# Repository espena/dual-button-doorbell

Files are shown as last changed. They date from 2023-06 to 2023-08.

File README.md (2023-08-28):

# Dual-button doorbell

*V. 1.2*

A door bell that simply does more. Configurable with alarms, different sounds for the two buttons, bedtime LED indicator and timed notifications on specific days / hours. With audible 4Ω loudspeaker driven by a class D 3.2 W amplifier.

The project is described on my [home page](https://espenandersen.no/dual-button-doorbell/).

## Features

- Two-button interface with led indicators
- Personalized doorbell sound from custom wav files
- Cron calendar for scheduling sounds down to one second resolution
- SD card support for storing audio files and configuration
- WiFi interface with integrated antenna
- MQTT support for smart home integration and push notifications
- Battery backed-up real-time clock
- Time automatically set over the network using NTP
- Can be configured to use custom time zones
- Silent mode with alternate bell sounds during night hours
- Relay for triggering external doorbell along with custom sound
- Accepts AC or DC power input from existing doorbell power supplies

## Circuit

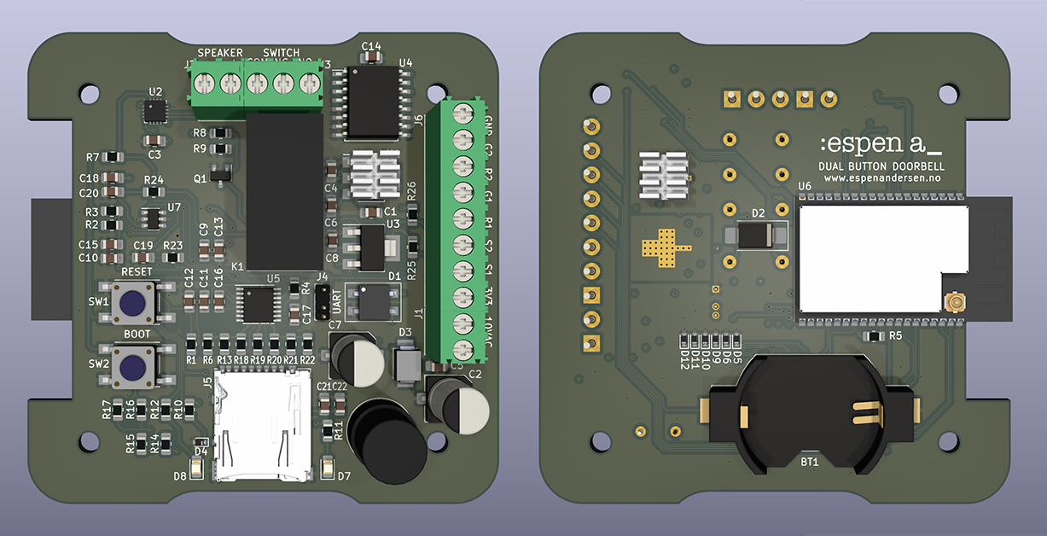
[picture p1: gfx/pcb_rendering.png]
PCB layout PCB rendering


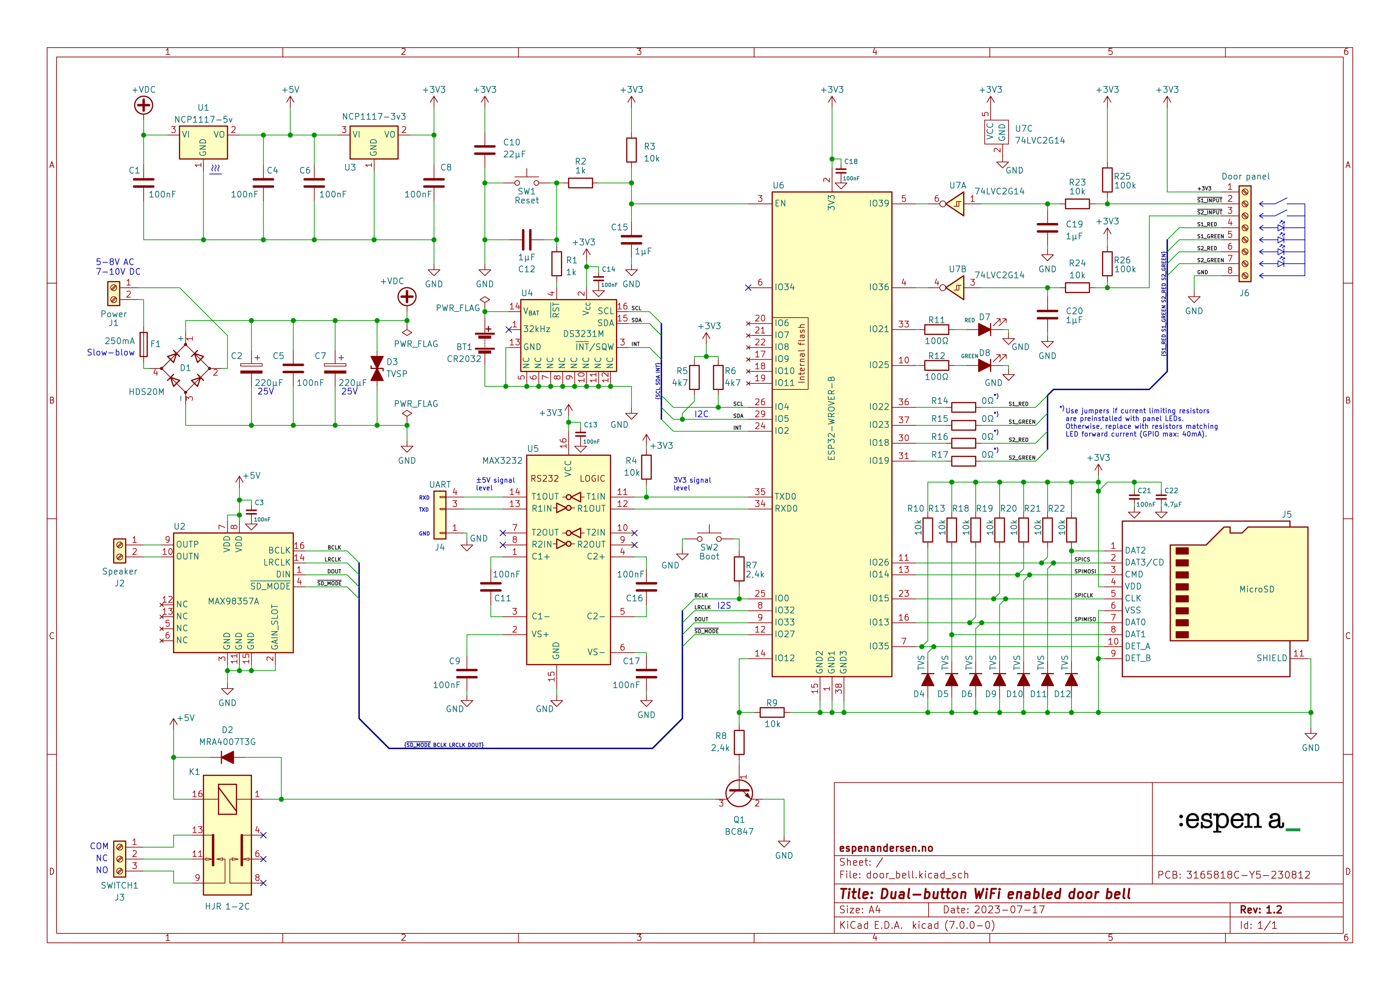
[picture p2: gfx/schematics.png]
Circuit schematics


Custom symbols, footprints and 3D models can be found in [espena/kicad-libs](https://github.com/espena/kicad-libs) whenever they're ready.

## Firmware

Written in C/C++ using [FreeRTOS](https://www.freertos.org/) and [ESP-IDF](https://docs.espressif.com/projects/esp-idf/en/latest/esp32/get-started/). Additionally I use the brilliant [ccronexpr](https://github.com/staticlibs/ccronexpr) C library for parsing the cron-alike sound schedule. Source code is located in the [firmware/dual-button-doorbell](firmware/dual-button-doorbell) folder within this repository.

## Configuration

Configuration and assets must be stored on the SD card. See [/firmware/dual-button-doorbell/sdcard](/firmware/dual-button-doorbell/sdcard) for an example configuration.

## Button panel

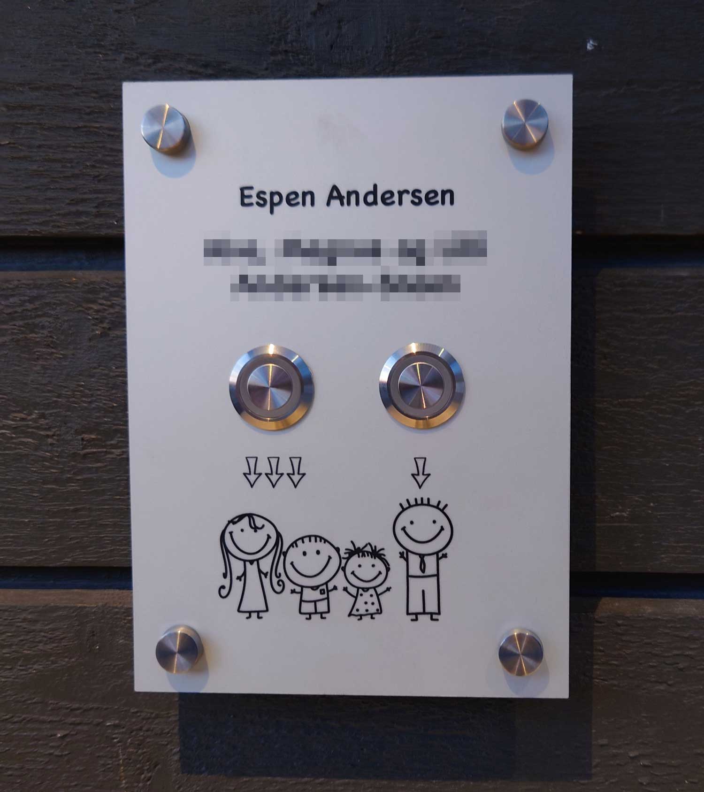
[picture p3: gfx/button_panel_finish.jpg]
Button panel design Button panel finished design


## Panel back side enclosure

```stl
solid Mesh
  facet normal 0.000000 1.000000 0.000000
    outer loop
      vertex 50.000000 30.000000 0.000000
      vertex -50.000000 30.000000 0.000000
      vertex -50.000000 30.000000 19.000000
    endloop
  endfacet
  facet normal 0.000000 1.000000 -0.000000
    outer loop
      vertex 50.000000 30.000000 0.000000
      vertex -50.000000 30.000000 19.000000
      vertex 50.000000 30.000000 19.000000
    endloop
  endfacet
  facet normal -1.000000 -0.000000 0.000000
    outer loop
      vertex -50.000000 30.000000 19.000000
      vertex -50.000000 -30.000000 0.000000
      vertex -50.000000 -30.000000 19.000000
    endloop
  endfacet
  facet normal -1.000000 0.000000 0.000000
    outer loop
      vertex -50.000000 30.000000 0.000000
      vertex -50.000000 -30.000000 0.000000
      vertex -50.000000 30.000000 19.000000
    endloop
  endfacet
  facet normal 1.000000 -0.000000 0.000000
    outer loop
      vertex 50.000000 -30.000000 19.000000
      vertex 50.000000 30.000000 0.000000
      vertex 50.000000 30.000000 19.000000
    endloop
  endfacet
  facet normal 1.000000 0.000000 0.000000
    outer loop
      vertex 50.000000 -30.000000 0.000000
      vertex 50.000000 30.000000 0.000000
      vertex 50.000000 -30.000000 19.000000
    endloop
  endfacet
  facet normal 0.000000 0.000000 -1.000000
    outer loop
      vertex -48.000000 -28.000000 0.000000
      vertex -50.000000 30.000000 0.000000
      vertex -48.000000 28.000000 0.000000
    endloop
  endfacet
  facet normal 0.000000 0.000000 -1.000000
    outer loop
      vertex -50.000000 -30.000000 0.000000
      vertex -50.000000 30.000000 0.000000
      vertex -48.000000 -28.000000 0.000000
    endloop
  endfacet
  facet normal 0.000000 0.000000 -1.000000
    outer loop
      vertex -50.000000 -30.000000 0.000000
      vertex 48.000000 -28.000000 0.000000
      vertex 50.000000 -30.000000 0.000000
    endloop
  endfacet
  facet normal 0.000000 -0.000000 -1.000000
    outer loop
      vertex -48.000000 -28.000000 0.000000
      vertex 48.000000 -28.000000 0.000000
      vertex -50.000000 -30.000000 0.000000
    endloop
  endfacet
  facet normal 0.000000 0.000000 -1.000000
    outer loop
      vertex 48.000000 28.000000 0.000000
      vertex 50.000000 30.000000 0.000000
      vertex 48.000000 -28.000000 0.000000
    endloop
  endfacet
  facet normal 0.000000 0.000000 -1.000000
    outer loop
      vertex 48.000000 -28.000000 0.000000
      vertex 50.000000 30.000000 0.000000
      vertex 50.000000 -30.000000 0.000000
    endloop
  endfacet
  facet normal 0.000000 0.000000 -1.000000
    outer loop
      vertex -50.000000 30.000000 0.000000
      vertex 50.000000 30.000000 0.000000
      vertex -48.000000 28.000000 0.000000
    endloop
  endfacet
  facet normal 0.000000 0.000000 -1.000000
    outer loop
      vertex -48.000000 28.000000 0.000000
      vertex 50.000000 30.000000 0.000000
      vertex 48.000000 28.000000 0.000000
    endloop
  endfacet
  facet normal 0.000000 0.000000 1.000000
    outer loop
      vertex -29.796875 -7.549917 19.000000
      vertex -50.000000 -30.000000 19.000000
      vertex -29.410429 -7.946122 19.000000
    endloop
  endfacet
  facet normal 0.000000 0.000000 1.000000
    outer loop
      vertex -29.004713 -8.322572 19.000000
      vertex -29.410429 -7.946122 19.000000
      vertex -50.000000 -30.000000 19.000000
    endloop
  endfacet
  facet normal 0.000000 0.000000 1.000000
    outer loop
      vertex -30.163094 -7.134943 19.000000
      vertex -50.000000 -30.000000 19.000000
      vertex -29.796875 -7.549917 19.000000
    endloop
  endfacet
  facet normal 0.000000 0.000000 1.000000
    outer loop
      vertex -28.580736 -8.678329 19.000000
      vertex -29.004713 -8.322572 19.000000
      vertex -50.000000 -30.000000 19.000000
    endloop
  endfacet
  facet normal 0.000000 0.000000 1.000000
    outer loop
      vertex -30.508171 -6.702229 19.000000
      vertex -50.000000 -30.000000 19.000000
      vertex -30.163094 -7.134943 19.000000
    endloop
  endfacet
  facet normal 0.000000 0.000000 1.000000
    outer loop
      vertex -28.139555 -9.012512 19.000000
      vertex -28.580736 -8.678329 19.000000
      vertex -50.000000 -30.000000 19.000000
    endloop
  endfacet
  facet normal 0.000000 0.000000 1.000000
    outer loop
      vertex -30.831251 -6.252852 19.000000
      vertex -50.000000 -30.000000 19.000000
      vertex -30.508171 -6.702229 19.000000
    endloop
  endfacet
  facet normal 0.000000 0.000000 1.000000
    outer loop
      vertex -27.682264 -9.324287 19.000000
      vertex -28.139555 -9.012512 19.000000
      vertex -50.000000 -30.000000 19.000000
    endloop
  endfacet
  facet normal 0.000000 0.000000 1.000000
    outer loop
      vertex -31.131529 -5.787931 19.000000
      vertex -50.000000 -30.000000 19.000000
      vertex -30.831251 -6.252852 19.000000
    endloop
  endfacet
  facet normal 0.000000 0.000000 1.000000
    outer loop
      vertex -27.209999 -9.612882 19.000000
      vertex -27.682264 -9.324287 19.000000
      vertex -50.000000 -30.000000 19.000000
    endloop
  endfacet
  facet normal 0.000000 0.000000 1.000000
    outer loop
      vertex -31.408260 -5.308619 19.000000
      vertex -50.000000 -30.000000 19.000000
      vertex -31.131529 -5.787931 19.000000
    endloop
  endfacet
  facet normal 0.000000 0.000000 1.000000
    outer loop
      vertex -26.723938 -9.877577 19.000000
      vertex -27.209999 -9.612882 19.000000
      vertex -50.000000 -30.000000 19.000000
    endloop
  endfacet
  facet normal 0.000000 0.000000 1.000000
    outer loop
      vertex -31.660755 -4.816110 19.000000
      vertex -50.000000 -30.000000 19.000000
      vertex -31.408260 -5.308619 19.000000
    endloop
  endfacet
  facet normal 0.000000 0.000000 1.000000
    outer loop
      vertex -26.225286 -10.117715 19.000000
      vertex -26.723938 -9.877577 19.000000
      vertex -50.000000 -30.000000 19.000000
    endloop
  endfacet
  facet normal 0.000000 0.000000 1.000000
    outer loop
      vertex -31.888386 -4.311626 19.000000
      vertex -50.000000 -30.000000 19.000000
      vertex -31.660755 -4.816110 19.000000
    endloop
  endfacet
  facet normal 0.000000 0.000000 1.000000
    outer loop
      vertex -25.715286 -10.332699 19.000000
      vertex -26.225286 -10.117715 19.000000
      vertex -50.000000 -30.000000 19.000000
    endloop
  endfacet
  facet normal 0.000000 0.000000 1.000000
    outer loop
      vertex -32.090588 -3.796424 19.000000
      vertex -50.000000 -30.000000 19.000000
      vertex -31.888386 -4.311626 19.000000
    endloop
  endfacet
  facet normal 0.000000 0.000000 1.000000
    outer loop
      vertex -25.195202 -10.521994 19.000000
      vertex -25.715286 -10.332699 19.000000
      vertex -50.000000 -30.000000 19.000000
    endloop
  endfacet
  facet normal 0.000000 0.000000 1.000000
    outer loop
      vertex -32.266857 -3.271782 19.000000
      vertex -50.000000 -30.000000 19.000000
      vertex -32.090588 -3.796424 19.000000
    endloop
  endfacet
  facet normal 0.000000 0.000000 1.000000
    outer loop
      vertex -24.666328 -10.685129 19.000000
      vertex -25.195202 -10.521994 19.000000
      vertex -50.000000 -30.000000 19.000000
    endloop
  endfacet
  facet normal 0.000000 0.000000 1.000000
    outer loop
      vertex -32.416759 -2.739007 19.000000
      vertex -50.000000 -30.000000 19.000000
      vertex -32.266857 -3.271782 19.000000
    endloop
  endfacet
  facet normal 0.000000 0.000000 1.000000
    outer loop
      vertex -24.129982 -10.821700 19.000000
      vertex -24.666328 -10.685129 19.000000
      vertex -50.000000 -30.000000 19.000000
    endloop
  endfacet
  facet normal 0.000000 0.000000 1.000000
    outer loop
      vertex -32.539913 -2.199422 19.000000
      vertex -50.000000 -30.000000 19.000000
      vertex -32.416759 -2.739007 19.000000
    endloop
  endfacet
  facet normal 0.000000 0.000000 1.000000
    outer loop
      vertex -23.587494 -10.931366 19.000000
      vertex -24.129982 -10.821700 19.000000
      vertex -50.000000 -30.000000 19.000000
    endloop
  endfacet
  facet normal 0.000000 0.000000 1.000000
    outer loop
      vertex -32.636021 -1.654369 19.000000
      vertex -50.000000 -30.000000 19.000000
      vertex -32.539913 -2.199422 19.000000
    endloop
  endfacet
  facet normal 0.000000 0.000000 1.000000
    outer loop
      vertex -23.040215 -11.013855 19.000000
      vertex -23.587494 -10.931366 19.000000
      vertex -50.000000 -30.000000 19.000000
    endloop
  endfacet
  facet normal 0.000000 0.000000 1.000000
    outer loop
      vertex -32.704842 -1.105203 19.000000
      vertex -50.000000 -30.000000 19.000000
      vertex -32.636021 -1.654369 19.000000
    endloop
  endfacet
  facet normal 0.000000 0.000000 1.000000
    outer loop
      vertex -22.489504 -11.068962 19.000000
      vertex -23.040215 -11.013855 19.000000
      vertex -50.000000 -30.000000 19.000000
    endloop
  endfacet
  facet normal 0.000000 0.000000 1.000000
    outer loop
      vertex -32.746201 -0.553289 19.000000
      vertex -50.000000 -30.000000 19.000000
      vertex -32.704842 -1.105203 19.000000
    endloop
  endfacet
  facet normal 0.000000 0.000000 1.000000
    outer loop
      vertex -21.936731 -11.096550 19.000000
      vertex -22.489504 -11.068962 19.000000
      vertex -50.000000 -30.000000 19.000000
    endloop
  endfacet
  facet normal 0.000000 0.000000 1.000000
    outer loop
      vertex -32.759998 0.000000 19.000000
      vertex -50.000000 -30.000000 19.000000
      vertex -32.746201 -0.553289 19.000000
    endloop
  endfacet
  facet normal 0.000000 0.000000 1.000000
    outer loop
      vertex -21.383270 -11.096550 19.000000
      vertex -21.936731 -11.096550 19.000000
      vertex -50.000000 -30.000000 19.000000
    endloop
  endfacet
  facet normal 0.000000 0.000000 1.000000
    outer loop
      vertex -20.830496 -11.068962 19.000000
      vertex -21.383270 -11.096550 19.000000
      vertex -50.000000 -30.000000 19.000000
    endloop
  endfacet
  facet normal 0.000000 0.000000 1.000000
    outer loop
      vertex -20.279785 -11.013855 19.000000
      vertex -20.830496 -11.068962 19.000000
      vertex -50.000000 -30.000000 19.000000
    endloop
  endfacet
  facet normal 0.000000 0.000000 1.000000
    outer loop
      vertex -19.732506 -10.931366 19.000000
      vertex -20.279785 -11.013855 19.000000
      vertex -50.000000 -30.000000 19.000000
    endloop
  endfacet
  facet normal 0.000000 0.000000 1.000000
    outer loop
      vertex -19.190018 -10.821700 19.000000
      vertex -19.732506 -10.931366 19.000000
      vertex -50.000000 -30.000000 19.000000
    endloop
  endfacet
  facet normal 0.000000 0.000000 1.000000
    outer loop
      vertex -18.653671 -10.685129 19.000000
      vertex -19.190018 -10.821700 19.000000
      vertex -50.000000 -30.000000 19.000000
    endloop
  endfacet
  facet normal 0.000000 0.000000 1.000000
    outer loop
      vertex -50.000000 30.000000 19.000000
      vertex -50.000000 -30.000000 19.000000
      vertex -32.759998 0.000000 19.000000
    endloop
  endfacet
  facet normal 0.000000 0.000000 1.000000
    outer loop
      vertex -50.000000 30.000000 19.000000
      vertex -32.759998 0.000000 19.000000
      vertex -32.746201 0.553289 19.000000
    endloop
  endfacet
  facet normal 0.000000 0.000000 1.000000
    outer loop
      vertex -50.000000 30.000000 19.000000
      vertex -32.746201 0.553289 19.000000
      vertex -32.704842 1.105203 19.000000
    endloop
  endfacet
  facet normal 0.000000 0.000000 1.000000
    outer loop
      vertex -50.000000 30.000000 19.000000
      vertex -32.704842 1.105203 19.000000
      vertex -32.636021 1.654369 19.000000
    endloop
  endfacet
  facet normal 0.000000 0.000000 1.000000
    outer loop
      vertex -50.000000 30.000000 19.000000
      vertex -32.636021 1.654369 19.000000
      vertex -32.539913 2.199422 19.000000
    endloop
  endfacet
  facet normal 0.000000 0.000000 1.000000
    outer loop
      vertex -50.000000 30.000000 19.000000
      vertex -32.539913 2.199422 19.000000
      vertex -32.416759 2.739007 19.000000
    endloop
  endfacet
  facet normal 0.000000 0.000000 1.000000
    outer loop
      vertex -50.000000 30.000000 19.000000
      vertex -32.416759 2.739007 19.000000
      vertex -32.266857 3.271782 19.000000
    endloop
  endfacet
  facet normal 0.000000 0.000000 1.000000
    outer loop
      vertex -50.000000 30.000000 19.000000
      vertex -32.266857 3.271782 19.000000
      vertex -32.090588 3.796424 19.000000
    endloop
  endfacet
  facet normal 0.000000 0.000000 1.000000
    outer loop
      vertex -50.000000 30.000000 19.000000
      vertex -32.090588 3.796424 19.000000
      vertex -31.888386 4.311626 19.000000
    endloop
  endfacet
  facet normal 0.000000 0.000000 1.000000
    outer loop
      vertex -50.000000 30.000000 19.000000
      vertex -31.888386 4.311626 19.000000
      vertex -31.660755 4.816110 19.000000
    endloop
  endfacet
  facet normal 0.000000 0.000000 1.000000
    outer loop
      vertex -50.000000 30.000000 19.000000
      vertex -31.660755 4.816110 19.000000
      vertex -31.408260 5.308619 19.000000
    endloop
  endfacet
  facet normal 0.000000 0.000000 1.000000
    outer loop
      vertex -50.000000 30.000000 19.000000
      vertex -31.408260 5.308619 19.000000
      vertex -31.131529 5.787931 19.000000
    endloop
  endfacet
  facet normal 0.000000 0.000000 1.000000
    outer loop
      vertex -50.000000 30.000000 19.000000
      vertex -31.131529 5.787931 19.000000
      vertex -30.831251 6.252852 19.000000
    endloop
  endfacet
  facet normal 0.000000 0.000000 1.000000
    outer loop
      vertex -50.000000 30.000000 19.000000
      vertex -30.831251 6.252852 19.000000
      vertex -30.508171 6.702229 19.000000
    endloop
  endfacet
  facet normal 0.000000 0.000000 1.000000
    outer loop
      vertex -50.000000 30.000000 19.000000
      vertex -30.508171 6.702229 19.000000
      vertex -30.163094 7.134943 19.000000
    endloop
  endfacet
  facet normal 0.000000 0.000000 1.000000
    outer loop
      vertex -50.000000 30.000000 19.000000
      vertex -30.163094 7.134943 19.000000
      vertex -29.796875 7.549917 19.000000
    endloop
  endfacet
  facet normal 0.000000 0.000000 1.000000
    outer loop
      vertex -50.000000 30.000000 19.000000
      vertex -29.796875 7.549917 19.000000
      vertex -29.410429 7.946122 19.000000
    endloop
  endfacet
  facet normal 0.000000 0.000000 1.000000
    outer loop
      vertex -50.000000 30.000000 19.000000
      vertex -29.410429 7.946122 19.000000
      vertex -29.004713 8.322572 19.000000
    endloop
  endfacet
  facet normal 0.000000 0.000000 1.000000
    outer loop
      vertex -28.580736 8.678329 19.000000
      vertex -50.000000 30.000000 19.000000
      vertex -29.004713 8.322572 19.000000
    endloop
  endfacet
  facet normal 0.000000 0.000000 1.000000
    outer loop
      vertex -28.139555 9.012512 19.000000
      vertex -50.000000 30.000000 19.000000
      vertex -28.580736 8.678329 19.000000
    endloop
  endfacet
  facet normal 0.000000 0.000000 1.000000
    outer loop
      vertex -27.682264 9.324287 19.000000
      vertex -50.000000 30.000000 19.000000
      vertex -28.139555 9.012512 19.000000
    endloop
  endfacet
  facet normal 0.000000 0.000000 1.000000
    outer loop
      vertex -27.209999 9.612882 19.000000
      vertex -50.000000 30.000000 19.000000
      vertex -27.682264 9.324287 19.000000
    endloop
  endfacet
  facet normal 0.000000 0.000000 1.000000
    outer loop
      vertex -26.723938 9.877577 19.000000
      vertex -50.000000 30.000000 19.000000
      vertex -27.209999 9.612882 19.000000
    endloop
  endfacet
  facet normal 0.000000 0.000000 1.000000
    outer loop
      vertex -26.225286 10.117715 19.000000
      vertex -50.000000 30.000000 19.000000
      vertex -26.723938 9.877577 19.000000
    endloop
  endfacet
  facet normal 0.000000 0.000000 1.000000
    outer loop
      vertex -25.715286 10.332699 19.000000
      vertex -50.000000 30.000000 19.000000
      vertex -26.225286 10.117715 19.000000
    endloop
  endfacet
  facet normal 0.000000 0.000000 1.000000
    outer loop
      vertex -25.195202 10.521994 19.000000
      vertex -50.000000 30.000000 19.000000
      vertex -25.715286 10.332699 19.000000
    endloop
  endfacet
  facet normal 0.000000 0.000000 1.000000
    outer loop
      vertex -24.666328 10.685129 19.000000
      vertex -50.000000 30.000000 19.000000
      vertex -25.195202 10.521994 19.000000
    endloop
  endfacet
  facet normal 0.000000 0.000000 1.000000
    outer loop
      vertex -24.129982 10.821700 19.000000
      vertex -50.000000 30.000000 19.000000
      vertex -24.666328 10.685129 19.000000
    endloop
  endfacet
  facet normal 0.000000 0.000000 1.000000
    outer loop
      vertex -23.587494 10.931366 19.000000
      vertex -50.000000 30.000000 19.000000
      vertex -24.129982 10.821700 19.000000
    endloop
  endfacet
  facet normal 0.000000 0.000000 1.000000
    outer loop
      vertex -23.040215 11.013855 19.000000
      vertex -50.000000 30.000000 19.000000
      vertex -23.587494 10.931366 19.000000
    endloop
  endfacet
  facet normal 0.000000 0.000000 1.000000
    outer loop
      vertex -22.489504 11.068962 19.000000
      vertex -50.000000 30.000000 19.000000
      vertex -23.040215 11.013855 19.000000
    endloop
  endfacet
  facet normal 0.000000 0.000000 1.000000
    outer loop
      vertex -21.936731 11.096550 19.000000
      vertex -50.000000 30.000000 19.000000
      vertex -22.489504 11.068962 19.000000
    endloop
  endfacet
  facet normal 0.000000 0.000000 1.000000
    outer loop
      vertex -21.383270 11.096550 19.000000
      vertex -50.000000 30.000000 19.000000
      vertex -21.936731 11.096550 19.000000
    endloop
  endfacet
  facet normal 0.000000 0.000000 1.000000
    outer loop
      vertex -20.830496 11.068962 19.000000
      vertex -50.000000 30.000000 19.000000
      vertex -21.383270 11.096550 19.000000
    endloop
  endfacet
  facet normal 0.000000 0.000000 1.000000
    outer loop
      vertex -20.279785 11.013855 19.000000
      vertex -50.000000 30.000000 19.000000
      vertex -20.830496 11.068962 19.000000
    endloop
  endfacet
  facet normal 0.000000 0.000000 1.000000
    outer loop
      vertex -19.732506 10.931366 19.000000
      vertex -50.000000 30.000000 19.000000
      vertex -20.279785 11.013855 19.000000
    endloop
  endfacet
  facet normal 0.000000 0.000000 1.000000
    outer loop
      vertex -19.190018 10.821700 19.000000
      vertex -50.000000 30.000000 19.000000
      vertex -19.732506 10.931366 19.000000
    endloop
  endfacet
  facet normal 0.000000 0.000000 1.000000
    outer loop
      vertex 13.522124 -7.549917 19.000000
      vertex -13.909572 -7.946122 19.000000
      vertex 13.908571 -7.946122 19.000000
    endloop
  endfacet
  facet normal 0.000000 0.000000 1.000000
    outer loop
      vertex 13.522124 -7.549917 19.000000
      vertex -13.523125 -7.549917 19.000000
      vertex -13.909572 -7.946122 19.000000
    endloop
  endfacet
  facet normal 0.000000 0.000000 1.000000
    outer loop
      vertex 14.314287 -8.322572 19.000000
      vertex 13.908571 -7.946122 19.000000
      vertex -13.909572 -7.946122 19.000000
    endloop
  endfacet
  facet normal 0.000000 0.000000 1.000000
    outer loop
      vertex 14.314287 -8.322572 19.000000
      vertex -13.909572 -7.946122 19.000000
      vertex -14.315288 -8.322572 19.000000
    endloop
  endfacet
  facet normal 0.000000 0.000000 1.000000
    outer loop
      vertex 14.314287 -8.322572 19.000000
      vertex -14.315288 -8.322572 19.000000
      vertex -14.739264 -8.678329 19.000000
    endloop
  endfacet
  facet normal 0.000000 0.000000 1.000000
    outer loop
      vertex 13.155907 -7.134943 19.000000
      vertex -12.811830 -6.702229 19.000000
      vertex -13.156907 -7.134943 19.000000
    endloop
  endfacet
  facet normal 0.000000 0.000000 1.000000
    outer loop
      vertex 13.155907 -7.134943 19.000000
      vertex -13.156907 -7.134943 19.000000
      vertex -13.523125 -7.549917 19.000000
    endloop
  endfacet
  facet normal 0.000000 0.000000 1.000000
    outer loop
      vertex 13.155907 -7.134943 19.000000
      vertex -13.523125 -7.549917 19.000000
      vertex 13.522124 -7.549917 19.000000
    endloop
  endfacet
  facet normal 0.000000 0.000000 1.000000
    outer loop
      vertex 14.738263 -8.678329 19.000000
      vertex 14.314287 -8.322572 19.000000
      vertex -14.739264 -8.678329 19.000000
    endloop
  endfacet
  facet normal 0.000000 0.000000 1.000000
    outer loop
      vertex 12.810829 -6.702229 19.000000
      vertex -12.811830 -6.702229 19.000000
      vertex 13.155907 -7.134943 19.000000
    endloop
  endfacet
  facet normal 0.000000 0.000000 1.000000
    outer loop
      vertex 15.179445 -9.012512 19.000000
      vertex -14.739264 -8.678329 19.000000
      vertex -15.180446 -9.012512 19.000000
    endloop
  endfacet
  facet normal 0.000000 0.000000 1.000000
    outer loop
      vertex 15.179445 -9.012512 19.000000
      vertex -15.180446 -9.012512 19.000000
      vertex -15.637736 -9.324287 19.000000
    endloop
  endfacet
  facet normal 0.000000 0.000000 1.000000
    outer loop
      vertex 15.179445 -9.012512 19.000000
      vertex 14.738263 -8.678329 19.000000
      vertex -14.739264 -8.678329 19.000000
    endloop
  endfacet
  facet normal 0.000000 0.000000 1.000000
    outer loop
      vertex 12.487750 -6.252852 19.000000
      vertex -12.488750 -6.252852 19.000000
      vertex -12.811830 -6.702229 19.000000
    endloop
  endfacet
  facet normal 0.000000 0.000000 1.000000
    outer loop
      vertex 12.487750 -6.252852 19.000000
      vertex -12.811830 -6.702229 19.000000
      vertex 12.810829 -6.702229 19.000000
    endloop
  endfacet
  facet normal 0.000000 0.000000 1.000000
    outer loop
      vertex 15.636737 -9.324287 19.000000
      vertex 15.179445 -9.012512 19.000000
      vertex -15.637736 -9.324287 19.000000
    endloop
  endfacet
  facet normal 0.000000 0.000000 1.000000
    outer loop
      vertex 12.187471 -5.787931 19.000000
      vertex -11.911740 -5.308619 19.000000
      vertex -12.188471 -5.787931 19.000000
    endloop
  endfacet
  facet normal 0.000000 0.000000 1.000000
    outer loop
      vertex 12.187471 -5.787931 19.000000
      vertex -12.188471 -5.787931 19.000000
      vertex -12.488750 -6.252852 19.000000
    endloop
  endfacet
  facet normal 0.000000 0.000000 1.000000
    outer loop
      vertex 12.187471 -5.787931 19.000000
      vertex -12.488750 -6.252852 19.000000
      vertex 12.487750 -6.252852 19.000000
    endloop
  endfacet
  facet normal 0.000000 0.000000 1.000000
    outer loop
      vertex 16.108999 -9.612882 19.000000
      vertex -15.637736 -9.324287 19.000000
      vertex -16.110001 -9.612882 19.000000
    endloop
  endfacet
  facet normal 0.000000 0.000000 1.000000
    outer loop
      vertex 16.108999 -9.612882 19.000000
      vertex 15.636737 -9.324287 19.000000
      vertex -15.637736 -9.324287 19.000000
    endloop
  endfacet
  facet normal 0.000000 0.000000 1.000000
    outer loop
      vertex 11.910741 -5.308619 19.000000
      vertex -11.911740 -5.308619 19.000000
      vertex 12.187471 -5.787931 19.000000
    endloop
  endfacet
  facet normal 0.000000 0.000000 1.000000
    outer loop
      vertex 16.595062 -9.877577 19.000000
      vertex 16.108999 -9.612882 19.000000
      vertex -16.110001 -9.612882 19.000000
    endloop
  endfacet
  facet normal 0.000000 0.000000 1.000000
    outer loop
      vertex 16.595062 -9.877577 19.000000
      vertex -16.110001 -9.612882 19.000000
      vertex -16.596062 -9.877577 19.000000
    endloop
  endfacet
  facet normal 0.000000 0.000000 1.000000
    outer loop
      vertex 11.658246 -4.816110 19.000000
      vertex -11.659245 -4.816110 19.000000
      vertex -11.911740 -5.308619 19.000000
    endloop
  endfacet
  facet normal 0.000000 0.000000 1.000000
    outer loop
      vertex 11.658246 -4.816110 19.000000
      vertex -11.911740 -5.308619 19.000000
      vertex 11.910741 -5.308619 19.000000
    endloop
  endfacet
  facet normal 0.000000 0.000000 1.000000
    outer loop
      vertex 17.093714 -10.117715 19.000000
      vertex -16.596062 -9.877577 19.000000
      vertex -17.094713 -10.117715 19.000000
    endloop
  endfacet
  facet normal 0.000000 0.000000 1.000000
    outer loop
      vertex 17.093714 -10.117715 19.000000
      vertex 16.595062 -9.877577 19.000000
      vertex -16.596062 -9.877577 19.000000
    endloop
  endfacet
  facet normal 0.000000 0.000000 1.000000
    outer loop
      vertex 11.430614 -4.311626 19.000000
      vertex -11.431614 -4.311626 19.000000
      vertex -11.659245 -4.816110 19.000000
    endloop
  endfacet
  facet normal 0.000000 0.000000 1.000000
    outer loop
      vertex 11.430614 -4.311626 19.000000
      vertex -11.659245 -4.816110 19.000000
      vertex 11.658246 -4.816110 19.000000
    endloop
  endfacet
  facet normal 0.000000 0.000000 1.000000
    outer loop
      vertex 17.603714 -10.332699 19.000000
      vertex -17.094713 -10.117715 19.000000
      vertex -17.604715 -10.332699 19.000000
    endloop
  endfacet
  facet normal 0.000000 0.000000 1.000000
    outer loop
      vertex 17.603714 -10.332699 19.000000
      vertex 17.093714 -10.117715 19.000000
      vertex -17.094713 -10.117715 19.000000
    endloop
  endfacet
  facet normal 0.000000 0.000000 1.000000
    outer loop
      vertex 11.228412 -3.796424 19.000000
      vertex -11.053142 -3.271782 19.000000
      vertex -11.229412 -3.796424 19.000000
    endloop
  endfacet
  facet normal 0.000000 0.000000 1.000000
    outer loop
      vertex 11.228412 -3.796424 19.000000
      vertex -11.229412 -3.796424 19.000000
      vertex -11.431614 -4.311626 19.000000
    endloop
  endfacet
  facet normal 0.000000 0.000000 1.000000
    outer loop
      vertex 11.228412 -3.796424 19.000000
      vertex -11.431614 -4.311626 19.000000
      vertex 11.430614 -4.311626 19.000000
    endloop
  endfacet
  facet normal 0.000000 0.000000 1.000000
    outer loop
      vertex 18.123798 -10.521994 19.000000
      vertex -17.604715 -10.332699 19.000000
      vertex -18.124798 -10.521994 19.000000
    endloop
  endfacet
  facet normal 0.000000 0.000000 1.000000
    outer loop
      vertex 18.123798 -10.521994 19.000000
      vertex 17.603714 -10.332699 19.000000
      vertex -17.604715 -10.332699 19.000000
    endloop
  endfacet
  facet normal 0.000000 0.000000 1.000000
    outer loop
      vertex 11.052142 -3.271782 19.000000
      vertex -11.053142 -3.271782 19.000000
      vertex 11.228412 -3.796424 19.000000
    endloop
  endfacet
  facet normal 0.000000 0.000000 1.000000
    outer loop
      vertex 18.652670 -10.685129 19.000000
      vertex -18.124798 -10.521994 19.000000
      vertex -18.653671 -10.685129 19.000000
    endloop
  endfacet
  facet normal 0.000000 0.000000 1.000000
    outer loop
      vertex 18.652670 -10.685129 19.000000
      vertex -18.653671 -10.685129 19.000000
      vertex -50.000000 -30.000000 19.000000
    endloop
  endfacet
  facet normal 0.000000 0.000000 1.000000
    outer loop
      vertex 18.652670 -10.685129 19.000000
      vertex 18.123798 -10.521994 19.000000
      vertex -18.124798 -10.521994 19.000000
    endloop
  endfacet
  facet normal 0.000000 0.000000 1.000000
    outer loop
      vertex 10.902242 -2.739007 19.000000
      vertex -10.903242 -2.739007 19.000000
      vertex -11.053142 -3.271782 19.000000
    endloop
  endfacet
  facet normal 0.000000 0.000000 1.000000
    outer loop
      vertex 10.902242 -2.739007 19.000000
      vertex -11.053142 -3.271782 19.000000
      vertex 11.052142 -3.271782 19.000000
    endloop
  endfacet
  facet normal 0.000000 0.000000 1.000000
    outer loop
      vertex 10.779085 -2.199422 19.000000
      vertex -10.780086 -2.199422 19.000000
      vertex -10.903242 -2.739007 19.000000
    endloop
  endfacet
  facet normal 0.000000 0.000000 1.000000
    outer loop
      vertex 10.779085 -2.199422 19.000000
      vertex -10.903242 -2.739007 19.000000
      vertex 10.902242 -2.739007 19.000000
    endloop
  endfacet
  facet normal 0.000000 0.000000 1.000000
    outer loop
      vertex 10.682978 -1.654369 19.000000
      vertex -10.683978 -1.654369 19.000000
      vertex -10.780086 -2.199422 19.000000
    endloop
  endfacet
  facet normal 0.000000 0.000000 1.000000
    outer loop
      vertex 10.682978 -1.654369 19.000000
      vertex -10.780086 -2.199422 19.000000
      vertex 10.779085 -2.199422 19.000000
    endloop
  endfacet
  facet normal 0.000000 0.000000 1.000000
    outer loop
      vertex 10.614159 -1.105203 19.000000
      vertex -10.573798 -0.553289 19.000000
      vertex -10.615158 -1.105203 19.000000
    endloop
  endfacet
  facet normal 0.000000 0.000000 1.000000
    outer loop
      vertex 10.614159 -1.105203 19.000000
      vertex -10.615158 -1.105203 19.000000
      vertex -10.683978 -1.654369 19.000000
    endloop
  endfacet
  facet normal 0.000000 0.000000 1.000000
    outer loop
      vertex 10.614159 -1.105203 19.000000
      vertex -10.683978 -1.654369 19.000000
      vertex 10.682978 -1.654369 19.000000
    endloop
  endfacet
  facet normal 0.000000 0.000000 1.000000
    outer loop
      vertex 10.572798 -0.553289 19.000000
      vertex -10.573798 -0.553289 19.000000
      vertex 10.614159 -1.105203 19.000000
    endloop
  endfacet
  facet normal 0.000000 0.000000 1.000000
    outer loop
      vertex 10.559000 0.000000 19.000000
      vertex -10.573798 -0.553289 19.000000
      vertex 10.572798 -0.553289 19.000000
    endloop
  endfacet
  facet normal 0.000000 0.000000 1.000000
    outer loop
      vertex 10.559000 0.000000 19.000000
      vertex -10.560000 0.000000 19.000000
      vertex -10.573798 -0.553289 19.000000
    endloop
  endfacet
  facet normal 0.000000 0.000000 1.000000
    outer loop
      vertex 10.572798 0.553289 19.000000
      vertex -10.573798 0.553289 19.000000
      vertex -10.560000 0.000000 19.000000
    endloop
  endfacet
  facet normal 0.000000 0.000000 1.000000
    outer loop
      vertex 10.572798 0.553289 19.000000
      vertex -10.560000 0.000000 19.000000
      vertex 10.559000 0.000000 19.000000
    endloop
  endfacet
  facet normal 0.000000 0.000000 1.000000
    outer loop
      vertex 10.614159 1.105203 19.000000
      vertex -10.683978 1.654369 19.000000
      vertex -10.615158 1.105203 19.000000
    endloop
  endfacet
  facet normal 0.000000 0.000000 1.000000
    outer loop
      vertex 10.614159 1.105203 19.000000
      vertex -10.615158 1.105203 19.000000
      vertex -10.573798 0.553289 19.000000
    endloop
  endfacet
  facet normal 0.000000 0.000000 1.000000
    outer loop
      vertex 10.614159 1.105203 19.000000
      vertex -10.573798 0.553289 19.000000
      vertex 10.572798 0.553289 19.000000
    endloop
  endfacet
  facet normal 0.000000 0.000000 1.000000
    outer loop
      vertex 10.682978 1.654369 19.000000
      vertex -10.683978 1.654369 19.000000
      vertex 10.614159 1.105203 19.000000
    endloop
  endfacet
  facet normal 0.000000 0.000000 1.000000
    outer loop
      vertex 10.682978 1.654369 19.000000
      vertex -10.780086 2.199422 19.000000
      vertex -10.683978 1.654369 19.000000
    endloop
  endfacet
  facet normal 0.000000 0.000000 1.000000
    outer loop
      vertex 10.779085 2.199422 19.000000
      vertex -10.903242 2.739007 19.000000
      vertex -10.780086 2.199422 19.000000
    endloop
  endfacet
  facet normal 0.000000 0.000000 1.000000
    outer loop
      vertex 10.779085 2.199422 19.000000
      vertex -10.780086 2.199422 19.000000
      vertex 10.682978 1.654369 19.000000
    endloop
  endfacet
  facet normal 0.000000 0.000000 1.000000
    outer loop
      vertex 10.902242 2.739007 19.000000
      vertex -10.903242 2.739007 19.000000
      vertex 10.779085 2.199422 19.000000
    endloop
  endfacet
  facet normal 0.000000 0.000000 1.000000
    outer loop
      vertex 10.902242 2.739007 19.000000
      vertex -11.053142 3.271782 19.000000
      vertex -10.903242 2.739007 19.000000
    endloop
  endfacet
  facet normal 0.000000 0.000000 1.000000
    outer loop
      vertex 11.052142 3.271782 19.000000
      vertex -11.229412 3.796424 19.000000
      vertex -11.053142 3.271782 19.000000
    endloop
  endfacet
  facet normal 0.000000 0.000000 1.000000
    outer loop
      vertex 11.052142 3.271782 19.000000
      vertex -11.053142 3.271782 19.000000
      vertex 10.902242 2.739007 19.000000
    endloop
  endfacet
  facet normal 0.000000 0.000000 1.000000
    outer loop
      vertex 11.228412 3.796424 19.000000
      vertex -11.431614 4.311626 19.000000
      vertex -11.229412 3.796424 19.000000
    endloop
  endfacet
  facet normal 0.000000 0.000000 1.000000
    outer loop
      vertex 11.228412 3.796424 19.000000
      vertex -11.229412 3.796424 19.000000
      vertex 11.052142 3.271782 19.000000
    endloop
  endfacet
  facet normal 0.000000 0.000000 1.000000
    outer loop
      vertex 11.430614 4.311626 19.000000
      vertex -11.659245 4.816110 19.000000
      vertex -11.431614 4.311626 19.000000
    endloop
  endfacet
  facet normal 0.000000 0.000000 1.000000
    outer loop
      vertex 11.430614 4.311626 19.000000
      vertex -11.431614 4.311626 19.000000
      vertex 11.228412 3.796424 19.000000
    endloop
  endfacet
  facet normal 0.000000 0.000000 1.000000
    outer loop
      vertex 11.658246 4.816110 19.000000
      vertex -11.911740 5.308619 19.000000
      vertex -11.659245 4.816110 19.000000
    endloop
  endfacet
  facet normal 0.000000 0.000000 1.000000
    outer loop
      vertex 11.658246 4.816110 19.000000
      vertex -11.659245 4.816110 19.000000
      vertex 11.430614 4.311626 19.000000
    endloop
  endfacet
  facet normal 0.000000 0.000000 1.000000
    outer loop
      vertex 11.910741 5.308619 19.000000
      vertex -11.911740 5.308619 19.000000
      vertex 11.658246 4.816110 19.000000
    endloop
  endfacet
  facet normal 0.000000 0.000000 1.000000
    outer loop
      vertex 12.187471 5.787931 19.000000
      vertex -11.911740 5.308619 19.000000
      vertex 11.910741 5.308619 19.000000
    endloop
  endfacet
  facet normal 0.000000 0.000000 1.000000
    outer loop
      vertex 12.187471 5.787931 19.000000
      vertex -12.488750 6.252852 19.000000
      vertex -12.188471 5.787931 19.000000
    endloop
  endfacet
  facet normal 0.000000 0.000000 1.000000
    outer loop
      vertex 12.187471 5.787931 19.000000
      vertex -12.188471 5.787931 19.000000
      vertex -11.911740 5.308619 19.000000
    endloop
  endfacet
  facet normal 0.000000 0.000000 1.000000
    outer loop
      vertex 12.487750 6.252852 19.000000
      vertex -12.488750 6.252852 19.000000
      vertex 12.187471 5.787931 19.000000
    endloop
  endfacet
  facet normal 0.000000 0.000000 1.000000
    outer loop
      vertex 12.810829 6.702229 19.000000
      vertex -13.156907 7.134943 19.000000
      vertex -12.811830 6.702229 19.000000
    endloop
  endfacet
  facet normal 0.000000 0.000000 1.000000
    outer loop
      vertex 12.810829 6.702229 19.000000
      vertex -12.811830 6.702229 19.000000
      vertex -12.488750 6.252852 19.000000
    endloop
  endfacet
  facet normal 0.000000 0.000000 1.000000
    outer loop
      vertex 12.810829 6.702229 19.000000
      vertex -12.488750 6.252852 19.000000
      vertex 12.487750 6.252852 19.000000
    endloop
  endfacet
  facet normal 0.000000 0.000000 1.000000
    outer loop
      vertex 50.000000 -30.000000 19.000000
      vertex 18.652670 -10.685129 19.000000
      vertex -50.000000 -30.000000 19.000000
    endloop
  endfacet
  facet normal 0.000000 0.000000 1.000000
    outer loop
      vertex 50.000000 -30.000000 19.000000
      vertex 28.579737 -8.678329 19.000000
      vertex 28.138556 -9.012512 19.000000
    endloop
  endfacet
  facet normal 0.000000 0.000000 1.000000
    outer loop
      vertex 50.000000 -30.000000 19.000000
      vertex 28.138556 -9.012512 19.000000
      vertex 27.681263 -9.324287 19.000000
    endloop
  endfacet
  facet normal 0.000000 0.000000 1.000000
    outer loop
      vertex 50.000000 -30.000000 19.000000
      vertex 27.681263 -9.324287 19.000000
      vertex 27.209000 -9.612882 19.000000
    endloop
  endfacet
  facet normal 0.000000 0.000000 1.000000
    outer loop
      vertex 50.000000 -30.000000 19.000000
      vertex 27.209000 -9.612882 19.000000
      vertex 26.722939 -9.877577 19.000000
    endloop
  endfacet
  facet normal 0.000000 0.000000 1.000000
    outer loop
      vertex 50.000000 -30.000000 19.000000
      vertex 26.722939 -9.877577 19.000000
      vertex 26.224287 -10.117715 19.000000
    endloop
  endfacet
  facet normal 0.000000 0.000000 1.000000
    outer loop
      vertex 50.000000 -30.000000 19.000000
      vertex 26.224287 -10.117715 19.000000
      vertex 25.714285 -10.332699 19.000000
    endloop
  endfacet
  facet normal 0.000000 0.000000 1.000000
    outer loop
      vertex 50.000000 -30.000000 19.000000
      vertex 25.714285 -10.332699 19.000000
      vertex 25.194202 -10.521994 19.000000
    endloop
  endfacet
  facet normal 0.000000 0.000000 1.000000
    outer loop
      vertex 50.000000 -30.000000 19.000000
      vertex 25.194202 -10.521994 19.000000
      vertex 24.665329 -10.685129 19.000000
    endloop
  endfacet
  facet normal 0.000000 0.000000 1.000000
    outer loop
      vertex 50.000000 -30.000000 19.000000
      vertex 24.665329 -10.685129 19.000000
      vertex 24.128983 -10.821700 19.000000
    endloop
  endfacet
  facet normal 0.000000 0.000000 1.000000
    outer loop
      vertex 50.000000 -30.000000 19.000000
      vertex 24.128983 -10.821700 19.000000
      vertex 23.586494 -10.931366 19.000000
    endloop
  endfacet
  facet normal 0.000000 0.000000 1.000000
    outer loop
      vertex 50.000000 -30.000000 19.000000
      vertex 23.586494 -10.931366 19.000000
      vertex 23.039215 -11.013855 19.000000
    endloop
  endfacet
  facet normal 0.000000 0.000000 1.000000
    outer loop
      vertex 50.000000 -30.000000 19.000000
      vertex 23.039215 -11.013855 19.000000
      vertex 22.488504 -11.068962 19.000000
    endloop
  endfacet
  facet normal 0.000000 0.000000 1.000000
    outer loop
      vertex 50.000000 -30.000000 19.000000
      vertex 22.488504 -11.068962 19.000000
      vertex 21.935730 -11.096550 19.000000
    endloop
  endfacet
  facet normal 0.000000 0.000000 1.000000
    outer loop
      vertex 50.000000 -30.000000 19.000000
      vertex 21.935730 -11.096550 19.000000
      vertex 21.382269 -11.096550 19.000000
    endloop
  endfacet
  facet normal 0.000000 0.000000 1.000000
    outer loop
      vertex 50.000000 -30.000000 19.000000
      vertex 21.382269 -11.096550 19.000000
      vertex 20.829496 -11.068962 19.000000
    endloop
  endfacet
  facet normal 0.000000 0.000000 1.000000
    outer loop
      vertex 50.000000 -30.000000 19.000000
      vertex 20.829496 -11.068962 19.000000
      vertex 20.278786 -11.013855 19.000000
    endloop
  endfacet
  facet normal 0.000000 0.000000 1.000000
    outer loop
      vertex 50.000000 -30.000000 19.000000
      vertex 20.278786 -11.013855 19.000000
      vertex 19.731504 -10.931366 19.000000
    endloop
  endfacet
  facet normal 0.000000 0.000000 1.000000
    outer loop
      vertex 50.000000 -30.000000 19.000000
      vertex 19.731504 -10.931366 19.000000
      vertex 19.189018 -10.821700 19.000000
    endloop
  endfacet
  facet normal 0.000000 0.000000 1.000000
    outer loop
      vertex 50.000000 -30.000000 19.000000
      vertex 19.189018 -10.821700 19.000000
      vertex 18.652670 -10.685129 19.000000
    endloop
  endfacet
  facet normal 0.000000 0.000000 1.000000
    outer loop
      vertex 13.155907 7.134943 19.000000
      vertex -13.156907 7.134943 19.000000
      vertex 12.810829 6.702229 19.000000
    endloop
  endfacet
  facet normal 0.000000 0.000000 1.000000
    outer loop
      vertex 13.155907 7.134943 19.000000
      vertex -13.523125 7.549917 19.000000
      vertex -13.156907 7.134943 19.000000
    endloop
  endfacet
  facet normal 0.000000 0.000000 1.000000
    outer loop
      vertex 29.003714 -8.322572 19.000000
      vertex 28.579737 -8.678329 19.000000
      vertex 50.000000 -30.000000 19.000000
    endloop
  endfacet
  facet normal 0.000000 0.000000 1.000000
    outer loop
      vertex 13.522124 7.549917 19.000000
      vertex -13.523125 7.549917 19.000000
      vertex 13.155907 7.134943 19.000000
    endloop
  endfacet
  facet normal 0.000000 0.000000 1.000000
    outer loop
      vertex 29.409430 -7.946122 19.000000
      vertex 29.003714 -8.322572 19.000000
      vertex 50.000000 -30.000000 19.000000
    endloop
  endfacet
  facet normal 0.000000 0.000000 1.000000
    outer loop
      vertex 13.908571 7.946122 19.000000
      vertex -14.315288 8.322572 19.000000
      vertex -13.909572 7.946122 19.000000
    endloop
  endfacet
  facet normal 0.000000 0.000000 1.000000
    outer loop
      vertex 13.908571 7.946122 19.000000
      vertex -13.909572 7.946122 19.000000
      vertex -13.523125 7.549917 19.000000
    endloop
  endfacet
  facet normal 0.000000 0.000000 1.000000
    outer loop
      vertex 13.908571 7.946122 19.000000
      vertex -13.523125 7.549917 19.000000
      vertex 13.522124 7.549917 19.000000
    endloop
  endfacet
  facet normal 0.000000 0.000000 1.000000
    outer loop
      vertex 29.795876 -7.549917 19.000000
      vertex 29.409430 -7.946122 19.000000
      vertex 50.000000 -30.000000 19.000000
    endloop
  endfacet
  facet normal 0.000000 0.000000 1.000000
    outer loop
      vertex 14.314287 8.322572 19.000000
      vertex -14.315288 8.322572 19.000000
      vertex 13.908571 7.946122 19.000000
    endloop
  endfacet
  facet normal 0.000000 0.000000 1.000000
    outer loop
      vertex 30.162094 -7.134943 19.000000
      vertex 29.795876 -7.549917 19.000000
      vertex 50.000000 -30.000000 19.000000
    endloop
  endfacet
  facet normal 0.000000 0.000000 1.000000
    outer loop
      vertex 14.738263 8.678329 19.000000
      vertex -14.739264 8.678329 19.000000
      vertex -14.315288 8.322572 19.000000
    endloop
  endfacet
  facet normal 0.000000 0.000000 1.000000
    outer loop
      vertex 14.738263 8.678329 19.000000
      vertex -14.315288 8.322572 19.000000
      vertex 14.314287 8.322572 19.000000
    endloop
  endfacet
  facet normal 0.000000 0.000000 1.000000
    outer loop
      vertex 30.507172 -6.702229 19.000000
      vertex 30.162094 -7.134943 19.000000
      vertex 50.000000 -30.000000 19.000000
    endloop
  endfacet
  facet normal 0.000000 0.000000 1.000000
    outer loop
      vertex 15.179445 9.012512 19.000000
      vertex -15.637736 9.324287 19.000000
      vertex -15.180446 9.012512 19.000000
    endloop
  endfacet
  facet normal 0.000000 0.000000 1.000000
    outer loop
      vertex 15.179445 9.012512 19.000000
      vertex -15.180446 9.012512 19.000000
      vertex -14.739264 8.678329 19.000000
    endloop
  endfacet
  facet normal 0.000000 0.000000 1.000000
    outer loop
      vertex 15.179445 9.012512 19.000000
      vertex -14.739264 8.678329 19.000000
      vertex 14.738263 8.678329 19.000000
    endloop
  endfacet
  facet normal 0.000000 0.000000 1.000000
    outer loop
      vertex 30.830250 -6.252852 19.000000
      vertex 30.507172 -6.702229 19.000000
      vertex 50.000000 -30.000000 19.000000
    endloop
  endfacet
  facet normal 0.000000 0.000000 1.000000
    outer loop
      vertex 15.636737 9.324287 19.000000
      vertex -16.110001 9.612882 19.000000
      vertex -15.637736 9.324287 19.000000
    endloop
  endfacet
  facet normal 0.000000 0.000000 1.000000
    outer loop
      vertex 15.636737 9.324287 19.000000
      vertex -15.637736 9.324287 19.000000
      vertex 15.179445 9.012512 19.000000
    endloop
  endfacet
  facet normal 0.000000 0.000000 1.000000
    outer loop
      vertex 31.130529 -5.787931 19.000000
      vertex 30.830250 -6.252852 19.000000
      vertex 50.000000 -30.000000 19.000000
    endloop
  endfacet
  facet normal 0.000000 0.000000 1.000000
    outer loop
      vertex 16.108999 9.612882 19.000000
      vertex -16.596062 9.877577 19.000000
      vertex -16.110001 9.612882 19.000000
    endloop
  endfacet
  facet normal 0.000000 0.000000 1.000000
    outer loop
      vertex 16.108999 9.612882 19.000000
      vertex -16.110001 9.612882 19.000000
      vertex 15.636737 9.324287 19.000000
    endloop
  endfacet
  facet normal 0.000000 0.000000 1.000000
    outer loop
      vertex 31.407259 -5.308619 19.000000
      vertex 31.130529 -5.787931 19.000000
      vertex 50.000000 -30.000000 19.000000
    endloop
  endfacet
  facet normal 0.000000 0.000000 1.000000
    outer loop
      vertex 16.595062 9.877577 19.000000
      vertex -17.094713 10.117715 19.000000
      vertex -16.596062 9.877577 19.000000
    endloop
  endfacet
  facet normal 0.000000 0.000000 1.000000
    outer loop
      vertex 16.595062 9.877577 19.000000
      vertex -16.596062 9.877577 19.000000
      vertex 16.108999 9.612882 19.000000
    endloop
  endfacet
  facet normal 0.000000 0.000000 1.000000
    outer loop
      vertex 31.659754 -4.816110 19.000000
      vertex 31.407259 -5.308619 19.000000
      vertex 50.000000 -30.000000 19.000000
    endloop
  endfacet
  facet normal 0.000000 0.000000 1.000000
    outer loop
      vertex 17.093714 10.117715 19.000000
      vertex -17.094713 10.117715 19.000000
      vertex 16.595062 9.877577 19.000000
    endloop
  endfacet
  facet normal 0.000000 0.000000 1.000000
    outer loop
      vertex 31.887386 -4.311626 19.000000
      vertex 31.659754 -4.816110 19.000000
      vertex 50.000000 -30.000000 19.000000
    endloop
  endfacet
  facet normal 0.000000 0.000000 1.000000
    outer loop
      vertex 17.603714 10.332699 19.000000
      vertex -18.124798 10.521994 19.000000
      vertex -17.604715 10.332699 19.000000
    endloop
  endfacet
  facet normal 0.000000 0.000000 1.000000
    outer loop
      vertex 17.603714 10.332699 19.000000
      vertex -17.604715 10.332699 19.000000
      vertex -17.094713 10.117715 19.000000
    endloop
  endfacet
  facet normal 0.000000 0.000000 1.000000
    outer loop
      vertex 17.603714 10.332699 19.000000
      vertex -17.094713 10.117715 19.000000
      vertex 17.093714 10.117715 19.000000
    endloop
  endfacet
  facet normal 0.000000 0.000000 1.000000
    outer loop
      vertex 32.089588 -3.796424 19.000000
      vertex 31.887386 -4.311626 19.000000
      vertex 50.000000 -30.000000 19.000000
    endloop
  endfacet
  facet normal 0.000000 0.000000 1.000000
    outer loop
      vertex 18.123798 10.521994 19.000000
      vertex -18.124798 10.521994 19.000000
      vertex 17.603714 10.332699 19.000000
    endloop
  endfacet
  facet normal 0.000000 0.000000 1.000000
    outer loop
      vertex 32.265858 -3.271782 19.000000
      vertex 32.089588 -3.796424 19.000000
      vertex 50.000000 -30.000000 19.000000
    endloop
  endfacet
  facet normal 0.000000 0.000000 1.000000
    outer loop
      vertex 32.415756 -2.739007 19.000000
      vertex 32.265858 -3.271782 19.000000
      vertex 50.000000 -30.000000 19.000000
    endloop
  endfacet
  facet normal 0.000000 0.000000 1.000000
    outer loop
      vertex 32.538914 -2.199422 19.000000
      vertex 32.415756 -2.739007 19.000000
      vertex 50.000000 -30.000000 19.000000
    endloop
  endfacet
  facet normal 0.000000 0.000000 1.000000
    outer loop
      vertex 32.635021 -1.654369 19.000000
      vertex 32.538914 -2.199422 19.000000
      vertex 50.000000 -30.000000 19.000000
    endloop
  endfacet
  facet normal 0.000000 0.000000 1.000000
    outer loop
      vertex 32.703842 -1.105203 19.000000
      vertex 32.635021 -1.654369 19.000000
      vertex 50.000000 -30.000000 19.000000
    endloop
  endfacet
  facet normal 0.000000 0.000000 1.000000
    outer loop
      vertex 32.745201 -0.553289 19.000000
      vertex 32.703842 -1.105203 19.000000
      vertex 50.000000 -30.000000 19.000000
    endloop
  endfacet
  facet normal 0.000000 0.000000 1.000000
    outer loop
      vertex 32.758999 0.000000 19.000000
      vertex 32.745201 -0.553289 19.000000
      vertex 50.000000 -30.000000 19.000000
    endloop
  endfacet
  facet normal 0.000000 0.000000 1.000000
    outer loop
      vertex 50.000000 30.000000 19.000000
      vertex 19.189018 10.821700 19.000000
      vertex 19.731504 10.931366 19.000000
    endloop
  endfacet
  facet normal 0.000000 0.000000 1.000000
    outer loop
      vertex 50.000000 30.000000 19.000000
      vertex 19.731504 10.931366 19.000000
      vertex 20.278786 11.013855 19.000000
    endloop
  endfacet
  facet normal 0.000000 0.000000 1.000000
    outer loop
      vertex 50.000000 30.000000 19.000000
      vertex 20.278786 11.013855 19.000000
      vertex 20.829496 11.068962 19.000000
    endloop
  endfacet
  facet normal 0.000000 0.000000 1.000000
    outer loop
      vertex 50.000000 30.000000 19.000000
      vertex 20.829496 11.068962 19.000000
      vertex 21.382269 11.096550 19.000000
    endloop
  endfacet
  facet normal 0.000000 0.000000 1.000000
    outer loop
      vertex 50.000000 30.000000 19.000000
      vertex 21.382269 11.096550 19.000000
      vertex 21.935730 11.096550 19.000000
    endloop
  endfacet
  facet normal 0.000000 0.000000 1.000000
    outer loop
      vertex 50.000000 30.000000 19.000000
      vertex 21.935730 11.096550 19.000000
      vertex 22.488504 11.068962 19.000000
    endloop
  endfacet
  facet normal 0.000000 0.000000 1.000000
    outer loop
      vertex 50.000000 30.000000 19.000000
      vertex 22.488504 11.068962 19.000000
      vertex 23.039215 11.013855 19.000000
    endloop
  endfacet
  facet normal 0.000000 0.000000 1.000000
    outer loop
      vertex 50.000000 30.000000 19.000000
      vertex 23.039215 11.013855 19.000000
      vertex 23.586494 10.931366 19.000000
    endloop
  endfacet
  facet normal 0.000000 0.000000 1.000000
    outer loop
      vertex 50.000000 30.000000 19.000000
      vertex 23.586494 10.931366 19.000000
      vertex 24.128983 10.821700 19.000000
    endloop
  endfacet
  facet normal 0.000000 0.000000 1.000000
    outer loop
      vertex 50.000000 30.000000 19.000000
      vertex 24.128983 10.821700 19.000000
      vertex 24.665329 10.685129 19.000000
    endloop
  endfacet
  facet normal 0.000000 0.000000 1.000000
    outer loop
      vertex 50.000000 30.000000 19.000000
      vertex 24.665329 10.685129 19.000000
      vertex 25.194202 10.521994 19.000000
    endloop
  endfacet
  facet normal 0.000000 0.000000 1.000000
    outer loop
      vertex 50.000000 30.000000 19.000000
      vertex 25.194202 10.521994 19.000000
      vertex 25.714285 10.332699 19.000000
    endloop
  endfacet
  facet normal 0.000000 0.000000 1.000000
    outer loop
      vertex 50.000000 30.000000 19.000000
      vertex 25.714285 10.332699 19.000000
      vertex 26.224287 10.117715 19.000000
    endloop
  endfacet
  facet normal 0.000000 0.000000 1.000000
    outer loop
      vertex 50.000000 30.000000 19.000000
      vertex 26.224287 10.117715 19.000000
      vertex 26.722939 9.877577 19.000000
    endloop
  endfacet
  facet normal 0.000000 0.000000 1.000000
    outer loop
      vertex 50.000000 30.000000 19.000000
      vertex 26.722939 9.877577 19.000000
      vertex 27.209000 9.612882 19.000000
    endloop
  endfacet
  facet normal 0.000000 0.000000 1.000000
    outer loop
      vertex 50.000000 30.000000 19.000000
      vertex 27.209000 9.612882 19.000000
      vertex 27.681263 9.324287 19.000000
    endloop
  endfacet
  facet normal 0.000000 0.000000 1.000000
    outer loop
      vertex 50.000000 30.000000 19.000000
      vertex 27.681263 9.324287 19.000000
      vertex 28.138556 9.012512 19.000000
    endloop
  endfacet
  facet normal 0.000000 0.000000 1.000000
    outer loop
      vertex 50.000000 30.000000 19.000000
      vertex 28.138556 9.012512 19.000000
      vertex 28.579737 8.678329 19.000000
    endloop
  endfacet
  facet normal 0.000000 0.000000 1.000000
    outer loop
      vertex 50.000000 30.000000 19.000000
      vertex 28.579737 8.678329 19.000000
      vertex 29.003714 8.322572 19.000000
    endloop
  endfacet
  facet normal 0.000000 0.000000 1.000000
    outer loop
      vertex 50.000000 30.000000 19.000000
      vertex 29.003714 8.322572 19.000000
      vertex 29.409430 7.946122 19.000000
    endloop
  endfacet
  facet normal 0.000000 0.000000 1.000000
    outer loop
      vertex 50.000000 30.000000 19.000000
      vertex 29.409430 7.946122 19.000000
      vertex 29.795876 7.549917 19.000000
    endloop
  endfacet
  facet normal 0.000000 0.000000 1.000000
    outer loop
      vertex 50.000000 30.000000 19.000000
      vertex 29.795876 7.549917 19.000000
      vertex 30.162094 7.134943 19.000000
    endloop
  endfacet
  facet normal 0.000000 0.000000 1.000000
    outer loop
      vertex 50.000000 30.000000 19.000000
      vertex 30.162094 7.134943 19.000000
      vertex 30.507172 6.702229 19.000000
    endloop
  endfacet
  facet normal 0.000000 0.000000 1.000000
    outer loop
      vertex 50.000000 30.000000 19.000000
      vertex 30.507172 6.702229 19.000000
      vertex 30.830250 6.252852 19.000000
    endloop
  endfacet
  facet normal 0.000000 0.000000 1.000000
    outer loop
      vertex 50.000000 30.000000 19.000000
      vertex 30.830250 6.252852 19.000000
      vertex 31.130529 5.787931 19.000000
    endloop
  endfacet
  facet normal 0.000000 0.000000 1.000000
    outer loop
      vertex 50.000000 30.000000 19.000000
      vertex 31.130529 5.787931 19.000000
      vertex 31.407259 5.308619 19.000000
    endloop
  endfacet
  facet normal 0.000000 0.000000 1.000000
    outer loop
      vertex 50.000000 30.000000 19.000000
      vertex 31.407259 5.308619 19.000000
      vertex 31.659754 4.816110 19.000000
    endloop
  endfacet
  facet normal 0.000000 0.000000 1.000000
    outer loop
      vertex 50.000000 30.000000 19.000000
      vertex 31.659754 4.816110 19.000000
      vertex 31.887386 4.311626 19.000000
    endloop
  endfacet
  facet normal 0.000000 0.000000 1.000000
    outer loop
      vertex 50.000000 30.000000 19.000000
      vertex 31.887386 4.311626 19.000000
      vertex 32.089588 3.796424 19.000000
    endloop
  endfacet
  facet normal 0.000000 0.000000 1.000000
    outer loop
      vertex 50.000000 30.000000 19.000000
      vertex 32.089588 3.796424 19.000000
      vertex 32.265858 3.271782 19.000000
    endloop
  endfacet
  facet normal 0.000000 0.000000 1.000000
    outer loop
      vertex 50.000000 30.000000 19.000000
      vertex 32.265858 3.271782 19.000000
      vertex 32.415756 2.739007 19.000000
    endloop
  endfacet
  facet normal 0.000000 0.000000 1.000000
    outer loop
      vertex 50.000000 30.000000 19.000000
      vertex 32.415756 2.739007 19.000000
      vertex 32.538914 2.199422 19.000000
    endloop
  endfacet
  facet normal 0.000000 0.000000 1.000000
    outer loop
      vertex 50.000000 30.000000 19.000000
      vertex 32.538914 2.199422 19.000000
      vertex 32.635021 1.654369 19.000000
    endloop
  endfacet
  facet normal 0.000000 0.000000 1.000000
    outer loop
      vertex 50.000000 30.000000 19.000000
      vertex 32.635021 1.654369 19.000000
      vertex 32.703842 1.105203 19.000000
    endloop
  endfacet
  facet normal 0.000000 0.000000 1.000000
    outer loop
      vertex 50.000000 30.000000 19.000000
      vertex 32.703842 1.105203 19.000000
      vertex 32.745201 0.553289 19.000000
    endloop
  endfacet
  facet normal 0.000000 0.000000 1.000000
    outer loop
      vertex 50.000000 30.000000 19.000000
      vertex 32.745201 0.553289 19.000000
      vertex 32.758999 0.000000 19.000000
    endloop
  endfacet
  facet normal 0.000000 0.000000 1.000000
    outer loop
      vertex 50.000000 30.000000 19.000000
      vertex 32.758999 0.000000 19.000000
      vertex 50.000000 -30.000000 19.000000
    endloop
  endfacet
  facet normal 0.000000 0.000000 1.000000
    outer loop
      vertex 50.000000 30.000000 19.000000
      vertex -50.000000 30.000000 19.000000
      vertex 19.189018 10.821700 19.000000
    endloop
  endfacet
  facet normal 0.000000 0.000000 1.000000
    outer loop
      vertex 19.189018 10.821700 19.000000
      vertex -50.000000 30.000000 19.000000
      vertex 18.652670 10.685129 19.000000
    endloop
  endfacet
  facet normal 0.000000 0.000000 1.000000
    outer loop
      vertex 18.652670 10.685129 19.000000
      vertex -50.000000 30.000000 19.000000
      vertex 18.123798 10.521994 19.000000
    endloop
  endfacet
  facet normal 0.000000 0.000000 1.000000
    outer loop
      vertex 18.123798 10.521994 19.000000
      vertex -50.000000 30.000000 19.000000
      vertex -18.653671 10.685129 19.000000
    endloop
  endfacet
  facet normal 0.000000 0.000000 1.000000
    outer loop
      vertex -18.653671 10.685129 19.000000
      vertex -50.000000 30.000000 19.000000
      vertex -19.190018 10.821700 19.000000
    endloop
  endfacet
  facet normal 0.000000 0.000000 1.000000
    outer loop
      vertex 18.123798 10.521994 19.000000
      vertex -18.653671 10.685129 19.000000
      vertex -18.124798 10.521994 19.000000
    endloop
  endfacet
  facet normal 0.000000 -1.000000 0.000000
    outer loop
      vertex -50.000000 -30.000000 0.000000
      vertex 50.000000 -30.000000 0.000000
      vertex 50.000000 -30.000000 19.000000
    endloop
  endfacet
  facet normal 0.000000 -1.000000 0.000000
    outer loop
      vertex -50.000000 -30.000000 0.000000
      vertex 50.000000 -30.000000 19.000000
      vertex -50.000000 -30.000000 19.000000
    endloop
  endfacet
  facet normal 1.000000 0.000000 0.000000
    outer loop
      vertex -48.000000 -28.000000 0.000000
      vertex -48.000000 28.000000 0.000000
      vertex -48.000000 -28.000000 17.000000
    endloop
  endfacet
  facet normal 1.000000 -0.000000 0.000000
    outer loop
      vertex -48.000000 -28.000000 17.000000
      vertex -48.000000 28.000000 0.000000
      vertex -48.000000 28.000000 17.000000
    endloop
  endfacet
  facet normal 0.000000 1.000000 -0.000000
    outer loop
      vertex 48.000000 -28.000000 0.000000
      vertex -48.000000 -28.000000 17.000000
      vertex 48.000000 -28.000000 17.000000
    endloop
  endfacet
  facet normal 0.000000 1.000000 0.000000
    outer loop
      vertex 48.000000 -28.000000 0.000000
      vertex -48.000000 -28.000000 0.000000
      vertex -48.000000 -28.000000 17.000000
    endloop
  endfacet
  facet normal -1.000000 0.000000 0.000000
    outer loop
      vertex 48.000000 28.000000 0.000000
      vertex 48.000000 -28.000000 0.000000
      vertex 48.000000 28.000000 17.000000
    endloop
  endfacet
  facet normal -1.000000 -0.000000 0.000000
    outer loop
      vertex 48.000000 28.000000 17.000000
      vertex 48.000000 -28.000000 0.000000
      vertex 48.000000 -28.000000 17.000000
    endloop
  endfacet
  facet normal 0.000000 -1.000000 0.000000
    outer loop
      vertex -48.000000 28.000000 0.000000
      vertex 48.000000 28.000000 17.000000
      vertex -48.000000 28.000000 17.000000
    endloop
  endfacet
  facet normal 0.000000 -1.000000 0.000000
    outer loop
      vertex -48.000000 28.000000 0.000000
      vertex 48.000000 28.000000 0.000000
      vertex 48.000000 28.000000 17.000000
    endloop
  endfacet
  facet normal -0.999689 -0.024930 0.000000
    outer loop
      vertex -10.573798 0.553289 17.000000
      vertex -10.560000 0.000000 17.000000
      vertex -10.560000 0.000000 19.000000
    endloop
  endfacet
  facet normal -0.999689 -0.024930 0.000000
    outer loop
      vertex -10.573798 0.553289 17.000000
      vertex -10.560000 0.000000 19.000000
      vertex -10.573798 0.553289 19.000000
    endloop
  endfacet
  facet normal -0.997204 -0.074730 0.000000
    outer loop
      vertex -10.615158 1.105203 17.000000
      vertex -10.573798 0.553289 19.000000
      vertex -10.615158 1.105203 19.000000
    endloop
  endfacet
  facet normal -0.997204 -0.074730 0.000000
    outer loop
      vertex -10.615158 1.105203 17.000000
      vertex -10.573798 0.553289 17.000000
      vertex -10.573798 0.553289 19.000000
    endloop
  endfacet
  facet normal -0.992239 -0.124345 0.000000
    outer loop
      vertex -10.683978 1.654369 17.000000
      vertex -10.615158 1.105203 19.000000
      vertex -10.683978 1.654369 19.000000
    endloop
  endfacet
  facet normal -0.992239 -0.124345 0.000000
    outer loop
      vertex -10.683978 1.654369 17.000000
      vertex -10.615158 1.105203 17.000000
      vertex -10.615158 1.105203 19.000000
    endloop
  endfacet
  facet normal -0.984808 -0.173648 0.000000
    outer loop
      vertex -10.780086 2.199422 17.000000
      vertex -10.683978 1.654369 19.000000
      vertex -10.780086 2.199422 19.000000
    endloop
  endfacet
  facet normal -0.984808 -0.173648 0.000000
    outer loop
      vertex -10.780086 2.199422 17.000000
      vertex -10.683978 1.654369 17.000000
      vertex -10.683978 1.654369 19.000000
    endloop
  endfacet
  facet normal -0.974928 -0.222521 0.000000
    outer loop
      vertex -10.903242 2.739007 17.000000
      vertex -10.780086 2.199422 19.000000
      vertex -10.903242 2.739007 19.000000
    endloop
  endfacet
  facet normal -0.974928 -0.222521 0.000000
    outer loop
      vertex -10.903242 2.739007 17.000000
      vertex -10.780086 2.199422 17.000000
      vertex -10.780086 2.199422 19.000000
    endloop
  endfacet
  facet normal -0.962624 -0.270840 0.000000
    outer loop
      vertex -11.053142 3.271782 17.000000
      vertex -10.903242 2.739007 19.000000
      vertex -11.053142 3.271782 19.000000
    endloop
  endfacet
  facet normal -0.962624 -0.270840 0.000000
    outer loop
      vertex -11.053142 3.271782 17.000000
      vertex -10.903242 2.739007 17.000000
      vertex -10.903242 2.739007 19.000000
    endloop
  endfacet
  facet normal -0.947927 -0.318487 0.000000
    outer loop
      vertex -11.229412 3.796424 17.000000
      vertex -11.053142 3.271782 19.000000
      vertex -11.229412 3.796424 19.000000
    endloop
  endfacet
  facet normal -0.947927 -0.318487 0.000000
    outer loop
      vertex -11.229412 3.796424 17.000000
      vertex -11.053142 3.271782 17.000000
      vertex -11.053142 3.271782 19.000000
    endloop
  endfacet
  facet normal -0.930874 -0.365340 0.000000
    outer loop
      vertex -11.431614 4.311626 17.000000
      vertex -11.229412 3.796424 19.000000
      vertex -11.431614 4.311626 19.000000
    endloop
  endfacet
  facet normal -0.930874 -0.365340 0.000000
    outer loop
      vertex -11.431614 4.311626 17.000000
      vertex -11.229412 3.796424 17.000000
      vertex -11.229412 3.796424 19.000000
    endloop
  endfacet
  facet normal -0.911506 -0.411287 0.000000
    outer loop
      vertex -11.659245 4.816110 17.000000
      vertex -11.431614 4.311626 19.000000
      vertex -11.659245 4.816110 19.000000
    endloop
  endfacet
  facet normal -0.911506 -0.411287 0.000000
    outer loop
      vertex -11.659245 4.816110 17.000000
      vertex -11.431614 4.311626 17.000000
      vertex -11.431614 4.311626 19.000000
    endloop
  endfacet
  facet normal -0.889872 -0.456211 0.000000
    outer loop
      vertex -11.911740 5.308619 17.000000
      vertex -11.659245 4.816110 19.000000
      vertex -11.911740 5.308619 19.000000
    endloop
  endfacet
  facet normal -0.889872 -0.456211 0.000000
    outer loop
      vertex -11.911740 5.308619 17.000000
      vertex -11.659245 4.816110 17.000000
      vertex -11.659245 4.816110 19.000000
    endloop
  endfacet
  facet normal -0.866026 -0.500000 0.000000
    outer loop
      vertex -12.188471 5.787931 17.000000
      vertex -11.911740 5.308619 17.000000
      vertex -11.911740 5.308619 19.000000
    endloop
  endfacet
  facet normal -0.866026 -0.500000 0.000000
    outer loop
      vertex -12.188471 5.787931 17.000000
      vertex -11.911740 5.308619 19.000000
      vertex -12.188471 5.787931 19.000000
    endloop
  endfacet
  facet normal -0.840025 -0.542547 0.000000
    outer loop
      vertex -12.488750 6.252852 17.000000
      vertex -12.188471 5.787931 17.000000
      vertex -12.188471 5.787931 19.000000
    endloop
  endfacet
  facet normal -0.840025 -0.542547 0.000000
    outer loop
      vertex -12.488750 6.252852 17.000000
      vertex -12.188471 5.787931 19.000000
      vertex -12.488750 6.252852 19.000000
    endloop
  endfacet
  facet normal -0.811938 -0.583744 0.000000
    outer loop
      vertex -12.811830 6.702229 17.000000
      vertex -12.488750 6.252852 17.000000
      vertex -12.488750 6.252852 19.000000
    endloop
  endfacet
  facet normal -0.811938 -0.583744 0.000000
    outer loop
      vertex -12.811830 6.702229 17.000000
      vertex -12.488750 6.252852 19.000000
      vertex -12.811830 6.702229 19.000000
    endloop
  endfacet
  facet normal -0.781831 -0.623490 0.000000
    outer loop
      vertex -13.156907 7.134943 17.000000
      vertex -12.811830 6.702229 17.000000
      vertex -12.811830 6.702229 19.000000
    endloop
  endfacet
  facet normal -0.781831 -0.623490 0.000000
    outer loop
      vertex -13.156907 7.134943 17.000000
      vertex -12.811830 6.702229 19.000000
      vertex -13.156907 7.134943 19.000000
    endloop
  endfacet
  facet normal -0.749781 -0.661686 0.000000
    outer loop
      vertex -13.523125 7.549917 17.000000
      vertex -13.156907 7.134943 17.000000
      vertex -13.156907 7.134943 19.000000
    endloop
  endfacet
  facet normal -0.749781 -0.661686 0.000000
    outer loop
      vertex -13.523125 7.549917 17.000000
      vertex -13.156907 7.134943 19.000000
      vertex -13.523125 7.549917 19.000000
    endloop
  endfacet
  facet normal -0.715867 -0.698236 0.000000
    outer loop
      vertex -13.909572 7.946122 17.000000
      vertex -13.523125 7.549917 17.000000
      vertex -13.523125 7.549917 19.000000
    endloop
  endfacet
  facet normal -0.715867 -0.698236 0.000000
    outer loop
      vertex -13.909572 7.946122 17.000000
      vertex -13.523125 7.549917 19.000000
      vertex -13.909572 7.946122 19.000000
    endloop
  endfacet
  facet normal -0.680173 -0.733052 0.000000
    outer loop
      vertex -14.315288 8.322572 17.000000
      vertex -13.909572 7.946122 17.000000
      vertex -13.909572 7.946122 19.000000
    endloop
  endfacet
  facet normal -0.680173 -0.733052 0.000000
    outer loop
      vertex -14.315288 8.322572 17.000000
      vertex -13.909572 7.946122 19.000000
      vertex -14.315288 8.322572 19.000000
    endloop
  endfacet
  facet normal -0.642787 -0.766045 0.000000
    outer loop
      vertex -14.739264 8.678329 17.000000
      vertex -14.315288 8.322572 17.000000
      vertex -14.315288 8.322572 19.000000
    endloop
  endfacet
  facet normal -0.642787 -0.766045 0.000000
    outer loop
      vertex -14.739264 8.678329 17.000000
      vertex -14.315288 8.322572 19.000000
      vertex -14.739264 8.678329 19.000000
    endloop
  endfacet
  facet normal -0.603805 -0.797132 0.000000
    outer loop
      vertex -15.180446 9.012512 17.000000
      vertex -14.739264 8.678329 19.000000
      vertex -15.180446 9.012512 19.000000
    endloop
  endfacet
  facet normal -0.603805 -0.797132 0.000000
    outer loop
      vertex -15.180446 9.012512 17.000000
      vertex -14.739264 8.678329 17.000000
      vertex -14.739264 8.678329 19.000000
    endloop
  endfacet
  facet normal -0.563320 -0.826239 0.000000
    outer loop
      vertex -15.637736 9.324287 17.000000
      vertex -15.180446 9.012512 19.000000
      vertex -15.637736 9.324287 19.000000
    endloop
  endfacet
  facet normal -0.563320 -0.826239 0.000000
    outer loop
      vertex -15.637736 9.324287 17.000000
      vertex -15.180446 9.012512 17.000000
      vertex -15.180446 9.012512 19.000000
    endloop
  endfacet
  facet normal -0.521435 -0.853291 0.000000
    outer loop
      vertex -16.110001 9.612882 17.000000
      vertex -15.637736 9.324287 19.000000
      vertex -16.110001 9.612882 19.000000
    endloop
  endfacet
  facet normal -0.521435 -0.853291 0.000000
    outer loop
      vertex -16.110001 9.612882 17.000000
      vertex -15.637736 9.324287 17.000000
      vertex -15.637736 9.324287 19.000000
    endloop
  endfacet
  facet normal -0.478254 -0.878221 0.000000
    outer loop
      vertex -16.596062 9.877577 17.000000
      vertex -16.110001 9.612882 19.000000
      vertex -16.596062 9.877577 19.000000
    endloop
  endfacet
  facet normal -0.478254 -0.878221 0.000000
    outer loop
      vertex -16.596062 9.877577 17.000000
      vertex -16.110001 9.612882 17.000000
      vertex -16.110001 9.612882 19.000000
    endloop
  endfacet
  facet normal -0.433884 -0.900969 0.000000
    outer loop
      vertex -17.094713 10.117715 17.000000
      vertex -16.596062 9.877577 19.000000
      vertex -17.094713 10.117715 19.000000
    endloop
  endfacet
  facet normal -0.433884 -0.900969 0.000000
    outer loop
      vertex -17.094713 10.117715 17.000000
      vertex -16.596062 9.877577 17.000000
      vertex -16.596062 9.877577 19.000000
    endloop
  endfacet
  facet normal -0.388435 -0.921476 0.000000
    outer loop
      vertex -17.604715 10.332699 17.000000
      vertex -17.094713 10.117715 19.000000
      vertex -17.604715 10.332699 19.000000
    endloop
  endfacet
  facet normal -0.388435 -0.921476 0.000000
    outer loop
      vertex -17.604715 10.332699 17.000000
      vertex -17.094713 10.117715 17.000000
      vertex -17.094713 10.117715 19.000000
    endloop
  endfacet
  facet normal -0.294755 -0.955573 0.000000
    outer loop
      vertex -18.124798 10.521994 17.000000
      vertex -18.124798 10.521994 19.000000
      vertex -18.653671 10.685129 19.000000
    endloop
  endfacet
  facet normal -0.342021 -0.939692 0.000000
    outer loop
      vertex -18.124798 10.521994 17.000000
      vertex -17.604715 10.332699 19.000000
      vertex -18.124798 10.521994 19.000000
    endloop
  endfacet
  facet normal -0.342021 -0.939692 0.000000
    outer loop
      vertex -18.124798 10.521994 17.000000
      vertex -17.604715 10.332699 17.000000
      vertex -17.604715 10.332699 19.000000
    endloop
  endfacet
  facet normal -0.294755 -0.955573 0.000000
    outer loop
      vertex -18.653671 10.685129 17.000000
      vertex -18.124798 10.521994 17.000000
      vertex -18.653671 10.685129 19.000000
    endloop
  endfacet
  facet normal -0.198145 -0.980173 0.000000
    outer loop
      vertex -19.190018 10.821700 17.000000
      vertex -19.190018 10.821700 19.000000
      vertex -19.732506 10.931366 19.000000
    endloop
  endfacet
  facet normal -0.246758 -0.969077 0.000000
    outer loop
      vertex -19.190018 10.821700 17.000000
      vertex -18.653671 10.685129 19.000000
      vertex -19.190018 10.821700 19.000000
    endloop
  endfacet
  facet normal -0.246758 -0.969077 0.000000
    outer loop
      vertex -19.190018 10.821700 17.000000
      vertex -18.653671 10.685129 17.000000
      vertex -18.653671 10.685129 19.000000
    endloop
  endfacet
  facet normal -0.198145 -0.980173 0.000000
    outer loop
      vertex -19.732506 10.931366 17.000000
      vertex -19.190018 10.821700 17.000000
      vertex -19.732506 10.931366 19.000000
    endloop
  endfacet
  facet normal -0.149042 -0.988831 0.000000
    outer loop
      vertex -20.279785 11.013855 17.000000
      vertex -19.732506 10.931366 19.000000
      vertex -20.279785 11.013855 19.000000
    endloop
  endfacet
  facet normal -0.149042 -0.988831 0.000000
    outer loop
      vertex -20.279785 11.013855 17.000000
      vertex -19.732506 10.931366 17.000000
      vertex -19.732506 10.931366 19.000000
    endloop
  endfacet
  facet normal -0.099568 -0.995031 0.000000
    outer loop
      vertex -20.830496 11.068962 17.000000
      vertex -20.279785 11.013855 19.000000
      vertex -20.830496 11.068962 19.000000
    endloop
  endfacet
  facet normal -0.099568 -0.995031 0.000000
    outer loop
      vertex -20.830496 11.068962 17.000000
      vertex -20.279785 11.013855 17.000000
      vertex -20.279785 11.013855 19.000000
    endloop
  endfacet
  facet normal -0.049846 -0.998757 0.000000
    outer loop
      vertex -21.383270 11.096550 17.000000
      vertex -20.830496 11.068962 19.000000
      vertex -21.383270 11.096550 19.000000
    endloop
  endfacet
  facet normal -0.049846 -0.998757 0.000000
    outer loop
      vertex -21.383270 11.096550 17.000000
      vertex -20.830496 11.068962 17.000000
      vertex -20.830496 11.068962 19.000000
    endloop
  endfacet
  facet normal 0.000000 -1.000000 0.000000
    outer loop
      vertex -21.936731 11.096550 17.000000
      vertex -21.383270 11.096550 19.000000
      vertex -21.936731 11.096550 19.000000
    endloop
  endfacet
  facet normal 0.000000 -1.000000 0.000000
    outer loop
      vertex -21.936731 11.096550 17.000000
      vertex -21.383270 11.096550 17.000000
      vertex -21.383270 11.096550 19.000000
    endloop
  endfacet
  facet normal 0.099568 -0.995031 0.000000
    outer loop
      vertex -22.489504 11.068962 17.000000
      vertex -22.489504 11.068962 19.000000
      vertex -23.040215 11.013855 19.000000
    endloop
  endfacet
  facet normal 0.049846 -0.998757 0.000000
    outer loop
      vertex -22.489504 11.068962 17.000000
      vertex -21.936731 11.096550 19.000000
      vertex -22.489504 11.068962 19.000000
    endloop
  endfacet
  facet normal 0.049846 -0.998757 0.000000
    outer loop
      vertex -22.489504 11.068962 17.000000
      vertex -21.936731 11.096550 17.000000
      vertex -21.936731 11.096550 19.000000
    endloop
  endfacet
  facet normal 0.099568 -0.995031 0.000000
    outer loop
      vertex -23.040215 11.013855 17.000000
      vertex -22.489504 11.068962 17.000000
      vertex -23.040215 11.013855 19.000000
    endloop
  endfacet
  facet normal 0.198145 -0.980173 0.000000
    outer loop
      vertex -23.587494 10.931366 17.000000
      vertex -23.587494 10.931366 19.000000
      vertex -24.129982 10.821700 19.000000
    endloop
  endfacet
  facet normal 0.149042 -0.988831 0.000000
    outer loop
      vertex -23.587494 10.931366 17.000000
      vertex -23.040215 11.013855 19.000000
      vertex -23.587494 10.931366 19.000000
    endloop
  endfacet
  facet normal 0.149042 -0.988831 0.000000
    outer loop
      vertex -23.587494 10.931366 17.000000
      vertex -23.040215 11.013855 17.000000
      vertex -23.040215 11.013855 19.000000
    endloop
  endfacet
  facet normal 0.198145 -0.980173 0.000000
    outer loop
      vertex -24.129982 10.821700 17.000000
      vertex -23.587494 10.931366 17.000000
      vertex -24.129982 10.821700 19.000000
    endloop
  endfacet
  facet normal 0.246758 -0.969077 0.000000
    outer loop
      vertex -24.666328 10.685129 17.000000
      vertex -24.129982 10.821700 17.000000
      vertex -24.129982 10.821700 19.000000
    endloop
  endfacet
  facet normal 0.294755 -0.955573 0.000000
    outer loop
      vertex -24.666328 10.685129 17.000000
      vertex -24.666328 10.685129 19.000000
      vertex -25.195202 10.521994 19.000000
    endloop
  endfacet
  facet normal 0.246758 -0.969077 0.000000
    outer loop
      vertex -24.666328 10.685129 17.000000
      vertex -24.129982 10.821700 19.000000
      vertex -24.666328 10.685129 19.000000
    endloop
  endfacet
  facet normal 0.294755 -0.955573 0.000000
    outer loop
      vertex -25.195202 10.521994 17.000000
      vertex -24.666328 10.685129 17.000000
      vertex -25.195202 10.521994 19.000000
    endloop
  endfacet
  facet normal 0.388436 -0.921476 0.000000
    outer loop
      vertex -25.715286 10.332699 17.000000
      vertex -25.715286 10.332699 19.000000
      vertex -26.225286 10.117715 19.000000
    endloop
  endfacet
  facet normal 0.342019 -0.939693 0.000000
    outer loop
      vertex -25.715286 10.332699 17.000000
      vertex -25.195202 10.521994 19.000000
      vertex -25.715286 10.332699 19.000000
    endloop
  endfacet
  facet normal 0.342019 -0.939693 0.000000
    outer loop
      vertex -25.715286 10.332699 17.000000
      vertex -25.195202 10.521994 17.000000
      vertex -25.195202 10.521994 19.000000
    endloop
  endfacet
  facet normal 0.388436 -0.921476 0.000000
    outer loop
      vertex -26.225286 10.117715 17.000000
      vertex -25.715286 10.332699 17.000000
      vertex -26.225286 10.117715 19.000000
    endloop
  endfacet
  facet normal 0.478254 -0.878221 0.000000
    outer loop
      vertex -26.723938 9.877577 17.000000
      vertex -26.723938 9.877577 19.000000
      vertex -27.209999 9.612882 19.000000
    endloop
  endfacet
  facet normal 0.433884 -0.900969 0.000000
    outer loop
      vertex -26.723938 9.877577 17.000000
      vertex -26.225286 10.117715 19.000000
      vertex -26.723938 9.877577 19.000000
    endloop
  endfacet
  facet normal 0.433884 -0.900969 0.000000
    outer loop
      vertex -26.723938 9.877577 17.000000
      vertex -26.225286 10.117715 17.000000
      vertex -26.225286 10.117715 19.000000
    endloop
  endfacet
  facet normal 0.478254 -0.878221 0.000000
    outer loop
      vertex -27.209999 9.612882 17.000000
      vertex -26.723938 9.877577 17.000000
      vertex -27.209999 9.612882 19.000000
    endloop
  endfacet
  facet normal 0.563320 -0.826239 0.000000
    outer loop
      vertex -27.682264 9.324287 17.000000
      vertex -27.682264 9.324287 19.000000
      vertex -28.139555 9.012512 19.000000
    endloop
  endfacet
  facet normal 0.521434 -0.853292 0.000000
    outer loop
      vertex -27.682264 9.324287 17.000000
      vertex -27.209999 9.612882 19.000000
      vertex -27.682264 9.324287 19.000000
    endloop
  endfacet
  facet normal 0.521434 -0.853292 0.000000
    outer loop
      vertex -27.682264 9.324287 17.000000
      vertex -27.209999 9.612882 17.000000
      vertex -27.209999 9.612882 19.000000
    endloop
  endfacet
  facet normal 0.603805 -0.797132 0.000000
    outer loop
      vertex -28.139555 9.012512 17.000000
      vertex -28.139555 9.012512 19.000000
      vertex -28.580736 8.678329 19.000000
    endloop
  endfacet
  facet normal 0.563320 -0.826239 0.000000
    outer loop
      vertex -28.139555 9.012512 17.000000
      vertex -27.682264 9.324287 17.000000
      vertex -28.139555 9.012512 19.000000
    endloop
  endfacet
  facet normal 0.603805 -0.797132 0.000000
    outer loop
      vertex -28.580736 8.678329 17.000000
      vertex -28.139555 9.012512 17.000000
      vertex -28.580736 8.678329 19.000000
    endloop
  endfacet
  facet normal 0.680173 -0.733052 0.000000
    outer loop
      vertex -29.004713 8.322572 17.000000
      vertex -29.004713 8.322572 19.000000
      vertex -29.410429 7.946122 19.000000
    endloop
  endfacet
  facet normal 0.642786 -0.766045 0.000000
    outer loop
      vertex -29.004713 8.322572 17.000000
      vertex -28.580736 8.678329 19.000000
      vertex -29.004713 8.322572 19.000000
    endloop
  endfacet
  facet normal 0.642786 -0.766045 0.000000
    outer loop
      vertex -29.004713 8.322572 17.000000
      vertex -28.580736 8.678329 17.000000
      vertex -28.580736 8.678329 19.000000
    endloop
  endfacet
  facet normal 0.680173 -0.733052 0.000000
    outer loop
      vertex -29.410429 7.946122 17.000000
      vertex -29.004713 8.322572 17.000000
      vertex -29.410429 7.946122 19.000000
    endloop
  endfacet
  facet normal 0.749780 -0.661687 0.000000
    outer loop
      vertex -29.796875 7.549917 17.000000
      vertex -29.796875 7.549917 19.000000
      vertex -30.163094 7.134943 19.000000
    endloop
  endfacet
  facet normal 0.715868 -0.698236 0.000000
    outer loop
      vertex -29.796875 7.549917 17.000000
      vertex -29.410429 7.946122 19.000000
      vertex -29.796875 7.549917 19.000000
    endloop
  endfacet
  facet normal 0.715868 -0.698236 0.000000
    outer loop
      vertex -29.796875 7.549917 17.000000
      vertex -29.410429 7.946122 17.000000
      vertex -29.410429 7.946122 19.000000
    endloop
  endfacet
  facet normal 0.781831 -0.623490 0.000000
    outer loop
      vertex -30.163094 7.134943 17.000000
      vertex -30.163094 7.134943 19.000000
      vertex -30.508171 6.702229 19.000000
    endloop
  endfacet
  facet normal 0.749780 -0.661687 0.000000
    outer loop
      vertex -30.163094 7.134943 17.000000
      vertex -29.796875 7.549917 17.000000
      vertex -30.163094 7.134943 19.000000
    endloop
  endfacet
  facet normal 0.811938 -0.583744 0.000000
    outer loop
      vertex -30.508171 6.702229 17.000000
      vertex -30.508171 6.702229 19.000000
      vertex -30.831251 6.252852 19.000000
    endloop
  endfacet
  facet normal 0.781831 -0.623490 0.000000
    outer loop
      vertex -30.508171 6.702229 17.000000
      vertex -30.163094 7.134943 17.000000
      vertex -30.508171 6.702229 19.000000
    endloop
  endfacet
  facet normal 0.811938 -0.583744 0.000000
    outer loop
      vertex -30.831251 6.252852 17.000000
      vertex -30.508171 6.702229 17.000000
      vertex -30.831251 6.252852 19.000000
    endloop
  endfacet
  facet normal 0.840026 -0.542546 0.000000
    outer loop
      vertex -31.131529 5.787931 17.000000
      vertex -30.831251 6.252852 19.000000
      vertex -31.131529 5.787931 19.000000
    endloop
  endfacet
  facet normal 0.840026 -0.542546 0.000000
    outer loop
      vertex -31.131529 5.787931 17.000000
      vertex -30.831251 6.252852 17.000000
      vertex -30.831251 6.252852 19.000000
    endloop
  endfacet
  facet normal 0.866025 -0.500001 0.000000
    outer loop
      vertex -31.408260 5.308619 17.000000
      vertex -31.131529 5.787931 17.000000
      vertex -31.131529 5.787931 19.000000
    endloop
  endfacet
  facet normal 0.866025 -0.500001 0.000000
    outer loop
      vertex -31.408260 5.308619 17.000000
      vertex -31.131529 5.787931 19.000000
      vertex -31.408260 5.308619 19.000000
    endloop
  endfacet
  facet normal 0.889872 -0.456211 0.000000
    outer loop
      vertex -31.660755 4.816110 17.000000
      vertex -31.408260 5.308619 17.000000
      vertex -31.408260 5.308619 19.000000
    endloop
  endfacet
  facet normal 0.911506 -0.411286 0.000000
    outer loop
      vertex -31.660755 4.816110 17.000000
      vertex -31.660755 4.816110 19.000000
      vertex -31.888386 4.311626 19.000000
    endloop
  endfacet
  facet normal 0.889872 -0.456211 0.000000
    outer loop
      vertex -31.660755 4.816110 17.000000
      vertex -31.408260 5.308619 19.000000
      vertex -31.660755 4.816110 19.000000
    endloop
  endfacet
  facet normal 0.911506 -0.411286 0.000000
    outer loop
      vertex -31.888386 4.311626 17.000000
      vertex -31.660755 4.816110 17.000000
      vertex -31.888386 4.311626 19.000000
    endloop
  endfacet
  facet normal 0.930874 -0.365340 0.000000
    outer loop
      vertex -32.090588 3.796424 17.000000
      vertex -31.888386 4.311626 17.000000
      vertex -31.888386 4.311626 19.000000
    endloop
  endfacet
  facet normal 0.947928 -0.318486 0.000000
    outer loop
      vertex -32.090588 3.796424 17.000000
      vertex -32.090588 3.796424 19.000000
      vertex -32.266857 3.271782 19.000000
    endloop
  endfacet
  facet normal 0.930874 -0.365340 0.000000
    outer loop
      vertex -32.090588 3.796424 17.000000
      vertex -31.888386 4.311626 19.000000
      vertex -32.090588 3.796424 19.000000
    endloop
  endfacet
  facet normal 0.947928 -0.318486 0.000000
    outer loop
      vertex -32.266857 3.271782 17.000000
      vertex -32.090588 3.796424 17.000000
      vertex -32.266857 3.271782 19.000000
    endloop
  endfacet
  facet normal 0.962623 -0.270845 0.000000
    outer loop
      vertex -32.416759 2.739007 17.000000
      vertex -32.266857 3.271782 17.000000
      vertex -32.266857 3.271782 19.000000
    endloop
  endfacet
  facet normal 0.974929 -0.222516 0.000000
    outer loop
      vertex -32.416759 2.739007 17.000000
      vertex -32.416759 2.739007 19.000000
      vertex -32.539913 2.199422 19.000000
    endloop
  endfacet
  facet normal 0.962623 -0.270845 0.000000
    outer loop
      vertex -32.416759 2.739007 17.000000
      vertex -32.266857 3.271782 19.000000
      vertex -32.416759 2.739007 19.000000
    endloop
  endfacet
  facet normal 0.984808 -0.173648 0.000000
    outer loop
      vertex -32.539913 2.199422 17.000000
      vertex -32.539913 2.199422 19.000000
      vertex -32.636021 1.654369 19.000000
    endloop
  endfacet
  facet normal 0.974929 -0.222516 0.000000
    outer loop
      vertex -32.539913 2.199422 17.000000
      vertex -32.416759 2.739007 17.000000
      vertex -32.539913 2.199422 19.000000
    endloop
  endfacet
  facet normal 0.984808 -0.173648 0.000000
    outer loop
      vertex -32.636021 1.654369 17.000000
      vertex -32.539913 2.199422 17.000000
      vertex -32.636021 1.654369 19.000000
    endloop
  endfacet
  facet normal 0.997204 -0.074728 0.000000
    outer loop
      vertex -32.704842 1.105203 17.000000
      vertex -32.704842 1.105203 19.000000
      vertex -32.746201 0.553289 19.000000
    endloop
  endfacet
  facet normal 0.992239 -0.124346 0.000000
    outer loop
      vertex -32.704842 1.105203 17.000000
      vertex -32.636021 1.654369 19.000000
      vertex -32.704842 1.105203 19.000000
    endloop
  endfacet
  facet normal 0.992239 -0.124346 0.000000
    outer loop
      vertex -32.704842 1.105203 17.000000
      vertex -32.636021 1.654369 17.000000
      vertex -32.636021 1.654369 19.000000
    endloop
  endfacet
  facet normal 0.997204 -0.074728 0.000000
    outer loop
      vertex -32.746201 0.553289 17.000000
      vertex -32.704842 1.105203 17.000000
      vertex -32.746201 0.553289 19.000000
    endloop
  endfacet
  facet normal 0.999689 -0.024930 0.000000
    outer loop
      vertex -32.759998 0.000000 17.000000
      vertex -32.746201 0.553289 17.000000
      vertex -32.746201 0.553289 19.000000
    endloop
  endfacet
  facet normal 0.999689 0.024930 -0.000000
    outer loop
      vertex -32.759998 0.000000 17.000000
      vertex -32.759998 0.000000 19.000000
      vertex -32.746201 -0.553289 19.000000
    endloop
  endfacet
  facet normal 0.999689 -0.024930 0.000000
    outer loop
      vertex -32.759998 0.000000 17.000000
      vertex -32.746201 0.553289 19.000000
      vertex -32.759998 0.000000 19.000000
    endloop
  endfacet
  facet normal 0.999689 0.024930 -0.000000
    outer loop
      vertex -32.746201 -0.553289 17.000000
      vertex -32.759998 0.000000 17.000000
      vertex -32.746201 -0.553289 19.000000
    endloop
  endfacet
  facet normal 0.997204 0.074728 0.000000
    outer loop
      vertex -32.704842 -1.105203 17.000000
      vertex -32.746201 -0.553289 17.000000
      vertex -32.746201 -0.553289 19.000000
    endloop
  endfacet
  facet normal 0.997204 0.074728 -0.000000
    outer loop
      vertex -32.704842 -1.105203 17.000000
      vertex -32.746201 -0.553289 19.000000
      vertex -32.704842 -1.105203 19.000000
    endloop
  endfacet
  facet normal 0.992239 0.124346 0.000000
    outer loop
      vertex -32.636021 -1.654369 17.000000
      vertex -32.704842 -1.105203 17.000000
      vertex -32.704842 -1.105203 19.000000
    endloop
  endfacet
  facet normal 0.992239 0.124346 -0.000000
    outer loop
      vertex -32.636021 -1.654369 17.000000
      vertex -32.704842 -1.105203 19.000000
      vertex -32.636021 -1.654369 19.000000
    endloop
  endfacet
  facet normal 0.984808 0.173648 0.000000
    outer loop
      vertex -32.539913 -2.199422 17.000000
      vertex -32.636021 -1.654369 17.000000
      vertex -32.636021 -1.654369 19.000000
    endloop
  endfacet
  facet normal 0.974929 0.222516 -0.000000
    outer loop
      vertex -32.539913 -2.199422 17.000000
      vertex -32.539913 -2.199422 19.000000
      vertex -32.416759 -2.739007 19.000000
    endloop
  endfacet
  facet normal 0.984808 0.173648 -0.000000
    outer loop
      vertex -32.539913 -2.199422 17.000000
      vertex -32.636021 -1.654369 19.000000
      vertex -32.539913 -2.199422 19.000000
    endloop
  endfacet
  facet normal 0.974929 0.222516 -0.000000
    outer loop
      vertex -32.416759 -2.739007 17.000000
      vertex -32.539913 -2.199422 17.000000
      vertex -32.416759 -2.739007 19.000000
    endloop
  endfacet
  facet normal 0.962623 0.270845 0.000000
    outer loop
      vertex -32.266857 -3.271782 17.000000
      vertex -32.416759 -2.739007 17.000000
      vertex -32.416759 -2.739007 19.000000
    endloop
  endfacet
  facet normal 0.962623 0.270845 -0.000000
    outer loop
      vertex -32.266857 -3.271782 17.000000
      vertex -32.416759 -2.739007 19.000000
      vertex -32.266857 -3.271782 19.000000
    endloop
  endfacet
  facet normal 0.947928 0.318486 0.000000
    outer loop
      vertex -32.090588 -3.796424 17.000000
      vertex -32.266857 -3.271782 17.000000
      vertex -32.266857 -3.271782 19.000000
    endloop
  endfacet
  facet normal 0.947928 0.318486 -0.000000
    outer loop
      vertex -32.090588 -3.796424 17.000000
      vertex -32.266857 -3.271782 19.000000
      vertex -32.090588 -3.796424 19.000000
    endloop
  endfacet
  facet normal 0.930874 0.365340 0.000000
    outer loop
      vertex -31.888386 -4.311626 17.000000
      vertex -32.090588 -3.796424 17.000000
      vertex -32.090588 -3.796424 19.000000
    endloop
  endfacet
  facet normal 0.930874 0.365340 -0.000000
    outer loop
      vertex -31.888386 -4.311626 17.000000
      vertex -32.090588 -3.796424 19.000000
      vertex -31.888386 -4.311626 19.000000
    endloop
  endfacet
  facet normal 0.911506 0.411286 0.000000
    outer loop
      vertex -31.660755 -4.816110 17.000000
      vertex -31.888386 -4.311626 17.000000
      vertex -31.888386 -4.311626 19.000000
    endloop
  endfacet
  facet normal 0.911506 0.411286 -0.000000
    outer loop
      vertex -31.660755 -4.816110 17.000000
      vertex -31.888386 -4.311626 19.000000
      vertex -31.660755 -4.816110 19.000000
    endloop
  endfacet
  facet normal 0.889872 0.456211 0.000000
    outer loop
      vertex -31.408260 -5.308619 17.000000
      vertex -31.660755 -4.816110 17.000000
      vertex -31.660755 -4.816110 19.000000
    endloop
  endfacet
  facet normal 0.889872 0.456211 -0.000000
    outer loop
      vertex -31.408260 -5.308619 17.000000
      vertex -31.660755 -4.816110 19.000000
      vertex -31.408260 -5.308619 19.000000
    endloop
  endfacet
  facet normal 0.866025 0.500001 0.000000
    outer loop
      vertex -31.131529 -5.787931 17.000000
      vertex -31.408260 -5.308619 17.000000
      vertex -31.408260 -5.308619 19.000000
    endloop
  endfacet
  facet normal 0.866025 0.500001 -0.000000
    outer loop
      vertex -31.131529 -5.787931 17.000000
      vertex -31.408260 -5.308619 19.000000
      vertex -31.131529 -5.787931 19.000000
    endloop
  endfacet
  facet normal 0.840026 0.542546 0.000000
    outer loop
      vertex -30.831251 -6.252852 17.000000
      vertex -31.131529 -5.787931 17.000000
      vertex -31.131529 -5.787931 19.000000
    endloop
  endfacet
  facet normal 0.840026 0.542546 -0.000000
    outer loop
      vertex -30.831251 -6.252852 17.000000
      vertex -31.131529 -5.787931 19.000000
      vertex -30.831251 -6.252852 19.000000
    endloop
  endfacet
  facet normal 0.811938 0.583744 0.000000
    outer loop
      vertex -30.508171 -6.702229 17.000000
      vertex -30.831251 -6.252852 17.000000
      vertex -30.831251 -6.252852 19.000000
    endloop
  endfacet
  facet normal 0.811938 0.583744 -0.000000
    outer loop
      vertex -30.508171 -6.702229 17.000000
      vertex -30.831251 -6.252852 19.000000
      vertex -30.508171 -6.702229 19.000000
    endloop
  endfacet
  facet normal 0.781831 0.623490 0.000000
    outer loop
      vertex -30.163094 -7.134943 17.000000
      vertex -30.508171 -6.702229 17.000000
      vertex -30.508171 -6.702229 19.000000
    endloop
  endfacet
  facet normal 0.781831 0.623490 -0.000000
    outer loop
      vertex -30.163094 -7.134943 17.000000
      vertex -30.508171 -6.702229 19.000000
      vertex -30.163094 -7.134943 19.000000
    endloop
  endfacet
  facet normal 0.749780 0.661687 0.000000
    outer loop
      vertex -29.796875 -7.549917 17.000000
      vertex -30.163094 -7.134943 17.000000
      vertex -30.163094 -7.134943 19.000000
    endloop
  endfacet
  facet normal 0.749780 0.661687 -0.000000
    outer loop
      vertex -29.796875 -7.549917 17.000000
      vertex -30.163094 -7.134943 19.000000
      vertex -29.796875 -7.549917 19.000000
    endloop
  endfacet
  facet normal 0.715868 0.698236 0.000000
    outer loop
      vertex -29.410429 -7.946122 17.000000
      vertex -29.796875 -7.549917 17.000000
      vertex -29.796875 -7.549917 19.000000
    endloop
  endfacet
  facet normal 0.680173 0.733052 -0.000000
    outer loop
      vertex -29.410429 -7.946122 17.000000
      vertex -29.410429 -7.946122 19.000000
      vertex -29.004713 -8.322572 19.000000
    endloop
  endfacet
  facet normal 0.715868 0.698236 -0.000000
    outer loop
      vertex -29.410429 -7.946122 17.000000
      vertex -29.796875 -7.549917 19.000000
      vertex -29.410429 -7.946122 19.000000
    endloop
  endfacet
  facet normal 0.680173 0.733052 -0.000000
    outer loop
      vertex -29.004713 -8.322572 17.000000
      vertex -29.410429 -7.946122 17.000000
      vertex -29.004713 -8.322572 19.000000
    endloop
  endfacet
  facet normal 0.603805 0.797132 -0.000000
    outer loop
      vertex -28.580736 -8.678329 17.000000
      vertex -28.580736 -8.678329 19.000000
      vertex -28.139555 -9.012512 19.000000
    endloop
  endfacet
  facet normal 0.642786 0.766045 -0.000000
    outer loop
      vertex -28.580736 -8.678329 17.000000
      vertex -29.004713 -8.322572 19.000000
      vertex -28.580736 -8.678329 19.000000
    endloop
  endfacet
  facet normal 0.642786 0.766045 0.000000
    outer loop
      vertex -28.580736 -8.678329 17.000000
      vertex -29.004713 -8.322572 17.000000
      vertex -29.004713 -8.322572 19.000000
    endloop
  endfacet
  facet normal 0.603805 0.797132 -0.000000
    outer loop
      vertex -28.139555 -9.012512 17.000000
      vertex -28.580736 -8.678329 17.000000
      vertex -28.139555 -9.012512 19.000000
    endloop
  endfacet
  facet normal 0.521434 0.853292 -0.000000
    outer loop
      vertex -27.682264 -9.324287 17.000000
      vertex -27.682264 -9.324287 19.000000
      vertex -27.209999 -9.612882 19.000000
    endloop
  endfacet
  facet normal 0.563320 0.826239 -0.000000
    outer loop
      vertex -27.682264 -9.324287 17.000000
      vertex -28.139555 -9.012512 19.000000
      vertex -27.682264 -9.324287 19.000000
    endloop
  endfacet
  facet normal 0.563320 0.826239 0.000000
    outer loop
      vertex -27.682264 -9.324287 17.000000
      vertex -28.139555 -9.012512 17.000000
      vertex -28.139555 -9.012512 19.000000
    endloop
  endfacet
  facet normal 0.521434 0.853292 -0.000000
    outer loop
      vertex -27.209999 -9.612882 17.000000
      vertex -27.682264 -9.324287 17.000000
      vertex -27.209999 -9.612882 19.000000
    endloop
  endfacet
  facet normal 0.433884 0.900969 -0.000000
    outer loop
      vertex -26.723938 -9.877577 17.000000
      vertex -26.723938 -9.877577 19.000000
      vertex -26.225286 -10.117715 19.000000
    endloop
  endfacet
  facet normal 0.478254 0.878221 -0.000000
    outer loop
      vertex -26.723938 -9.877577 17.000000
      vertex -27.209999 -9.612882 19.000000
      vertex -26.723938 -9.877577 19.000000
    endloop
  endfacet
  facet normal 0.478254 0.878221 0.000000
    outer loop
      vertex -26.723938 -9.877577 17.000000
      vertex -27.209999 -9.612882 17.000000
      vertex -27.209999 -9.612882 19.000000
    endloop
  endfacet
  facet normal 0.433884 0.900969 -0.000000
    outer loop
      vertex -26.225286 -10.117715 17.000000
      vertex -26.723938 -9.877577 17.000000
      vertex -26.225286 -10.117715 19.000000
    endloop
  endfacet
  facet normal 0.388436 0.921476 0.000000
    outer loop
      vertex -25.715286 -10.332699 17.000000
      vertex -26.225286 -10.117715 17.000000
      vertex -26.225286 -10.117715 19.000000
    endloop
  endfacet
  facet normal 0.388436 0.921476 -0.000000
    outer loop
      vertex -25.715286 -10.332699 17.000000
      vertex -26.225286 -10.117715 19.000000
      vertex -25.715286 -10.332699 19.000000
    endloop
  endfacet
  facet normal 0.342019 0.939693 0.000000
    outer loop
      vertex -25.195202 -10.521994 17.000000
      vertex -25.715286 -10.332699 17.000000
      vertex -25.715286 -10.332699 19.000000
    endloop
  endfacet
  facet normal 0.294755 0.955573 -0.000000
    outer loop
      vertex -25.195202 -10.521994 17.000000
      vertex -25.195202 -10.521994 19.000000
      vertex -24.666328 -10.685129 19.000000
    endloop
  endfacet
  facet normal 0.342019 0.939693 -0.000000
    outer loop
      vertex -25.195202 -10.521994 17.000000
      vertex -25.715286 -10.332699 19.000000
      vertex -25.195202 -10.521994 19.000000
    endloop
  endfacet
  facet normal 0.294755 0.955573 -0.000000
    outer loop
      vertex -24.666328 -10.685129 17.000000
      vertex -25.195202 -10.521994 17.000000
      vertex -24.666328 -10.685129 19.000000
    endloop
  endfacet
  facet normal 0.246758 0.969077 0.000000
    outer loop
      vertex -24.129982 -10.821700 17.000000
      vertex -24.666328 -10.685129 17.000000
      vertex -24.666328 -10.685129 19.000000
    endloop
  endfacet
  facet normal 0.246758 0.969077 -0.000000
    outer loop
      vertex -24.129982 -10.821700 17.000000
      vertex -24.666328 -10.685129 19.000000
      vertex -24.129982 -10.821700 19.000000
    endloop
  endfacet
  facet normal 0.198145 0.980173 0.000000
    outer loop
      vertex -23.587494 -10.931366 17.000000
      vertex -24.129982 -10.821700 17.000000
      vertex -24.129982 -10.821700 19.000000
    endloop
  endfacet
  facet normal 0.198145 0.980173 -0.000000
    outer loop
      vertex -23.587494 -10.931366 17.000000
      vertex -24.129982 -10.821700 19.000000
      vertex -23.587494 -10.931366 19.000000
    endloop
  endfacet
  facet normal 0.149042 0.988831 0.000000
    outer loop
      vertex -23.040215 -11.013855 17.000000
      vertex -23.587494 -10.931366 17.000000
      vertex -23.587494 -10.931366 19.000000
    endloop
  endfacet
  facet normal 0.099568 0.995031 -0.000000
    outer loop
      vertex -23.040215 -11.013855 17.000000
      vertex -23.040215 -11.013855 19.000000
      vertex -22.489504 -11.068962 19.000000
    endloop
  endfacet
  facet normal 0.149042 0.988831 -0.000000
    outer loop
      vertex -23.040215 -11.013855 17.000000
      vertex -23.587494 -10.931366 19.000000
      vertex -23.040215 -11.013855 19.000000
    endloop
  endfacet
  facet normal 0.099568 0.995031 -0.000000
    outer loop
      vertex -22.489504 -11.068962 17.000000
      vertex -23.040215 -11.013855 17.000000
      vertex -22.489504 -11.068962 19.000000
    endloop
  endfacet
  facet normal 0.049846 0.998757 0.000000
    outer loop
      vertex -21.936731 -11.096550 17.000000
      vertex -22.489504 -11.068962 17.000000
      vertex -22.489504 -11.068962 19.000000
    endloop
  endfacet
  facet normal 0.000000 1.000000 0.000000
    outer loop
      vertex -21.936731 -11.096550 17.000000
      vertex -21.936731 -11.096550 19.000000
      vertex -21.383270 -11.096550 19.000000
    endloop
  endfacet
  facet normal 0.049846 0.998757 -0.000000
    outer loop
      vertex -21.936731 -11.096550 17.000000
      vertex -22.489504 -11.068962 19.000000
      vertex -21.936731 -11.096550 19.000000
    endloop
  endfacet
  facet normal 0.000000 1.000000 -0.000000
    outer loop
      vertex -21.383270 -11.096550 17.000000
      vertex -21.936731 -11.096550 17.000000
      vertex -21.383270 -11.096550 19.000000
    endloop
  endfacet
  facet normal -0.049846 0.998757 0.000000
    outer loop
      vertex -20.830496 -11.068962 17.000000
      vertex -21.383270 -11.096550 17.000000
      vertex -21.383270 -11.096550 19.000000
    endloop
  endfacet
  facet normal -0.049846 0.998757 0.000000
    outer loop
      vertex -20.830496 -11.068962 17.000000
      vertex -21.383270 -11.096550 19.000000
      vertex -20.830496 -11.068962 19.000000
    endloop
  endfacet
  facet normal -0.099568 0.995031 0.000000
    outer loop
      vertex -20.279785 -11.013855 17.000000
      vertex -20.830496 -11.068962 17.000000
      vertex -20.830496 -11.068962 19.000000
    endloop
  endfacet
  facet normal -0.099568 0.995031 0.000000
    outer loop
      vertex -20.279785 -11.013855 17.000000
      vertex -20.830496 -11.068962 19.000000
      vertex -20.279785 -11.013855 19.000000
    endloop
  endfacet
  facet normal -0.149042 0.988831 0.000000
    outer loop
      vertex -19.732506 -10.931366 17.000000
      vertex -20.279785 -11.013855 17.000000
      vertex -20.279785 -11.013855 19.000000
    endloop
  endfacet
  facet normal -0.198145 0.980173 0.000000
    outer loop
      vertex -19.732506 -10.931366 17.000000
      vertex -19.732506 -10.931366 19.000000
      vertex -19.190018 -10.821700 19.000000
    endloop
  endfacet
  facet normal -0.149042 0.988831 0.000000
    outer loop
      vertex -19.732506 -10.931366 17.000000
      vertex -20.279785 -11.013855 19.000000
      vertex -19.732506 -10.931366 19.000000
    endloop
  endfacet
  facet normal -0.198145 0.980173 0.000000
    outer loop
      vertex -19.190018 -10.821700 17.000000
      vertex -19.732506 -10.931366 17.000000
      vertex -19.190018 -10.821700 19.000000
    endloop
  endfacet
  facet normal -0.246758 0.969077 0.000000
    outer loop
      vertex -18.653671 -10.685129 17.000000
      vertex -19.190018 -10.821700 17.000000
      vertex -19.190018 -10.821700 19.000000
    endloop
  endfacet
  facet normal -0.294755 0.955573 0.000000
    outer loop
      vertex -18.653671 -10.685129 17.000000
      vertex -18.653671 -10.685129 19.000000
      vertex -18.124798 -10.521994 19.000000
    endloop
  endfacet
  facet normal -0.246758 0.969077 0.000000
    outer loop
      vertex -18.653671 -10.685129 17.000000
      vertex -19.190018 -10.821700 19.000000
      vertex -18.653671 -10.685129 19.000000
    endloop
  endfacet
  facet normal -0.294755 0.955573 0.000000
    outer loop
      vertex -18.124798 -10.521994 17.000000
      vertex -18.653671 -10.685129 17.000000
      vertex -18.124798 -10.521994 19.000000
    endloop
  endfacet
  facet normal -0.388435 0.921476 0.000000
    outer loop
      vertex -17.604715 -10.332699 17.000000
      vertex -17.604715 -10.332699 19.000000
      vertex -17.094713 -10.117715 19.000000
    endloop
  endfacet
  facet normal -0.342021 0.939692 0.000000
    outer loop
      vertex -17.604715 -10.332699 17.000000
      vertex -18.124798 -10.521994 19.000000
      vertex -17.604715 -10.332699 19.000000
    endloop
  endfacet
  facet normal -0.342021 0.939692 0.000000
    outer loop
      vertex -17.604715 -10.332699 17.000000
      vertex -18.124798 -10.521994 17.000000
      vertex -18.124798 -10.521994 19.000000
    endloop
  endfacet
  facet normal -0.388435 0.921476 0.000000
    outer loop
      vertex -17.094713 -10.117715 17.000000
      vertex -17.604715 -10.332699 17.000000
      vertex -17.094713 -10.117715 19.000000
    endloop
  endfacet
  facet normal -0.478254 0.878221 0.000000
    outer loop
      vertex -16.596062 -9.877577 17.000000
      vertex -16.596062 -9.877577 19.000000
      vertex -16.110001 -9.612882 19.000000
    endloop
  endfacet
  facet normal -0.433884 0.900969 0.000000
    outer loop
      vertex -16.596062 -9.877577 17.000000
      vertex -17.094713 -10.117715 19.000000
      vertex -16.596062 -9.877577 19.000000
    endloop
  endfacet
  facet normal -0.433884 0.900969 0.000000
    outer loop
      vertex -16.596062 -9.877577 17.000000
      vertex -17.094713 -10.117715 17.000000
      vertex -17.094713 -10.117715 19.000000
    endloop
  endfacet
  facet normal -0.478254 0.878221 0.000000
    outer loop
      vertex -16.110001 -9.612882 17.000000
      vertex -16.596062 -9.877577 17.000000
      vertex -16.110001 -9.612882 19.000000
    endloop
  endfacet
  facet normal -0.521435 0.853291 0.000000
    outer loop
      vertex -15.637736 -9.324287 17.000000
      vertex -16.110001 -9.612882 19.000000
      vertex -15.637736 -9.324287 19.000000
    endloop
  endfacet
  facet normal -0.521435 0.853291 0.000000
    outer loop
      vertex -15.637736 -9.324287 17.000000
      vertex -16.110001 -9.612882 17.000000
      vertex -16.110001 -9.612882 19.000000
    endloop
  endfacet
  facet normal -0.563320 0.826239 0.000000
    outer loop
      vertex -15.180446 -9.012512 17.000000
      vertex -15.637736 -9.324287 19.000000
      vertex -15.180446 -9.012512 19.000000
    endloop
  endfacet
  facet normal -0.563320 0.826239 0.000000
    outer loop
      vertex -15.180446 -9.012512 17.000000
      vertex -15.637736 -9.324287 17.000000
      vertex -15.637736 -9.324287 19.000000
    endloop
  endfacet
  facet normal -0.603805 0.797132 0.000000
    outer loop
      vertex -14.739264 -8.678329 17.000000
      vertex -15.180446 -9.012512 19.000000
      vertex -14.739264 -8.678329 19.000000
    endloop
  endfacet
  facet normal -0.603805 0.797132 0.000000
    outer loop
      vertex -14.739264 -8.678329 17.000000
      vertex -15.180446 -9.012512 17.000000
      vertex -15.180446 -9.012512 19.000000
    endloop
  endfacet
  facet normal -0.642787 0.766045 0.000000
    outer loop
      vertex -14.315288 -8.322572 17.000000
      vertex -14.739264 -8.678329 19.000000
      vertex -14.315288 -8.322572 19.000000
    endloop
  endfacet
  facet normal -0.642787 0.766045 0.000000
    outer loop
      vertex -14.315288 -8.322572 17.000000
      vertex -14.739264 -8.678329 17.000000
      vertex -14.739264 -8.678329 19.000000
    endloop
  endfacet
  facet normal -0.680173 0.733052 0.000000
    outer loop
      vertex -13.909572 -7.946122 17.000000
      vertex -14.315288 -8.322572 19.000000
      vertex -13.909572 -7.946122 19.000000
    endloop
  endfacet
  facet normal -0.680173 0.733052 0.000000
    outer loop
      vertex -13.909572 -7.946122 17.000000
      vertex -14.315288 -8.322572 17.000000
      vertex -14.315288 -8.322572 19.000000
    endloop
  endfacet
  facet normal -0.715867 0.698236 0.000000
    outer loop
      vertex -13.523125 -7.549917 17.000000
      vertex -13.909572 -7.946122 19.000000
      vertex -13.523125 -7.549917 19.000000
    endloop
  endfacet
  facet normal -0.715867 0.698236 0.000000
    outer loop
      vertex -13.523125 -7.549917 17.000000
      vertex -13.909572 -7.946122 17.000000
      vertex -13.909572 -7.946122 19.000000
    endloop
  endfacet
  facet normal -0.749781 0.661686 0.000000
    outer loop
      vertex -13.156907 -7.134943 17.000000
      vertex -13.523125 -7.549917 19.000000
      vertex -13.156907 -7.134943 19.000000
    endloop
  endfacet
  facet normal -0.749781 0.661686 0.000000
    outer loop
      vertex -13.156907 -7.134943 17.000000
      vertex -13.523125 -7.549917 17.000000
      vertex -13.523125 -7.549917 19.000000
    endloop
  endfacet
  facet normal -0.781831 0.623490 0.000000
    outer loop
      vertex -12.811830 -6.702229 17.000000
      vertex -13.156907 -7.134943 17.000000
      vertex -13.156907 -7.134943 19.000000
    endloop
  endfacet
  facet normal -0.811938 0.583744 0.000000
    outer loop
      vertex -12.811830 -6.702229 17.000000
      vertex -12.811830 -6.702229 19.000000
      vertex -12.488750 -6.252852 19.000000
    endloop
  endfacet
  facet normal -0.781831 0.623490 0.000000
    outer loop
      vertex -12.811830 -6.702229 17.000000
      vertex -13.156907 -7.134943 19.000000
      vertex -12.811830 -6.702229 19.000000
    endloop
  endfacet
  facet normal -0.811938 0.583744 0.000000
    outer loop
      vertex -12.488750 -6.252852 17.000000
      vertex -12.811830 -6.702229 17.000000
      vertex -12.488750 -6.252852 19.000000
    endloop
  endfacet
  facet normal -0.840025 0.542547 0.000000
    outer loop
      vertex -12.188471 -5.787931 17.000000
      vertex -12.488750 -6.252852 17.000000
      vertex -12.488750 -6.252852 19.000000
    endloop
  endfacet
  facet normal -0.840025 0.542547 0.000000
    outer loop
      vertex -12.188471 -5.787931 17.000000
      vertex -12.488750 -6.252852 19.000000
      vertex -12.188471 -5.787931 19.000000
    endloop
  endfacet
  facet normal -0.866026 0.500000 0.000000
    outer loop
      vertex -11.911740 -5.308619 17.000000
      vertex -12.188471 -5.787931 17.000000
      vertex -12.188471 -5.787931 19.000000
    endloop
  endfacet
  facet normal -0.889872 0.456211 0.000000
    outer loop
      vertex -11.911740 -5.308619 17.000000
      vertex -11.911740 -5.308619 19.000000
      vertex -11.659245 -4.816110 19.000000
    endloop
  endfacet
  facet normal -0.866026 0.500000 0.000000
    outer loop
      vertex -11.911740 -5.308619 17.000000
      vertex -12.188471 -5.787931 19.000000
      vertex -11.911740 -5.308619 19.000000
    endloop
  endfacet
  facet normal -0.889872 0.456211 0.000000
    outer loop
      vertex -11.659245 -4.816110 17.000000
      vertex -11.911740 -5.308619 17.000000
      vertex -11.659245 -4.816110 19.000000
    endloop
  endfacet
  facet normal -0.911506 0.411287 0.000000
    outer loop
      vertex -11.431614 -4.311626 17.000000
      vertex -11.659245 -4.816110 17.000000
      vertex -11.659245 -4.816110 19.000000
    endloop
  endfacet
  facet normal -0.930874 0.365340 0.000000
    outer loop
      vertex -11.431614 -4.311626 17.000000
      vertex -11.431614 -4.311626 19.000000
      vertex -11.229412 -3.796424 19.000000
    endloop
  endfacet
  facet normal -0.911506 0.411287 0.000000
    outer loop
      vertex -11.431614 -4.311626 17.000000
      vertex -11.659245 -4.816110 19.000000
      vertex -11.431614 -4.311626 19.000000
    endloop
  endfacet
  facet normal -0.930874 0.365340 0.000000
    outer loop
      vertex -11.229412 -3.796424 17.000000
      vertex -11.431614 -4.311626 17.000000
      vertex -11.229412 -3.796424 19.000000
    endloop
  endfacet
  facet normal -0.947927 0.318487 0.000000
    outer loop
      vertex -11.053142 -3.271782 17.000000
      vertex -11.229412 -3.796424 17.000000
      vertex -11.229412 -3.796424 19.000000
    endloop
  endfacet
  facet normal -0.947927 0.318487 0.000000
    outer loop
      vertex -11.053142 -3.271782 17.000000
      vertex -11.229412 -3.796424 19.000000
      vertex -11.053142 -3.271782 19.000000
    endloop
  endfacet
  facet normal -0.974928 0.222521 0.000000
    outer loop
      vertex -10.903242 -2.739007 17.000000
      vertex -10.903242 -2.739007 19.000000
      vertex -10.780086 -2.199422 19.000000
    endloop
  endfacet
  facet normal -0.962624 0.270840 0.000000
    outer loop
      vertex -10.903242 -2.739007 17.000000
      vertex -11.053142 -3.271782 19.000000
      vertex -10.903242 -2.739007 19.000000
    endloop
  endfacet
  facet normal -0.962624 0.270840 0.000000
    outer loop
      vertex -10.903242 -2.739007 17.000000
      vertex -11.053142 -3.271782 17.000000
      vertex -11.053142 -3.271782 19.000000
    endloop
  endfacet
  facet normal -0.974928 0.222521 0.000000
    outer loop
      vertex -10.780086 -2.199422 17.000000
      vertex -10.903242 -2.739007 17.000000
      vertex -10.780086 -2.199422 19.000000
    endloop
  endfacet
  facet normal -0.984808 0.173648 0.000000
    outer loop
      vertex -10.683978 -1.654369 17.000000
      vertex -10.780086 -2.199422 19.000000
      vertex -10.683978 -1.654369 19.000000
    endloop
  endfacet
  facet normal -0.984808 0.173648 0.000000
    outer loop
      vertex -10.683978 -1.654369 17.000000
      vertex -10.780086 -2.199422 17.000000
      vertex -10.780086 -2.199422 19.000000
    endloop
  endfacet
  facet normal -0.992239 0.124345 0.000000
    outer loop
      vertex -10.615158 -1.105203 17.000000
      vertex -10.683978 -1.654369 19.000000
      vertex -10.615158 -1.105203 19.000000
    endloop
  endfacet
  facet normal -0.992239 0.124345 0.000000
    outer loop
      vertex -10.615158 -1.105203 17.000000
      vertex -10.683978 -1.654369 17.000000
      vertex -10.683978 -1.654369 19.000000
    endloop
  endfacet
  facet normal -0.997204 0.074730 0.000000
    outer loop
      vertex -10.573798 -0.553289 17.000000
      vertex -10.615158 -1.105203 19.000000
      vertex -10.573798 -0.553289 19.000000
    endloop
  endfacet
  facet normal -0.997204 0.074730 0.000000
    outer loop
      vertex -10.573798 -0.553289 17.000000
      vertex -10.615158 -1.105203 17.000000
      vertex -10.615158 -1.105203 19.000000
    endloop
  endfacet
  facet normal -0.999689 0.024930 0.000000
    outer loop
      vertex -10.560000 0.000000 17.000000
      vertex -10.573798 -0.553289 19.000000
      vertex -10.560000 0.000000 19.000000
    endloop
  endfacet
  facet normal -0.999689 0.024930 0.000000
    outer loop
      vertex -10.560000 0.000000 17.000000
      vertex -10.573798 -0.553289 17.000000
      vertex -10.573798 -0.553289 19.000000
    endloop
  endfacet
  facet normal -0.999689 -0.024930 0.000000
    outer loop
      vertex 32.745201 0.553289 17.000000
      vertex 32.758999 0.000000 17.000000
      vertex 32.758999 0.000000 19.000000
    endloop
  endfacet
  facet normal -0.999689 -0.024930 0.000000
    outer loop
      vertex 32.745201 0.553289 17.000000
      vertex 32.758999 0.000000 19.000000
      vertex 32.745201 0.553289 19.000000
    endloop
  endfacet
  facet normal -0.997204 -0.074728 0.000000
    outer loop
      vertex 32.703842 1.105203 17.000000
      vertex 32.745201 0.553289 19.000000
      vertex 32.703842 1.105203 19.000000
    endloop
  endfacet
  facet normal -0.997204 -0.074728 0.000000
    outer loop
      vertex 32.703842 1.105203 17.000000
      vertex 32.745201 0.553289 17.000000
      vertex 32.745201 0.553289 19.000000
    endloop
  endfacet
  facet normal -0.992239 -0.124346 0.000000
    outer loop
      vertex 32.635021 1.654369 17.000000
      vertex 32.703842 1.105203 19.000000
      vertex 32.635021 1.654369 19.000000
    endloop
  endfacet
  facet normal -0.992239 -0.124346 0.000000
    outer loop
      vertex 32.635021 1.654369 17.000000
      vertex 32.703842 1.105203 17.000000
      vertex 32.703842 1.105203 19.000000
    endloop
  endfacet
  facet normal -0.984808 -0.173648 0.000000
    outer loop
      vertex 32.538914 2.199422 17.000000
      vertex 32.635021 1.654369 19.000000
      vertex 32.538914 2.199422 19.000000
    endloop
  endfacet
  facet normal -0.984808 -0.173648 0.000000
    outer loop
      vertex 32.538914 2.199422 17.000000
      vertex 32.635021 1.654369 17.000000
      vertex 32.635021 1.654369 19.000000
    endloop
  endfacet
  facet normal -0.974928 -0.222522 0.000000
    outer loop
      vertex 32.415756 2.739007 17.000000
      vertex 32.538914 2.199422 19.000000
      vertex 32.415756 2.739007 19.000000
    endloop
  endfacet
  facet normal -0.974928 -0.222522 0.000000
    outer loop
      vertex 32.415756 2.739007 17.000000
      vertex 32.538914 2.199422 17.000000
      vertex 32.538914 2.199422 19.000000
    endloop
  endfacet
  facet normal -0.962625 -0.270838 0.000000
    outer loop
      vertex 32.265858 3.271782 17.000000
      vertex 32.415756 2.739007 19.000000
      vertex 32.265858 3.271782 19.000000
    endloop
  endfacet
  facet normal -0.962625 -0.270838 0.000000
    outer loop
      vertex 32.265858 3.271782 17.000000
      vertex 32.415756 2.739007 17.000000
      vertex 32.415756 2.739007 19.000000
    endloop
  endfacet
  facet normal -0.947928 -0.318486 0.000000
    outer loop
      vertex 32.089588 3.796424 17.000000
      vertex 32.265858 3.271782 19.000000
      vertex 32.089588 3.796424 19.000000
    endloop
  endfacet
  facet normal -0.947928 -0.318486 0.000000
    outer loop
      vertex 32.089588 3.796424 17.000000
      vertex 32.265858 3.271782 17.000000
      vertex 32.265858 3.271782 19.000000
    endloop
  endfacet
  facet normal -0.930874 -0.365340 0.000000
    outer loop
      vertex 31.887386 4.311626 17.000000
      vertex 32.089588 3.796424 19.000000
      vertex 31.887386 4.311626 19.000000
    endloop
  endfacet
  facet normal -0.930874 -0.365340 0.000000
    outer loop
      vertex 31.887386 4.311626 17.000000
      vertex 32.089588 3.796424 17.000000
      vertex 32.089588 3.796424 19.000000
    endloop
  endfacet
  facet normal -0.911505 -0.411289 0.000000
    outer loop
      vertex 31.659754 4.816110 17.000000
      vertex 31.887386 4.311626 19.000000
      vertex 31.659754 4.816110 19.000000
    endloop
  endfacet
  facet normal -0.911505 -0.411289 0.000000
    outer loop
      vertex 31.659754 4.816110 17.000000
      vertex 31.887386 4.311626 17.000000
      vertex 31.887386 4.311626 19.000000
    endloop
  endfacet
  facet normal -0.889872 -0.456211 0.000000
    outer loop
      vertex 31.407259 5.308619 17.000000
      vertex 31.659754 4.816110 19.000000
      vertex 31.407259 5.308619 19.000000
    endloop
  endfacet
  facet normal -0.889872 -0.456211 0.000000
    outer loop
      vertex 31.407259 5.308619 17.000000
      vertex 31.659754 4.816110 17.000000
      vertex 31.659754 4.816110 19.000000
    endloop
  endfacet
  facet normal -0.866026 -0.499998 0.000000
    outer loop
      vertex 31.130529 5.787931 17.000000
      vertex 31.407259 5.308619 17.000000
      vertex 31.407259 5.308619 19.000000
    endloop
  endfacet
  facet normal -0.866026 -0.499998 0.000000
    outer loop
      vertex 31.130529 5.787931 17.000000
      vertex 31.407259 5.308619 19.000000
      vertex 31.130529 5.787931 19.000000
    endloop
  endfacet
  facet normal -0.840025 -0.542548 0.000000
    outer loop
      vertex 30.830250 6.252852 17.000000
      vertex 31.130529 5.787931 17.000000
      vertex 31.130529 5.787931 19.000000
    endloop
  endfacet
  facet normal -0.840025 -0.542548 0.000000
    outer loop
      vertex 30.830250 6.252852 17.000000
      vertex 31.130529 5.787931 19.000000
      vertex 30.830250 6.252852 19.000000
    endloop
  endfacet
  facet normal -0.811939 -0.583742 0.000000
    outer loop
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

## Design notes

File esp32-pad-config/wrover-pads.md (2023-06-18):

## ESP32 WROVER-B pad configuration

| Bus | Schematic sig. | Pad | GPIO | IO_MUX | IO_MUX_PIN_CTRL | Peripheral signal |
|:---|:---|:---:|:---:|:---|:---|:---|
| I2S | BCLK | 25 | 0 | Func1 (CLK_OUT1) | I2S0_CLK->CLK_OUT1 | n/a |
| I2S | LRCLK | 8 | 32 | Func2 (GPIO) | n/a | I2S0O_WS_out (26) |
| I2S | DOUT | 9 | 33 | Func2 (GPIO) | n/a | I2S0O_DATA_out0 (140)  |
| I2S | /SD_MODE | 12 | 27 | Func2 (GPIO) | n/a | n/a |
| I2C | SCL | 26 | 4 | Func2 (GPIO) | n/a | I2CEXT0_SCL (29) |
| I2C | SDA | 29 | 5 | Func2 (GPIO) | n/a | I2CEXT0_SDA (30) |
| JTAG | TMS | 13 | 14 | Func0 (MTMS) | n/a | n/a |
| JTAG | TDI | 14 | 12 | Func0 (MTDI) | n/a | n/a |
| JTAG | TCK | 16 | 13 | Func0 (MTCK) | n/a | n/a |
| JTAG | TDO | 23 | 15 | Func0 (MTDO) | n/a | n/a |
| UART | TXD | 35 | 1 | Func0 (U0TXD) | n/a | n/a |
| UART | RXD | 34 | 3 | Func0 (U0RXD) | n/a | n/a |
| RELAY | IO2 | 24 | 2 | Func2 (GPIO) | n/a | n/a |
| SDCARD | SD0 | 21 | 7 | Func0 (SD_DATA_0) | n/a | n/a |
| SDCARD | SD1 | 22 | 8 | Func0 (SD_DATA_1) | n/a | n/a |
| SDCARD | SD2 | 17 | 9 | Func0 (SD_DATA_2) | n/a | n/a |
| SDCARD | SD3 | 18 | 10 | Func0 (SD_DATA_3) | n/a | n/a |
| SDCARD | CMD | 19 | 11 | Func0 (SD_CMD) | n/a | n/a |
| SDCARD | CLK | 20 | 6 | Func0 (SD_CLK) | n/a | n/a |
| SDCARD | DET_A | 7 | 35 | Func2 (GPIO) | n/a | n/a |
| PANEL | S1_RED | 36 | 22 | Func2 (GPIO) | n/a | n/a |
| PANEL | S1_GREEN | 37 | 23 | Func2 (GPIO) | n/a | n/a |
| PANEL | S2_RED | 30 | 18 | Func2 (GPIO) | n/a | n/a |
| PANEL | S2_GREEN | 31 | 19 | Func2 (GPIO) | n/a | n/a |
| PANEL | S1_INPUT | 5 | 39 | Func2 (GPIO) | n/a | n/a |
| PANEL | S2_INPUT | 4 | 36 | Func2 (GPIO) | n/a | n/a |
| LED | RED | 33 | 21 | Func2 (GPIO) | n/a | n/a |
| LED | GREEN | 10 | 25 | Func2 (GPIO) | n/a | n/a |

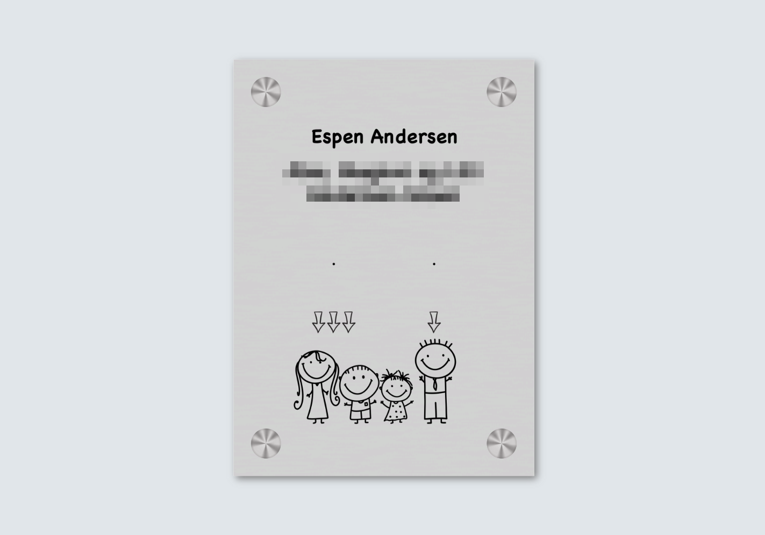
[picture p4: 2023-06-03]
gfx/button_panel_design.png

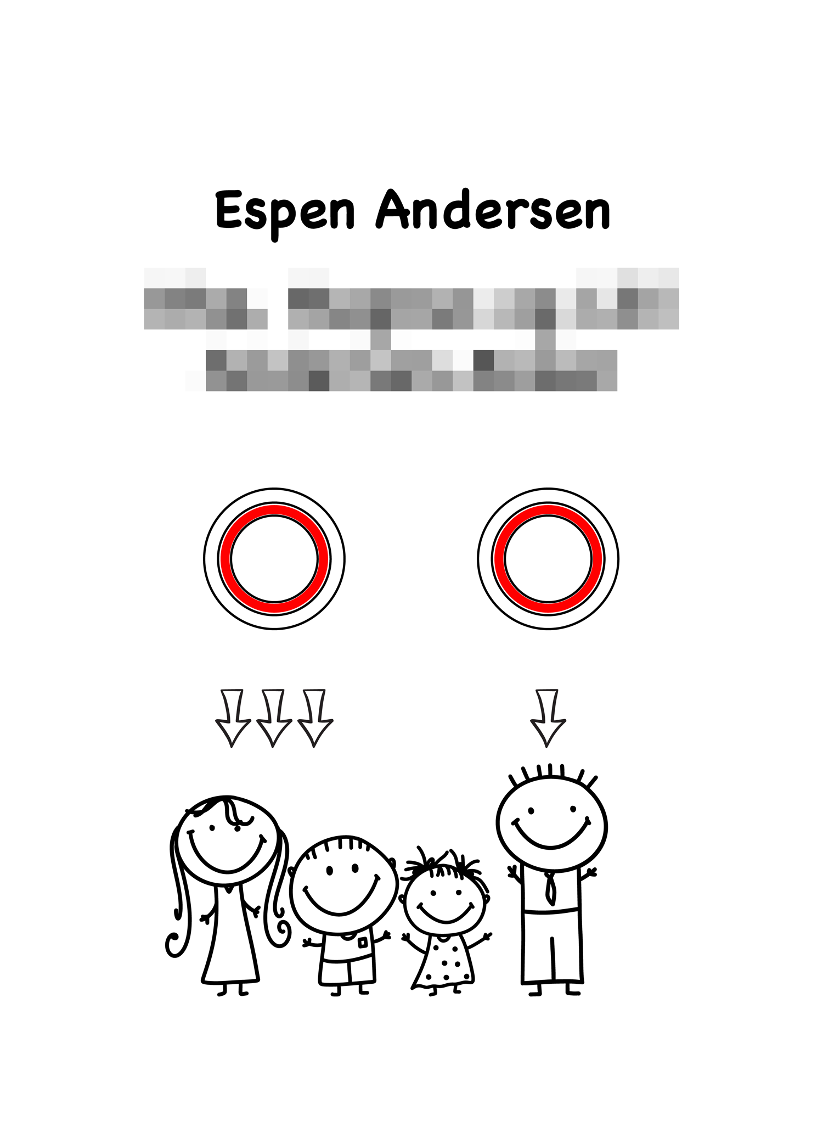
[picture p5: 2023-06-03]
gfx/button_panel_draft.png

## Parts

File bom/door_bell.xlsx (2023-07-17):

Ref | Qnty | Value | Cmp name | Footprint | Description | Mouser part | Vendor part | Vendor | Description | RoHS | Order | Unit price | Total price | Production cost
BT1 | 1 | CR2032 | Battery | Battery:BatteryHolder_Keystone_1058_1x2032 | Multiple-cell battery | 534-1057TR | 1057TR | Keystone Electronics | Coin Cell Battery Holders 2032 BATT HOLDER SMT T/R OF 400 PCS | RoHS Compliant | 10 | kr 15.27 | kr 152.70 | kr 15.27
C1, C4, C5, C6, C8, C9, C11, C16, C17 | 9 | 100nF | C | Capacitor_SMD:C_0805_2012Metric_Pad1.18x1.45mm_HandSolder | Unpolarized capacitor | 791-0805B104J100CT | 0805B104J100CT | Walsin | Multilayer Ceramic Capacitors MLCC - SMD/SMT 0805 MLCC X7R 0.1 uF, +/- 5% 10 V T&R GP | RoHS Compliant | 100 | kr 0.33 | kr 32.60 | kr 2.97
C2, C3, C13, C14, C18 | 4 | C_Decoupling | C_Decoupling | Capacitor_SMD:C_0805_2012Metric_Pad1.18x1.45mm_HandSolder | Unpolarized capacitor, small symbol | 791-0805B104J100CT | 0805B104J100CT | Walsin | Multilayer Ceramic Capacitors MLCC - SMD/SMT 0805 MLCC X7R 0.1 uF, +/- 5% 10 V T&R GP | RoHS Compliant | 100 | kr 0.33 | kr 32.60 | kr 1.30
C2, C7 | 2 | 220uF | C_Polarized | Capacitor_SMD:C_Elec_8x10.2 | Polarized capacitor | 581-APZ0609221M025R | APZ0609221M025R | KYOCERA AVX | Aluminium Organic Polymer Capacitors 25V 220uF 2000Hours ESR=30mOhms 20% | RoHS Compliant | 10 | kr 9.85 | kr 98.50 | kr 19.70
C10 | 1 | 22µF | C_Polarized | Capacitor_SMD:C_0805_2012Metric_Pad1.18x1.45mm_HandSolder | Polarized capacitor | 187-CL21X226MRQNNNE | CL21X226MRQNNNE | Samsung Electro-Mechanics | Multilayer Ceramic Capacitors MLCC - SMD/SMT 22uF+/-20% 4V X6S 20 0805 | RoHS Compliant | 100 | kr 0.44 | kr 44.30 | kr 0.44
C12, C15, C19, C20 | 4 | 1µF | C | Capacitor_SMD:C_0805_2012Metric_Pad1.18x1.45mm_HandSolder | Unpolarized capacitor | 187-CL21B105KOFNNNE | CL21B105KOFNNNE | Samsung Electro-Mechanics | Multilayer Ceramic Capacitors MLCC - SMD/SMT SAMSUNG | RoHS Compliant | 100 | kr 0.27 | kr 26.80 | kr 1.07
D1 | 1 | HDS20M | D_Bridge_+A-A | Diode_SMD_espena:D_HDS20M_Rectifier | Diode bridge, +ve/AC/-ve/AC | 621-HDS20M-13 | HDS20M-13 | Diodes Incorporated | Bridge Rectifiers Bridge Rectifier HDS | RoHS Compliant By Exemption | 10 | kr 4.77 | kr 47.70 | kr 4.77
D2 | 1 | MRA40073TG | D_Filled | Diode_SMD:D_SMB_Handsoldering | Diode, filled shape | 863-NRVA4007T3G | NRVA4007T3G | onsemi | Rectifiers Power Rectifier, Standard Recovery, 1 A, 1000 V | RoHS Compliant By Exemption | 10 | kr 3.29 | kr 32.90 | kr 3.29
D3 | 1 | TVSP | D_TVS_Filled | WE-TVSP Power TVS Diode | Bidirectional transient-voltage-suppression diode, filled shape | 710-824521131 | 824521131 | Wurth | ESD Suppressors / TVS Diodes ESD protection diode STAND Unidirectiona | RoHS Compliant | 20 | kr 3.51 | kr 70.20 | kr 3.51
D4, D5, D6, D9, D10, D11, D12 | 7 | TVS | D_Filled | Diode_SMD:D_SOD-923 | Bidirectional transient-voltage-suppression diode, filled shape | 757-DF2S12FSL3M | DF2S12FS,L3M | Toshiba | ESD Suppressors / TVS Diodes ESD protection diode STAND Unidirectiona | RoHS Compliant | 100 | kr 0.78 | kr 78.10 | kr 5.47
D7 | 1 | RED | LED_Filled | LED_SMD:LED_0805_2012Metric_Pad1.15x1.40mm_HandSolder | Light emitting diode, filled shape | 645-599-0110-002F | 599-0110-002F | Dialight | Standard LEDs - SMD SM LED 0805 RED SMPL STRP | RoHS Compliant | 20 | kr 4.29 | kr 85.80 | kr 4.29
D8 | 1 | GREEN | LED_Filled | LED_SMD:LED_0805_2012Metric_Pad1.15x1.40mm_HandSolder | Light emitting diode, filled shape | 645-599-0181-007F | 599-0181-007F | Dialight | Standard LEDs - SMD SMD 0805 GREEN | RoHS Compliant | 20 | kr 3.89 | kr 77.80 | kr 3.89
F1 | 1 | 1A | Fuse | Fuse_espena:FuseHolder_Keystone_3554 | Fuse | 693-0034.6615 | 0034.6615 | Schurter | Fuses with Leads - Through Hole MST 250 1A T 4.3 | RoHS Compliant | 10 | kr 4.61 | kr 46.10 | kr 4.61
J1 | 1 | 8-10V AC/DC | Screw_Terminal_01x02 | TerminalBlock_Phoenix_espena:TerminalBlock_Phoenix_PT-1,5-2-3.5-H_1x02_P3.50mm_Horizontal_stackable | Generic screw terminal, single row, 01x02, script generated (kicad-library-utils/schlib/autogen/connector/) | 651-1984617 | 1984617 | Phoenix Contact | Fixed Terminal Blocks PT 1.5/2-3.5H 2POS HRZ 3.5mm SCREW | RoHS Compliant By Exemption | 10 | kr 5.80 | kr 58.00 | kr 5.80
J2 | 1 | Speaker | Screw_Terminal_01x02 | TerminalBlock_Phoenix_espena:TerminalBlock_Phoenix_PT-1,5-2-3.5-H_1x02_P3.50mm_Horizontal_stackable | Generic screw terminal, single row, 01x02, script generated (kicad-library-utils/schlib/autogen/connector/) | 651-1984617 | 1984617 | Phoenix Contact | Fixed Terminal Blocks PT 1.5/2-3.5H 2POS HRZ 3.5mm SCREW | RoHS Compliant By Exemption | 10 | kr 5.80 | kr 58.00 | kr 5.80
J3 | 1 | SWITCH1 | Screw_Terminal_01x03 | TerminalBlock_Phoenix_espena:TerminalBlock_Phoenix_PT-1,5-3-3.5-H_1x03_P3.50mm_Horizontal_stackable | Generic screw terminal, single row, 01x03, script generated (kicad-library-utils/schlib/autogen/connector/) | 651-1984620 | 1984620 | Phoenix Contact | Fixed Terminal Blocks PT 1.5/3-3.5H 3POS HRZ 3.5mm SCREW | RoHS Compliant By Exemption | 10 | kr 8.57 | kr 85.70 | kr 8.57
J4 | 1 | Door panel | Screw_Terminal_01x08 | TerminalBlock_Phoenix_espena:TerminalBlock_Phoenix_PT-1,5-8-3.5-H_1x08_P3.50mm_Horizontal_stackable | Generic screw terminal, single row, 01x08, script generated (kicad-library-utils/schlib/autogen/connector/) | 651-1984675 | 1984675 | Phoenix Contact | Fixed Terminal Blocks PT 1.5/8-3.5H 8POS HRZ 3.5mm SCREW | RoHS Compliant By Exemption | 2 | kr 22.74 | kr 45.48 | kr 22.74
J5 | 1 | UART | Conn_01x03 | Connector_PinHeader_1.27mm:PinHeader_1x03_P1.27mm_Vertical | Generic connector, single row, 01x03, script generated (kicad-library-utils/schlib/autogen/connector/) | 855-M50-3530342 | M50-3530342 | Harwin | Headers & Wire Housings 3 WAY SIL VERT PC TAIL P/HDR | RoHS Compliant | 50 | kr 1.32 | kr 66.00 | kr 1.32
J6 | 1 | JTAG | Conn_01x07 | Connector_PinHeader_1.27mm:PinHeader_1x07_P1.27mm_Vertical | Generic connector, single row, 01x07, script generated (kicad-library-utils/schlib/autogen/connector/) | 855-M52-040023V0745 | M52-040023V0745 | Harwin | Headers & Wire Housings 07 SIL PCT MALE PIN HDR | RoHS Compliant | 10 | kr 10.46 | kr 104.60 | kr 10.46
J7 | 1 | BOOT | Conn_01x02 | Connector_PinHeader_1.27mm:PinHeader_1x02_P1.27mm_Vertical | Generic connector, single row, 01x02, script generated (kicad-library-utils/schlib/autogen/connector/) | 855-M50-3530242 | M50-3530242 | Harwin | Headers & Wire Housings 2 WAY SIL VERT PC TAIL P/HDR | RoHS Compliant | 50 | kr 1.06 | kr 53.00 | kr 1.06
J8 | 1 | MicroSD | Micro_SD_Card_Det_Hirose_DM3AT | Connector_Card:microSD_HC_Hirose_DM3AT-SF-PEJM5 | Micro SD Card Socket with card detection pins | 798-DM3ATSFPEJM511 | DM3AT-SF-PEJM5(11) | Hirose Electric | Memory Card Connectors 8P R/A SMT MICRO SD PUSH-PUSH | RoHS Compliant | 4 | kr 27.63 | kr 110.52 | kr 27.63
K1 | 1 | HJR 1-2C | TIANBO-HJR-1-2C-L-05V | Relay_THT_espena:Relay_Tianbo_HJR-1-2C | TIANBO HJR 1-2C L-05V, Two Pole Relay, 2.54mm Pitch, 1A | (eBay) |  |  |  |  | 50 | kr 8.90 | kr 445.00 | kr 8.90
Q1 | 1 | BC847 | BC847 | Package_TO_SOT_SMD:SOT-23 | 0.1A Ic, 45V Vce, NPN Transistor, SOT-23 | 863-BC847BLT1G | BC847BLT1G | onsemi | Bipolar Transistors - BJT 100mA 50V NPN | RoHS Compliant | 100 | kr 0.77 | kr 77.00 | kr 0.77
R1, R2 | 2 | 1k | R | Resistor_SMD:R_0805_2012Metric_Pad1.20x1.40mm_HandSolder | Resistor | 652-CR0805FX-1001ELF | CR0805-FX-1001ELF | Bourns | Thick Film Resistors - SMD 1K 1% | RoHS Compliant By Exemption | 1000 | kr 0.07 | kr 70.00 | kr 0.14
R3, R4, R9, R10, R13, R18, R19, R20, R21, R22 | 10 | 10k | R | Resistor_SMD:R_0805_2012Metric_Pad1.20x1.40mm_HandSolder | Resistor | 652-CR0805FX-1002ELF | CR0805-FX-1002ELF | Bourns | Thick Film Resistors - SMD 10K 1% | RoHS Compliant By Exemption | 100 | kr 0.13 | kr 12.80 | kr 1.28
R5, R6, R7, R8 | 4 | 2,4k | R | Resistor_SMD:R_0805_2012Metric_Pad1.20x1.40mm_HandSolder | Resistor | 652-CR0805FX-1002ELF | CR0805-FX-1002ELF | Bourns | Thick Film Resistors - SMD 10K 1% | RoHS Compliant By Exemption | 100 | kr 0.13 | kr 12.80 | kr 0.51
R11, R12 | 2 | 100Ω | R | Resistor_SMD:R_0805_2012Metric_Pad1.20x1.40mm_HandSolder | Resistor | 652-CR0805FX-1000ELF | CR0805-FX-1000ELF | Bourns | Thick Film Resistors - SMD 100ohm 1% | RoHS Compliant By Exemption | 100 | kr 0.13 | kr 12.80 | kr 0.26
R14, R15, R16, R17 | 4 | 75Ω | R | Resistor_SMD:R_0805_2012Metric_Pad1.20x1.40mm_HandSolder | Resistor | 652-CR0805FX-75R0ELF | CR0805-FX-75R0ELF | Bourns | Thick Film Resistors - SMD 75ohm 1% | RoHS Compliant By Exemption | 100 | kr 0.13 | kr 12.80 | kr 0.51
R22, R23 | 2 | 100k | R | Resistor_SMD:R_0805_2012Metric_Pad1.20x1.40mm_HandSolder | Resistor | 652-CR0805FX-1003ELF | CR0805-FX-1003ELF | Bourns | Thick Film Resistors - SMD 100K 1% | RoHS Compliant By Exemption | 100 | kr 0.13 | kr 12.80 | kr 0.26
SW1, SW2 | 2 | Reset,Boot | SW_Push | Button_Switch_SMD_espena:SW_SPST_TL3301_6x6mm_H4.3mm | Push button switch, generic, two pins | 612-LL3301NF065QG | LL3301NF065QG | E-Switch | Tactile Switches 50mA 12VDC F065 4.3mm Gull Wing |  | 10 | kr 7.39 | kr 73.90 | kr 14.78
U1 | 1 | NCP1117-5v | NCP1117-5.0_SOT223 | Package_TO_SOT_SMD:SOT-223-3_TabPin2 | 1A Low drop-out regulator, Fixed Output 5.0V, SOT-223 | 637-LDI1117-05H | LDI1117-05H | Diotec Semiconductor | LDO Voltage Regulators VR, SOT-223, 20V, 4.95V, 5.05V | RoHS Compliant | 20 | kr 5.28 | kr 105.60 | kr 5.28
U2 | 1 | MAX98357A | MAX98357A_1 | Package_DFN_QFN_espena:TQFN-16-1EP_3x3mm_P0.5mm_EP1.23x1.23mm | PCM Class D Amplifier | 700-MAX98357AETE+T | MAX98357AETE+T | Analog Devices Inc. | Audio Amplifiers Digital Input Class D Amplifier | RoHS Compliant | 5 | kr 31.37 | kr 156.85 | kr 31.37
U3 | 1 | NCP1117-3v3 | NCP1117-3.3_SOT223 | Package_TO_SOT_SMD:SOT-223-3_TabPin2 | 1A Low drop-out regulator, Fixed Output 3.3V, SOT-223 | 637-LDI1117-3.3H | LDI1117-3.3H | Diotec Semiconductor | LDO Voltage Regulators VR, SOT-223, 20V, 3.267V, 3.333V | RoHS Compliant | 10 | kr 5.28 | kr 52.80 | kr 5.28
U4 | 1 | DS3231M | DS3231M | Package_SO:SOIC-16W_7.5x10.3mm_P1.27mm | Extremely Accurate I2C-Integrated RTC/TCXO/Crystal SOIC-16 | 700-DS3231M+ | DS3231M+ | Analog Devices Inc. | Real Time Clock +/-5ppm, I C Real-Time Clock | RoHS Compliant | 3 | kr 116.48 | kr 349.44 | kr 116.48
U5 | 1 | MAX3232 | MAX3232 | Package_SO_espena:TSSOP-16-1EP_4.4x5mm_P0.65mm | 3.0V to 5.5V, Low-Power, up to 1Mbps, True RS-232 Transceivers Using Four 0.1μF External Capacitors | 595-MAX3232IPWR | MAX3232IPWR | Texas Instruments | RS-232 Interface IC 3-5.5V Mult-Ch RS232 | RoHS Compliant | 10 | kr 8.91 | kr 89.10 | kr 8.91
U6 | 1 | ESP32-WROVER-B | ESP32-WROVER-B_1 | RF_Module_espena:ESP32-WROVER-B | RF Module, ESP32-D0WDQ6 SoC, Wi-Fi 802.11b/g/n, 32-bit, 2.7-3.6V, onboard antenna, SMD | 356-ESP32WRVE26464PC | ESP32-WROVER-E-N8R8 | Espressif | Multiprotocol Modules SMD Module ESP32-WROVER-E, ESP32-D0WD-V3, 3.3V 64Mbit PSRAM, 8 MB SPI flash, PCB Antenna | RoHS Compliant | 5 | kr 39.41 | kr 197.05 | kr 39.41
U7 | 1 | 74LVC2G14 | 74LVC2G14 | Package_TO_SOT_SMD:TSOT-23-6_HandSoldering | Dual NOT Gate Schmitt Triggered, Low-Voltage CMOS | 595-SN74LVC2G14DBVR | SN74LVC2G14DBVR | Texas Instruments | Inverters Dual Schmitt-Trigger | RoHS Compliant | 10 | kr 3.84 | kr 38.40 | kr 3.84
Enclosure | 1 | P1A-303012 | Vented enclosure, white |  |  | 789-P1A-303012 | P1A-303012 | New Age Enclosures | Enclosures, Boxes & Cases Vented Cube | RoHS Compliant | 2 | kr 47.81 | kr 95.62 | kr 47.81
Speaker | 1 | CES-603318-24PM | Enclosed speaker, 4ohm, 2W |  |  | 490-CES-603318-24PM | CES-603318-24PM | CUI Devices | Speakers & Transducers speaker, 60 x 33mm rectangle, 2W, 4ohm |  | 1 | 61.33 | kr 61.33 | kr 61.33
 |  |  |  |  |  |  |  |  |  |  |  |  |  | kr 501.08

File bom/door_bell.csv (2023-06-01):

Source: | /Users/espen/Projects/KiCad/projects/dual-button-doorbell/door_bell.kicad_sch
Date: | Wednesday, 31 May 2023 at 19:23:15
Tool: | Eeschema (7.0.0-0)
Generator: | /Applications/KiCad/KiCad.app/Contents/SharedSupport/plugins/bom_csv_grouped_by_value_with_fp.py
Component Count: | 75
Ref | Qnty | Value | Cmp name | Footprint | Description | Vendor | DNP
BT1 | 1 | CR2032 | Battery | Battery:BatteryHolder_Keystone_1058_1x2032 | Multiple-cell battery
C1, C4, C5, C6, C8, C9, C11, C16, C17 | 9 | 100nF | C | Capacitor_SMD:C_0805_2012Metric_Pad1.18x1.45mm_HandSolder | Unpolarized capacitor
C2, C13, C14, C18 | 4 | C_Decoupling | C_Decoupling | Capacitor_SMD:C_0805_2012Metric_Pad1.18x1.45mm_HandSolder | Unpolarized capacitor, small symbol
C3, C7 | 2 | 220uF | C_Polarized | Capacitor_SMD:C_Elec_8x10.2 | Polarized capacitor
C10 | 1 | 22µF | C_Polarized | Capacitor_SMD:C_0805_2012Metric_Pad1.18x1.45mm_HandSolder | Polarized capacitor
C12, C15, C19, C20 | 4 | 1µF | C | Capacitor_SMD:C_0805_2012Metric_Pad1.18x1.45mm_HandSolder | Unpolarized capacitor
D1 | 1 | HDS20M | D_Bridge_+A-A | Diode_SMD_espena:D_HDS20M_Rectifier | Diode bridge, +ve/AC/-ve/AC
D2 | 1 | S1A-13-F | D_Filled | Diode_SMD:D_SMB_Handsoldering | Diode, filled shape
D3, D4, D5, D8, D9, D10, D11 | 7 | TVS | D_TVS_Filled | Diode_SMD:D_SOD-923 | Bidirectional transient-voltage-suppression diode, filled shape
D6 | 1 | RED | LED_Filled | LED_SMD:LED_0805_2012Metric_Pad1.15x1.40mm_HandSolder | Light emitting diode, filled shape
D7 | 1 | GREEN | LED_Filled | LED_SMD:LED_0805_2012Metric_Pad1.15x1.40mm_HandSolder | Light emitting diode, filled shape
F1 | 1 | 1A | Fuse | Fuse_espena:FuseHolder_Keystone_3554 | Fuse
J1 | 1 | 8-10V AC/DC | Screw_Terminal_01x02 | TerminalBlock_Phoenix_espena:TerminalBlock_Phoenix_PT-1,5-2-3.5-H_1x02_P3.50mm_Horizontal_stackable | Generic screw terminal, single row, 01x02, script generated (kicad-library-utils/schlib/autogen/connector/)
J2 | 1 | Speaker | Screw_Terminal_01x02 | TerminalBlock_Phoenix_espena:TerminalBlock_Phoenix_PT-1,5-2-3.5-H_1x02_P3.50mm_Horizontal_stackable | Generic screw terminal, single row, 01x02, script generated (kicad-library-utils/schlib/autogen/connector/)
J3 | 1 | SWITCH1 | Screw_Terminal_01x03 | TerminalBlock_Phoenix_espena:TerminalBlock_Phoenix_PT-1,5-3-3.5-H_1x03_P3.50mm_Horizontal_stackable | Generic screw terminal, single row, 01x03, script generated (kicad-library-utils/schlib/autogen/connector/)
J4 | 1 | Door panel | Screw_Terminal_01x08 | TerminalBlock_Phoenix_espena:TerminalBlock_Phoenix_PT-1,5-8-3.5-H_1x08_P3.50mm_Horizontal_stackable | Generic screw terminal, single row, 01x08, script generated (kicad-library-utils/schlib/autogen/connector/)
J5 | 1 | UART | Conn_01x03 | Connector_PinHeader_1.27mm:PinHeader_1x03_P1.27mm_Vertical | Generic connector, single row, 01x03, script generated (kicad-library-utils/schlib/autogen/connector/)
J6 | 1 | JTAG | Conn_01x07 | Connector_PinHeader_1.27mm:PinHeader_1x07_P1.27mm_Vertical | Generic connector, single row, 01x07, script generated (kicad-library-utils/schlib/autogen/connector/)
J7 | 1 | BOOT | Conn_01x02 | Connector_PinHeader_1.27mm:PinHeader_1x02_P1.27mm_Vertical | Generic connector, single row, 01x02, script generated (kicad-library-utils/schlib/autogen/connector/)
J8 | 1 | MicroSD | Micro_SD_Card_Det_Hirose_DM3AT | Connector_Card:microSD_HC_Hirose_DM3AT-SF-PEJM5 | Micro SD Card Socket with card detection pins
K1 | 1 | HJR 1-2C | TIANBO-HJR-1-2C-L-05V | Relay_THT_espena:Relay_Tianbo_HJR-1-2C | TIANBO HJR 1-2C L-05V, Two Pole Relay, 2.54mm Pitch, 1A
Q1 | 1 | BC847 | BC847 | Package_TO_SOT_SMD:SOT-23 | 0.1A Ic, 45V Vce, NPN Transistor, SOT-23
R1, R2 | 2 | 1k | R | Resistor_SMD:R_0805_2012Metric_Pad1.20x1.40mm_HandSolder | Resistor
R3, R4, R5, R6, R7, R10, R15, R16, R17, R18, R19, R20, R21 | 13 | 10k | R | Resistor_SMD:R_0805_2012Metric_Pad1.20x1.40mm_HandSolder | Resistor
R8, R9 | 2 | 100Ω | R | Resistor_SMD:R_0805_2012Metric_Pad1.20x1.40mm_HandSolder | Resistor
R11, R12, R13, R14 | 4 | 75Ω | R | Resistor_SMD:R_0805_2012Metric_Pad1.20x1.40mm_HandSolder | Resistor
R22, R23 | 2 | 100k | R | Resistor_SMD:R_0805_2012Metric_Pad1.20x1.40mm_HandSolder | Resistor
SW1 | 1 | Reset | SW_Push | Button_Switch_SMD_espena:SW_SPST_TL3301_6x6mm_H4.3mm | Push button switch, generic, two pins
TP1 | 1 | Ground | TestPoint | TestPoint:TestPoint_Loop_D3.50mm_Drill0.9mm_Beaded | test point
U1 | 1 | NCP1117-5v | NCP1117-3.3_SOT223 | Package_TO_SOT_SMD:SOT-223-3_TabPin2 | 1A Low drop-out regulator, Fixed Output 3.3V, SOT-223
U2 | 1 | MAX98357A | MAX98357A_1 | Package_DFN_QFN_espena:TQFN-16-1EP_3x3mm_P0.5mm_EP1.23x1.23mm | PCM Class D Amplifier
U3 | 1 | NCP1117-3v3 | NCP1117-3.3_SOT223 | Package_TO_SOT_SMD:SOT-223-3_TabPin2 | 1A Low drop-out regulator, Fixed Output 3.3V, SOT-223
U4 | 1 | DS3231M | DS3231M | Package_SO:SOIC-16W_7.5x10.3mm_P1.27mm | Extremely Accurate I2C-Integrated RTC/TCXO/Crystal SOIC-16
U5 | 1 | MAX3232 | MAX3232 | Package_SO_espena:TSSOP-16-1EP_4.4x5mm_P0.65mm | 3.0V to 5.5V, Low-Power, up to 1Mbps, True RS-232 Transceivers Using Four 0.1μF External Capacitors
U6 | 1 | ESP32-WROVER-B | ESP32-WROVER-B_1 | RF_Module_espena:ESP32-WROVER-B | RF Module, ESP32-D0WDQ6 SoC, Wi-Fi 802.11b/g/n, 32-bit, 2.7-3.6V, onboard antenna, SMD
U7 | 1 | 74LVC2G14 | 74LVC2G14 | Package_TO_SOT_SMD:TSOT-23-6_HandSoldering | Dual NOT Gate Schmitt Triggered, Low-Voltage CMOS

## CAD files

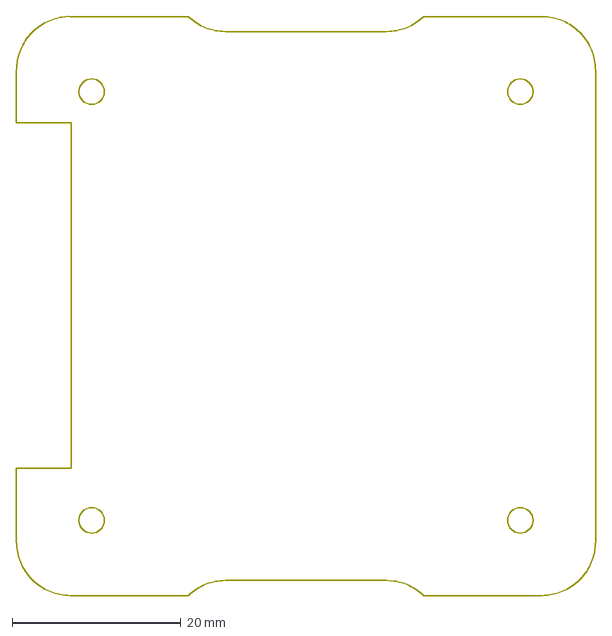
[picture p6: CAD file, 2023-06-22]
board_outline.dxf
68.6 x 68.6 mm

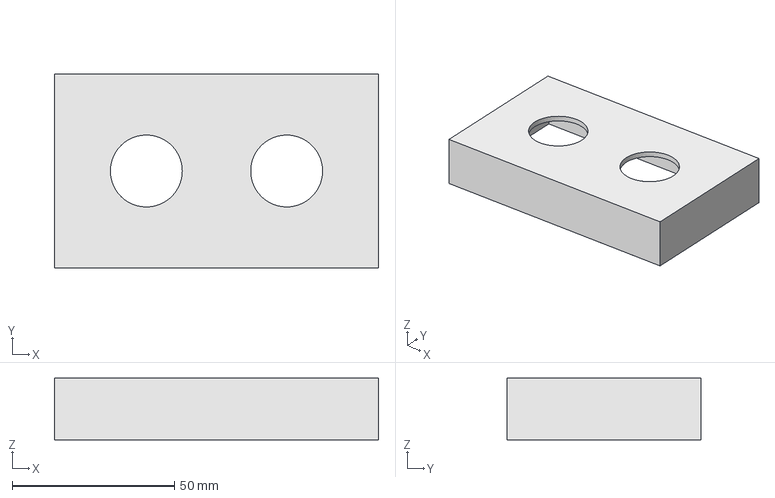
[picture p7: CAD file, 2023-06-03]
frontpanel_enclosure/frontpanel_enclosure.step
100.0 x 60.0 x 19.0 mm

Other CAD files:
gfx/espena_logo.dxf
frontpanel_enclosure/frontpanel_enclosure.FCStd
frontpanel_enclosure/frontpanel_enclosure.stl

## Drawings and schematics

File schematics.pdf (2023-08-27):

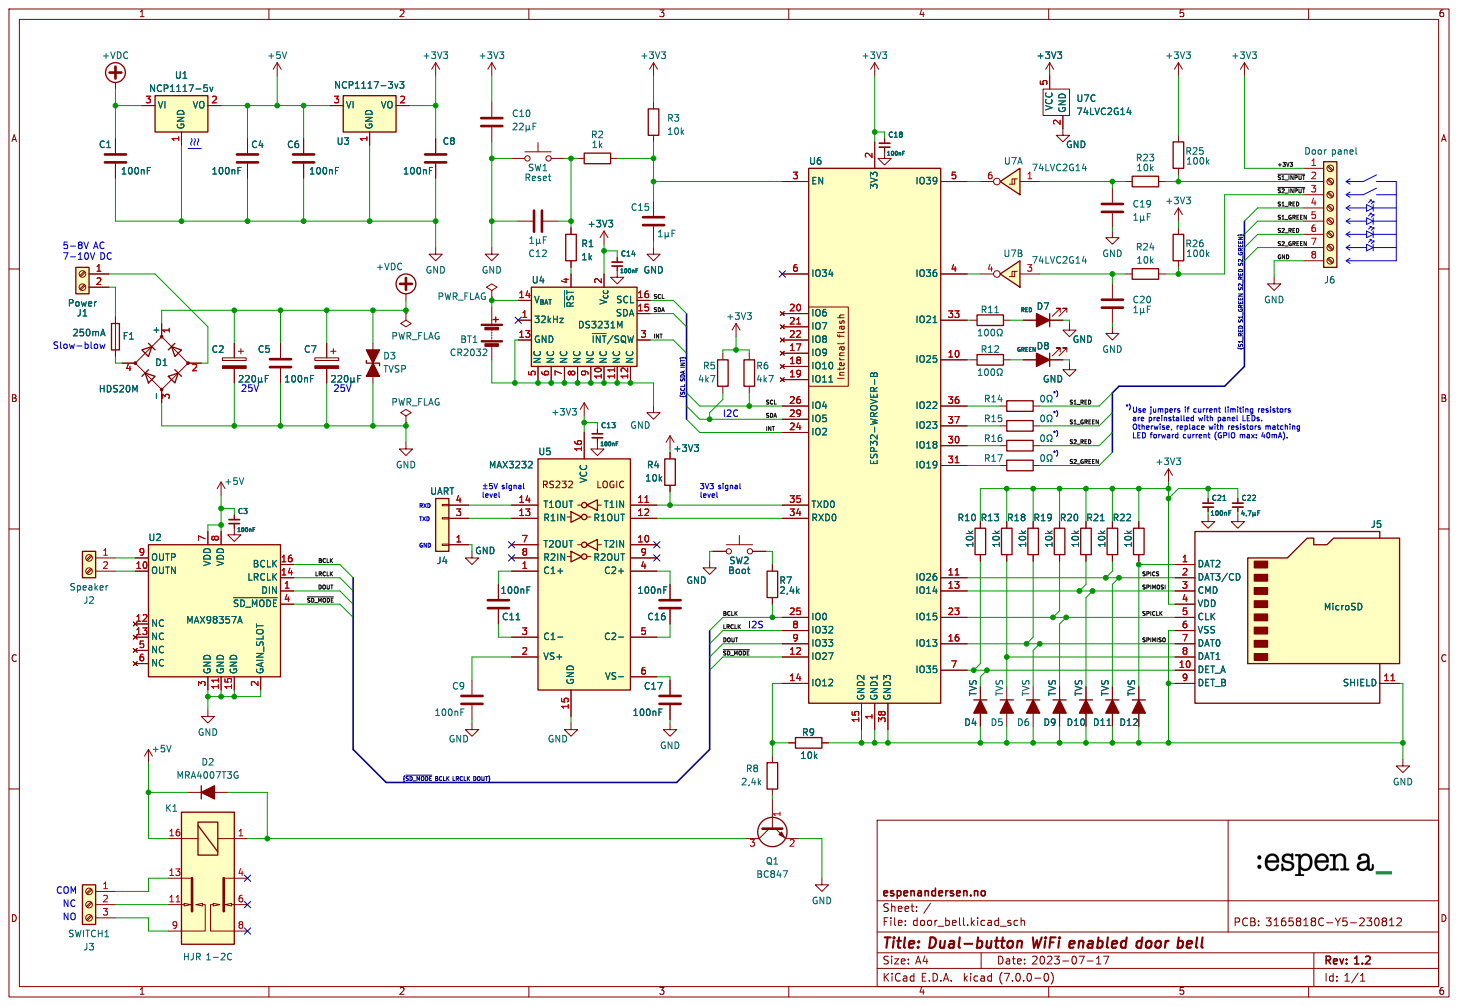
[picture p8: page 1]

LED forward current (GPIO max: 40mA). 25V

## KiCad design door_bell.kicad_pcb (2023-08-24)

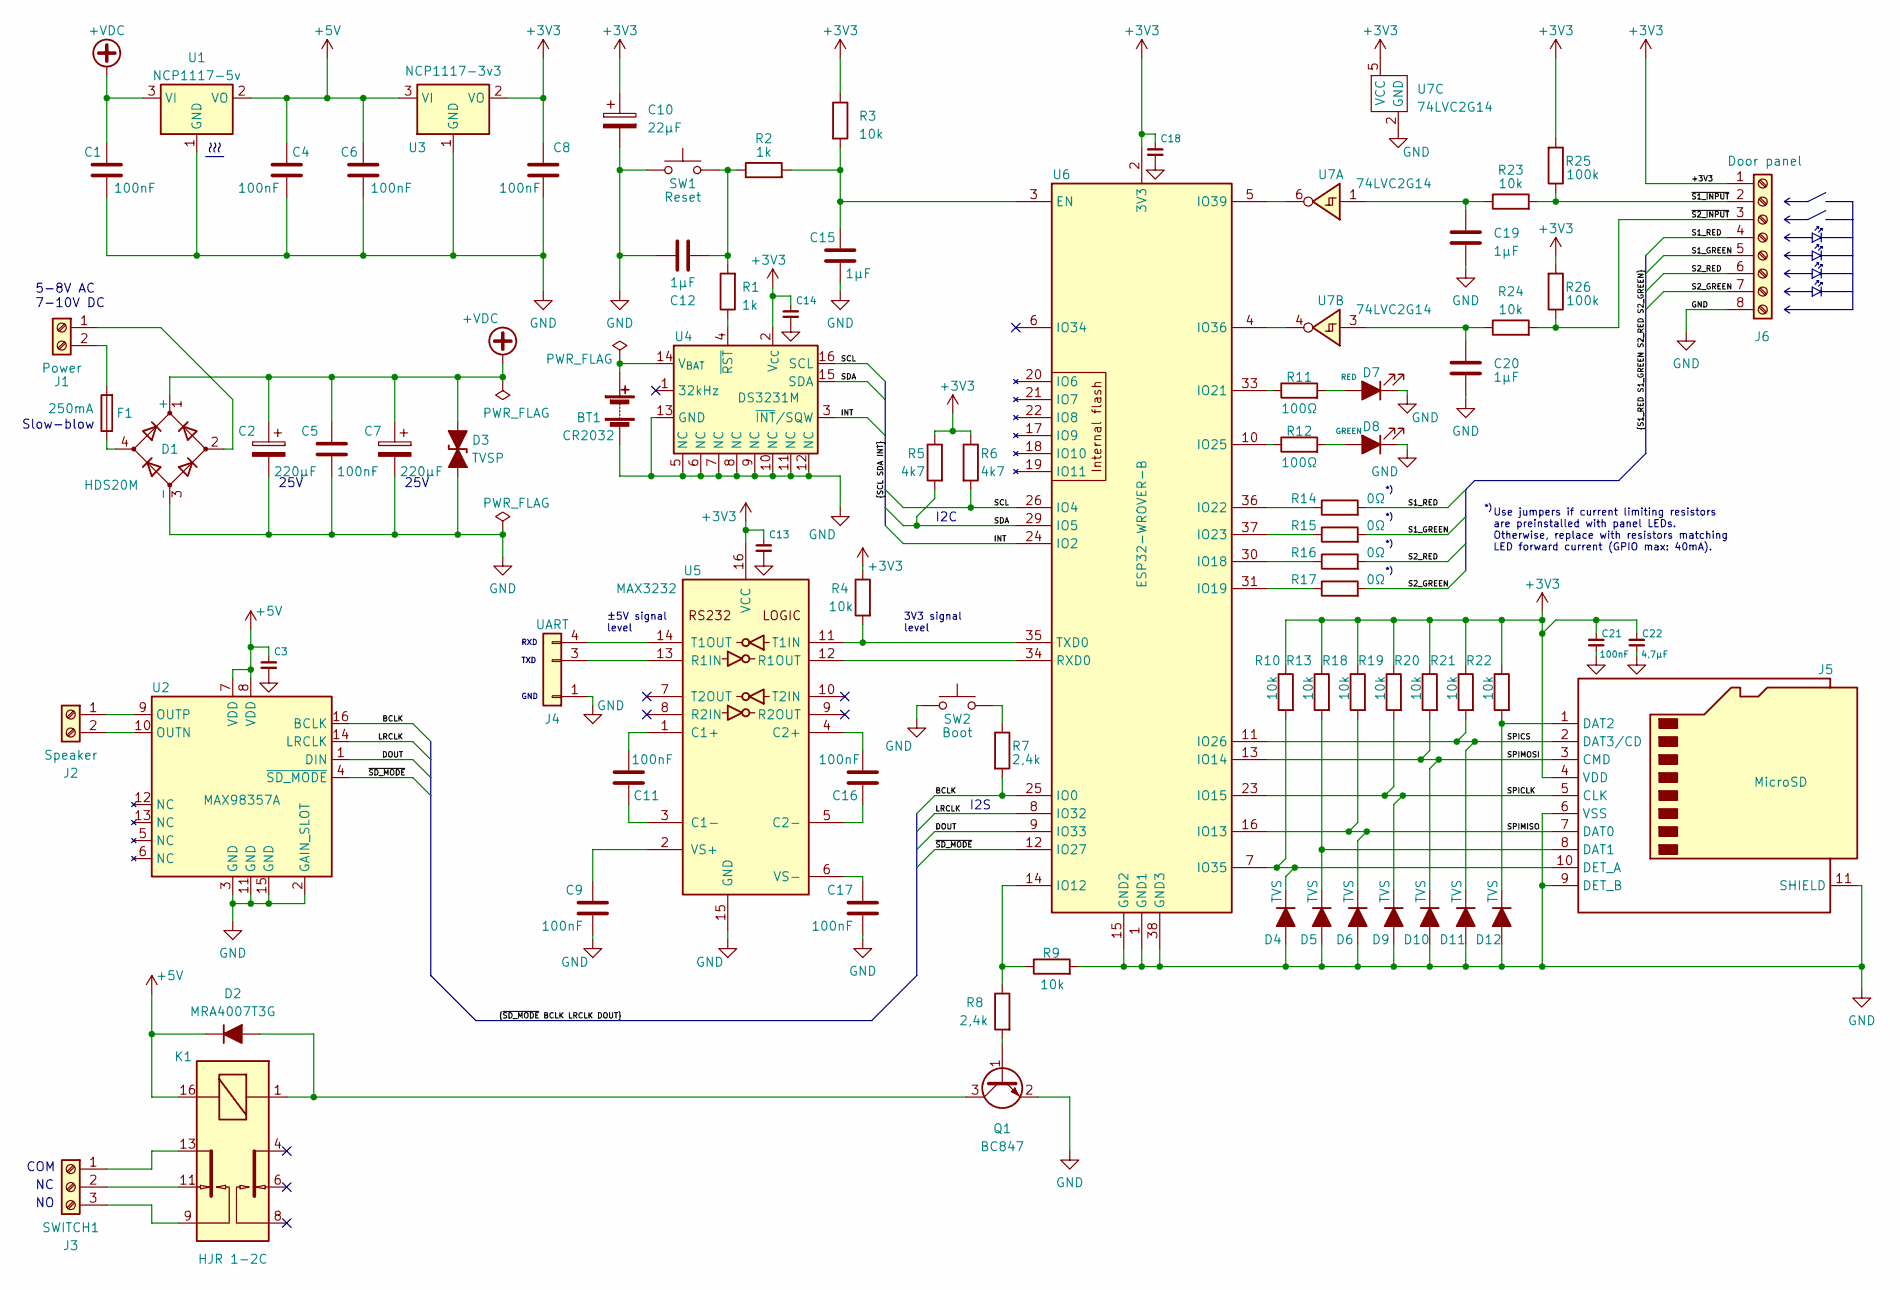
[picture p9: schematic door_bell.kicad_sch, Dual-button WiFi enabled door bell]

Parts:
BT1: CR2032; BatteryHolder_Keystone_1058_1x2032
C1, C4, C5, C6, C8, C9, C11, C16, C17, C21: 100nF; C_0805_2012Metric_Pad1.18x1.45mm_HandSolder
C2, C7: 220µF; CP_Elec_6.3x9.9
C3, C13, C14, C18: C_Decoupling; C_0805_2012Metric_Pad1.18x1.45mm_HandSolder
C10: 22µF; C_0805_2012Metric_Pad1.18x1.45mm_HandSolder
C12, C15, C19, C20: 1µF; C_0805_2012Metric_Pad1.18x1.45mm_HandSolder
C22: 4,7µF; C_0805_2012Metric_Pad1.18x1.45mm_HandSolder
D1: HDS20M; D_HDS20M_Rectifier
D2: MRA4007T3G; D_SMB_Handsoldering
D3: TVSP; DO-214AA-2
D4, D5, D6, D9, D10, D11, D12: TVS; D_SOD-523
D7: RED; LED_0805_2012Metric_Pad1.15x1.40mm_HandSolder
D8: GREEN; LED_0805_2012Metric_Pad1.15x1.40mm_HandSolder
F1: 250mA; FuseHolder_Keystone_3554
J1: Power; TerminalBlock_Phoenix_PT-1,5-2-3.5-H_1x02_P3.50mm_Horizonta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
J2: Speaker; TerminalBlock_Phoenix_PT-1,5-2-3.5-H_1x02_P3.50mm_Horizonta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
J3: SWITCH1; TerminalBlock_Phoenix_PT-1,5-3-3.5-H_1x03_P3.50mm_Horizonta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
J4: UART; PinHeader_1x04_P1.27mm_Vertical_without_pin2
J5: MicroSD; microSD_HC_Hirose_DM3AT-SF-PEJM5
J6: Door panel; TerminalBlock_Phoenix_PT-1,5-8-3.5-H_1x08_P3.50mm_Horizonta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
K1: HJR 1-2C; Relay_Tianbo_HJR-1-2C
Q1: BC847; SOT-23
R1, R2: 1k; R_0805_2012Metric_Pad1.20x1.40mm_HandSolder
R3, R4, R9, R10, R13, R18, R19, R20, R21, R22, R23, R24: 10k; R_0805_2012Metric_Pad1.20x1.40mm_HandSolder
R5, R6: 4k7; R_0805_2012Metric_Pad1.20x1.40mm_HandSolder
R7, R8: 2,4k; R_0805_2012Metric_Pad1.20x1.40mm_HandSolder
R11, R12: 100Ω; R_0805_2012Metric_Pad1.20x1.40mm_HandSolder
R14, R15, R16, R17: 0Ω; R_0805_2012Metric_Pad1.20x1.40mm_HandSolder
R25, R26: 100k; R_0805_2012Metric_Pad1.20x1.40mm_HandSolder
SW1: Reset; SW_SPST_TL3301_6x6mm_H4.3mm
SW2: Boot; SW_SPST_TL3301_6x6mm_H4.3mm
U1: NCP1117-5v; SOT-223-3_TabPin2_ThermalPads_Heatsink_x2
U2: MAX98357A; TQFN-16-1EP_3x3mm_P0.5mm_EP1.23x1.23mm
U3: NCP1117-3v3; SOT-223-3_TabPin2_ThermalPads
U4: DS3231M; SOIC-16W_7.5x10.3mm_P1.27mm
U5: MAX3232; TSSOP-16-1EP_4.4x5mm_P0.65mm
U6: ESP32-WROVER-B
U7: 74LVC2G14; TSOT-23-6

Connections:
+3V3: C8.1, C10.1, C13.1, C14.2, C18.1, C21.1, C22.1, J5.4 (VDD), J6.1, R3.1, R4.1, R5.1, R6.1, R10.1, R13.1, R18.1, R19.1, R20.1, R21.1, R22.1, R25.2, R26.2, U3.2 (VO), U4.2 (V_{CC}), U5.16 (VCC), U6.2 (3V3), U7.5 (VCC)
+5V: C3.1, C4.1, C6.1, D2.1 (K), K1.16, U1.2 (VO), U2.7 (VDD), U2.8 (VDD), U3.3 (VI)
+VDC: C1.1, C2.1, C5.1, C7.1, D1.1 (+), D3.2 (A2), U1.3 (VI)
/BCLK: R7.2, U2.16 (BCLK), U6.25 (IO0)
/DOUT: U2.1 (DIN), U6.9 (IO33)
/INT: U4.3 (~INT/SQW), U6.24 (IO2)
/LRCLK: U2.14 (LRCLK), U6.8 (IO32)
/S1_GREEN: J6.5, R15.2
/S1_RED: J6.4, R14.2
/S2_GREEN: J6.7, R17.2
/S2_RED: J6.6, R16.2
/SCL: R6.2, U4.16 (SCL), U6.26 (IO4)
/SDA: R5.2, U4.15 (SDA), U6.29 (IO5)
/SPICLK: D9.1 (K), J5.5 (CLK), R19.2, U6.23 (IO15)
/SPICS: D11.1 (K), J5.2 (DAT3/CD), R21.2, U6.11 (IO26)
/SPIMISO: D6.1 (K), J5.7 (DAT0), R18.2, U6.16 (IO13)
/SPIMOSI: D10.1 (K), J5.3 (CMD), R20.2, U6.13 (IO14)
/~S1_INPUT: J6.2, R23.2, R25.1
/~S2_INPUT: J6.3, R24.2, R26.1
/~SD_MODE: U2.4 (~SD_MODE), U6.12 (IO27)
GND: BT1.2 (-), C1.2, C2.2, C3.2, C4.2, C5.2, C6.2, C7.2, C8.2, C9.2, C10.2, C12.1, C13.2, C14.1, C15.2, C17.2, C18.2, C19.2, C20.2, C21.2, C22.2, D1.3 (-), D3.1 (A1), D4.2 (A), D5.2 (A), D6.2 (A), D7.1 (K), D8.1 (K), D9.2 (A), D10.2 (A), D11.2 (A), D12.2 (A), J4.1, J5.6 (VSS), J5.9 (DET_B), J5.11 (SHIELD), J6.8, Q1.2 (E), R9.2, SW1.1, SW2.1, U1.1 (GND), U2.2 (GAIN_SLOT), U2.3 (GND), U2.11 (GND), U2.15 (GND), U3.1 (GND), U4.5 (NC), U4.6 (NC), U4.7 (NC), U4.8 (NC), U4.9 (NC), U4.10 (NC), U4.11 (NC), U4.12 (NC), U4.13 (GND), U5.15 (GND), U6.1 (GND1), U6.15 (GND2), U6.38 (GND3), U7.2 (GND)
unnamed: BT1.1 (+), U4.14 (V_{BAT})
unnamed: C12.2, R1.2, R2.1, SW1.2
unnamed: C19.1, R23.1, U7.1
unnamed: C20.1, R24.1, U7.3
unnamed: D1.4, F1.1
unnamed: D2.2 (A), K1.1, Q1.3 (C)
unnamed: D4.1 (K), J5.10 (DET_A), R10.2, U6.7 (IO35)
unnamed: D5.1 (K), J5.8 (DAT1), R13.2
unnamed: D7.2 (A), R11.2
unnamed: D8.2 (A), R12.2
unnamed: D12.1 (K), J5.1 (DAT2), R22.2
unnamed: D1.2, J1.1
unnamed: F1.2, J1.2
unnamed: J2.1, U2.9 (OUTP)
unnamed: J2.2, U2.10 (OUTN)
unnamed: J3.1, K1.13
unnamed: J3.2, K1.11
unnamed: J3.3, K1.9
unnamed: J4.3, U5.13 (R1IN)
unnamed: J4.4, U5.14 (T1OUT)
unnamed: Q1.1 (B), R8.2
unnamed: R7.1, SW2.2
unnamed: R1.1, U4.4 (~RST)
unnamed: C11.1, U5.1 (C1+)
unnamed: C11.2, U5.3 (C1-)
unnamed: C16.1, U5.4 (C2+)
unnamed: C16.2, U5.5 (C2-)
unnamed: U5.12 (R1OUT), U6.34 (RXD0)
unnamed: R4.2, U5.11 (T1IN), U6.35 (TXD0)
unnamed: C9.1, U5.2 (VS+)
unnamed: C17.1, U5.6 (VS-)
unnamed: C15.1, R2.2, R3.2, U6.3 (EN)
unnamed: R8.1, R9.1, U6.14 (IO12)
unnamed: R16.1, U6.30 (IO18)
unnamed: R17.1, U6.31 (IO19)
unnamed: R11.1, U6.33 (IO21)
unnamed: R14.1, U6.36 (IO22)
unnamed: R15.1, U6.37 (IO23)
unnamed: R12.1, U6.10 (IO25)
unnamed: U6.4 (IO36), U7.4
unnamed: U6.5 (IO39), U7.6

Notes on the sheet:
TXD
RXD
3V3 signal level
GND
±5V signal level
25V
COM
I2S
Use jumpers if current limiting resistors are preinstalled with panel LEDs. Otherwise, replace with resistors matching LED forward current (GPIO max: 40mA).
5-8V AC 7-10V DC
Slow-blow
I2C

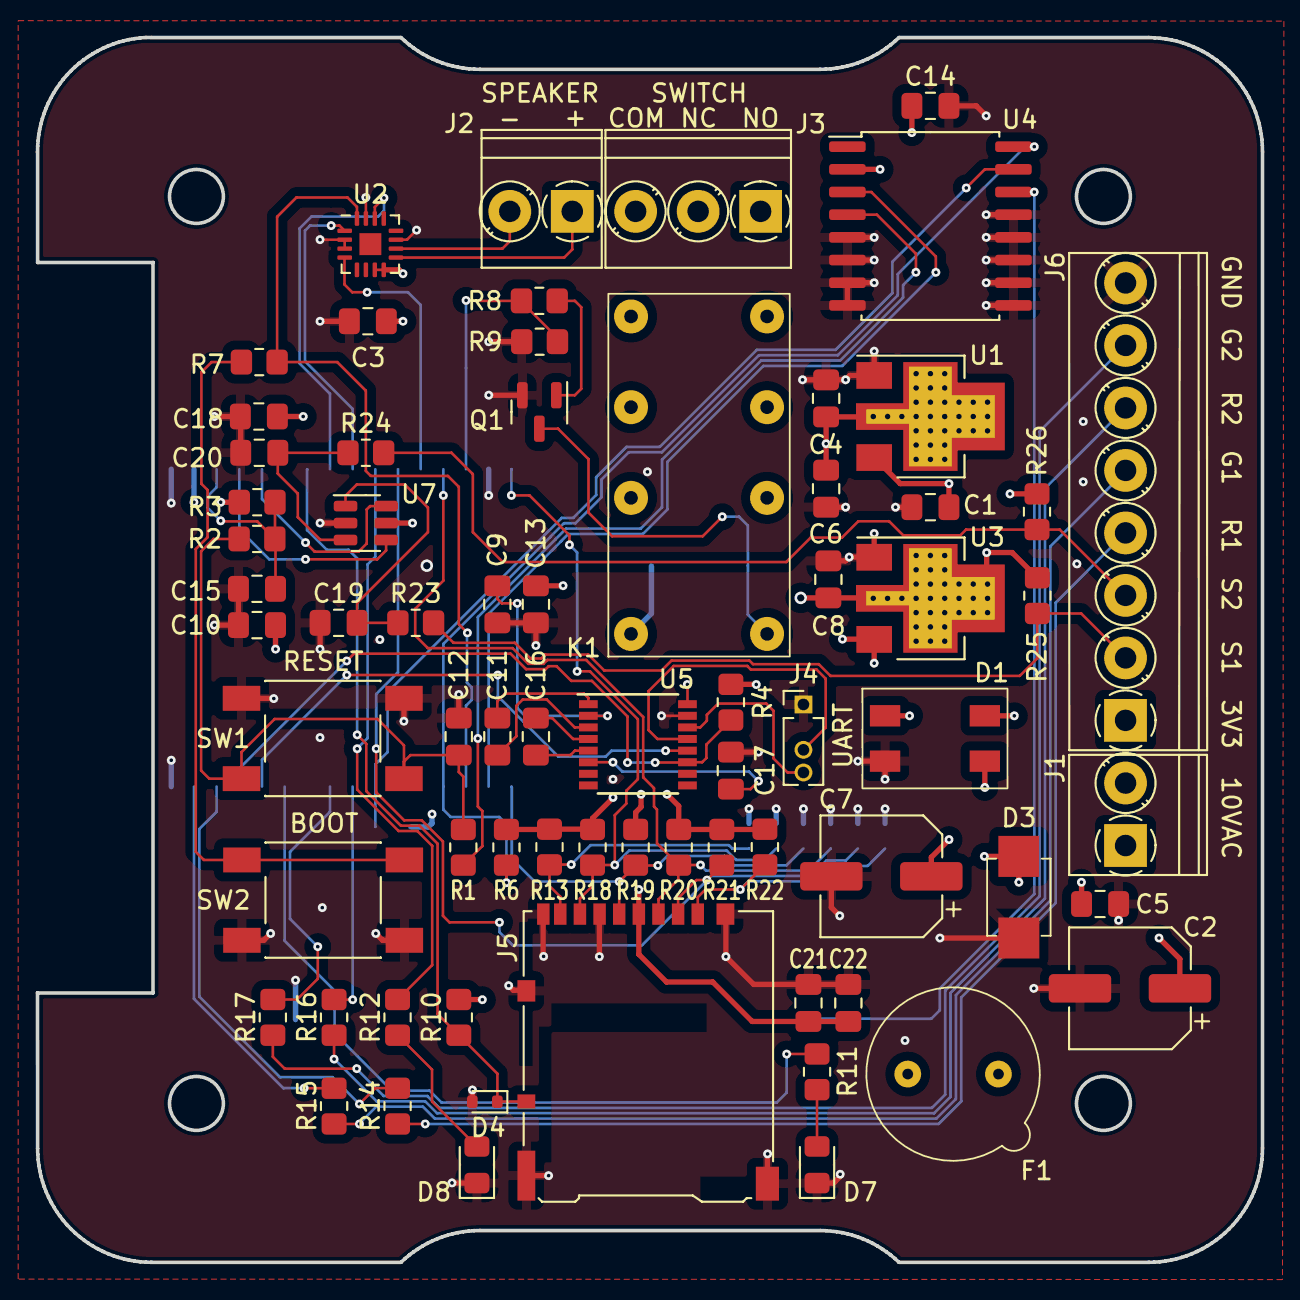
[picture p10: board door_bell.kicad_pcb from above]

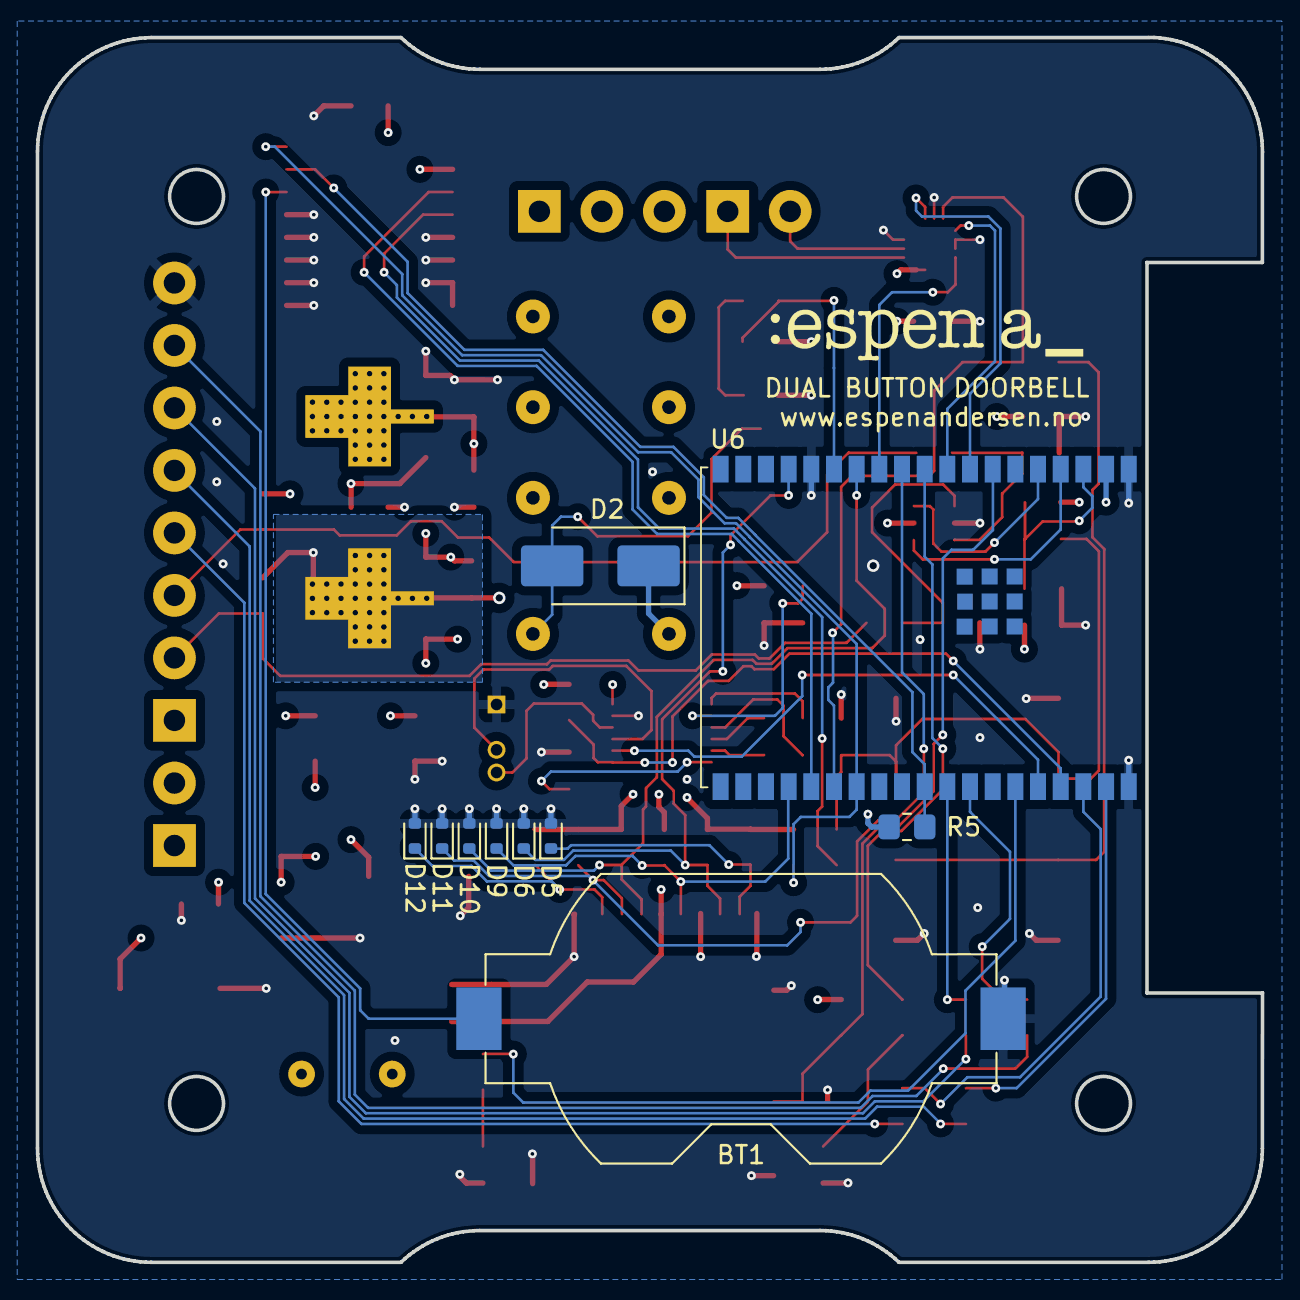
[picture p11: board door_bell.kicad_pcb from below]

Board: 4 copper layers, 68.6 x 68.6 mm, 79 parts (10 on the bottom side), 62 nets.

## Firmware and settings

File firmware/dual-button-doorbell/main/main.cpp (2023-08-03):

/*
 *  This file is part of the dual-button doorbell project.
 *  Copyright (C) 2023  Espen Andersen (espenandersen.no)
 *
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
 *  You should have received a copy of the GNU General Public License
 *  along with this program.  If not, see <http://www.gnu.org/licenses/>.
 */

#include "application.hpp"
#include "driver/gpio.h"
#include "io.h"

extern "C" void app_main() {

  using namespace espena;

  static const char *NTP_DEFAULT_SERVER = "pool.ntp.org";
  static const char *NTP_DEFAULT_TIMEZONE = "CET-1CEST,M3.5.0,M10.5.0/3"; // Europe/Oslo

  /* Main configuration */
  application::configuration config = {

    .led_green = {
      .gpio_num = IO_LED_GREEN },

    .led_red = {
      .gpio_num = IO_LED_RED },
    
    .relay = {
      .gpio_relay = IO_RELAY },
    
    .sound = {
      .gpio_i2s_sd_mode = IO_I2S_SD_MODE,
      .gpio_i2s_bclk = IO_I2S_BCLK,
      .gpio_i2s_lrclk = IO_I2S_LRCLK,
      .gpio_i2s_dout = IO_I2S_DOUT },

    .sdcard = {
      .gpio_sdspi_mosi = IO_SDCARD_MOSI,
      .gpio_sdspi_miso = IO_SDCARD_MISO,
      .gpio_sdspi_cs = IO_SDCARD_CS,
      .gpio_sdspi_clk = IO_SDCARD_CLK,
      .gpio_sd_det = IO_SDCARD_DET,
      .sdspi_bus = {
        .slot = 1 },
      .sdspi_max_transfer_sz = 2000,
      .sdspi_dma_channel = 1,
      .mount_point = "/sdcard" },

    .rtc = {
      .gpio_sda = IO_I2C_SDA,
      .gpio_scl = IO_I2C_SCL },

    .ntp = {
      .server = NTP_DEFAULT_SERVER,
      .timezone = NTP_DEFAULT_TIMEZONE },

    .button_left = {
      .btn_id = 1,
      .gpio_button = IO_PANEL_S1_INPUT,
      .gpio_led = IO_PANEL_S1_RED },

    .button_right = {
      .btn_id = 2,
      .gpio_button = IO_PANEL_S2_INPUT,
      .gpio_led = IO_PANEL_S2_RED },

    .led_button_left = {
      .gpio_num = IO_PANEL_S1_RED },

    .led_button_right = {
      .gpio_num = IO_PANEL_S2_RED },

    .cron = {
      .crontab_file = "crontab.txt" },

    .mqtt = {
      .server = "mqtt://mqtt.espenandersen.no:1883",
      .cert_file = "mqtt.pem",
      .topic = "espena/doorbell" },

    .logger = {
      .filename = "door.log",
      .max_file_size_mb = 10 },

    .http_server = {
      .port = 8001 }

  };

  gpio_install_isr_service( 0 );
  application app( config );
  app.run();
}

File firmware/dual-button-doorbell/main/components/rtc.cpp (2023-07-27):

#include <memory.h>
#include <time.h>
#include <sys/time.h>
#include "rtc.hpp"
#include "driver/i2c.h"
#include "esp_log.h"
#include "../io.h"

using namespace espena::components;

const char *rtc::LOG_TAG = "rtc";

rtc::rtc( const rtc::configuration &config ) : m_config( config ) {
  save_current_timezone();
  memset( &m_i2c_config, 0x00, sizeof( m_i2c_config ) );
  m_i2c_config = {
    .mode = I2C_MODE_MASTER,
    .sda_io_num = config.gpio_sda,
    .scl_io_num = config.gpio_scl,
    .sda_pullup_en = GPIO_PULLUP_ENABLE,
    .scl_pullup_en = GPIO_PULLUP_ENABLE,
    .master = {
      .clk_speed = 400000
    },
    .clk_flags = 0
  };
  esp_err_t ret;
  ret = i2c_param_config( I2C_NUM_0, &m_i2c_config );
  if( ret == ESP_OK ) {
    ESP_LOGI( LOG_TAG, "Config OK!" );
  }
  else {
    ESP_LOGE( LOG_TAG, "Error in config" );
  }
  ret = i2c_driver_install( I2C_NUM_0, m_i2c_config.mode, 0, 0, 0 );
  if( ret == ESP_OK ) {
    ESP_LOGI( LOG_TAG, "Initialization OK!" );
  }
  else {
    ESP_LOGE( LOG_TAG, "Initialization failed." );
  }

}

rtc::~rtc() {
  
}

void rtc::sync_from_systime() {

  time_t t = time( NULL );
  tm *now = gmtime( &t );
  uint8_t data[ 7 ];

  data[ 0 ] = dec2bcd( now->tm_sec );
  data[ 1 ] = dec2bcd( now->tm_min );
  data[ 2 ] = dec2bcd( now->tm_hour );
  data[ 3 ] = dec2bcd( now->tm_wday );
  data[ 4 ] = dec2bcd( now->tm_mday );
  data[ 5 ] = dec2bcd( now->tm_mon );
  data[ 6 ] = dec2bcd( now->tm_year );

  i2c_cmd_handle_t cmd = i2c_cmd_link_create();
  i2c_master_start( cmd );
  i2c_master_write_byte( cmd, 0xd0, true );
  i2c_master_write_byte( cmd, 0x00, true );
  i2c_master_write( cmd, data, 7, true );
  i2c_master_stop( cmd );
  esp_err_t ret = i2c_master_cmd_begin( I2C_NUM_0, cmd, pdMS_TO_TICKS( 100 ) );
  if( ret != ESP_OK ) {
    ESP_LOGE( LOG_TAG, "Failed to execute commands" );
  }
  else {
    ESP_LOGI( LOG_TAG, "RTC synced from systime" );
  }
  i2c_cmd_link_delete( cmd );
}

void rtc::get_time( tm &rtc_tm ) {

  uint8_t data[ 7 ];
  memset( data, 0x00, sizeof( data ) );

  i2c_cmd_handle_t cmd = i2c_cmd_link_create();
  i2c_master_start( cmd );
  i2c_master_write_byte( cmd, 0xd0, true );
  i2c_master_write_byte( cmd, 0x00, true );
  i2c_master_start( cmd );
  i2c_master_write_byte( cmd, 0xd1, true );
  i2c_master_read( cmd, data, 7, I2C_MASTER_LAST_NACK );
  i2c_master_stop( cmd );
  esp_err_t ret = i2c_master_cmd_begin( I2C_NUM_0, cmd, pdMS_TO_TICKS( 1000 ) );
  if( ret != ESP_OK ) {
    ESP_LOGE( LOG_TAG, "Failed to execute commands" );
    return;
  }
  i2c_cmd_link_delete( cmd );

  rtc_tm.tm_sec = bcd2dec( data[ 0 ] );
  rtc_tm.tm_min = bcd2dec( data[ 1 ] );
  rtc_tm.tm_hour = bcd2dec( data[ 2 ] );
  rtc_tm.tm_wday = bcd2dec( data[ 3 ] );
  rtc_tm.tm_mday = bcd2dec( data[ 4 ] );
  rtc_tm.tm_mon = bcd2dec( data[ 5 ] );
  rtc_tm.tm_year = bcd2dec( data[ 6 ] );

}

void rtc::get_time_string( char *buf, size_t len, tm *t ) {
  memset( buf, 0x00, len );
  strftime( buf, len - 1, "%Y-%m-%d %H:%M:%S", t );
}

void rtc::save_current_timezone() {
  const char *tzutc = "UTC+0";
  const char *etz = getenv( "TZ" );
  strncpy( m_tz, etz ? etz : tzutc, sizeof( m_tz ) );
}

// Temporarily swap to UTC
void rtc::utc_push() {
  save_current_timezone();
  setenv( "TZ", "UTC+0", 1 );
  tzset();
}

// Go back to previous TZ
void rtc::utc_pop() {
  setenv( "TZ", m_tz, 1 );
  tzset();
}

void rtc::sync_to_systime() {
  utc_push();
  tm t;
  memset( &t, 0x00, sizeof( t ) );
  get_time( t );
  time_t rtctime = mktime( &t );
  char rtctimestr[ 100 ];
  get_time_string( rtctimestr, sizeof( rtctimestr ), &t );
  timeval tv = {
    .tv_sec = rtctime,
    .tv_usec = 0
  };
  settimeofday( &tv, NULL );
  utc_pop();
  ESP_LOGI( LOG_TAG, "System time adjusted (UTC %s)", rtctimestr );
}

void rtc::print_time() {
  tm rtctime;
  memset( &rtctime, 0x00, sizeof( rtctime ) );
  get_time( rtctime );
  char time_str[ 100 ];
  get_time_string( time_str, sizeof( time_str ), &rtctime );
  ESP_LOGI( LOG_TAG, "RTC time: %s", time_str );
}

uint8_t rtc::dec2bcd( uint8_t val ) {
  return ( ( val / 10 ) << 4 ) + ( val % 10 );
}

uint8_t rtc::bcd2dec( uint8_t val ) {
  return ( val >> 4 ) * 10 + ( val & 0x0f );
}

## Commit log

2023-05-21 Update annotations
    [door_bell.kicad_sch]
2023-05-22 Assign footprint for fuse
    [door_bell.kicad_sch]
2023-05-27 Part placement
    [door_bell.kicad_pcb, door_bell.kicad_sch]
2023-05-27 Part placement and silk screen adjustments
    [door_bell.kicad_pcb, door_bell.kicad_sch]
2023-05-27 Silk screen adjustments
    [door_bell.kicad_pcb]
2023-05-27 Adapting after placing 3D model of fuse F1
    [door_bell.kicad_pcb]
2023-05-27 Setting up footprints and 3D models
    [door_bell.kicad_pcb]
2023-05-27 Add PCB rendering to project description
2023-05-28 Update PCB with 3D model for ESP32
    [door_bell.kicad_pcb]
2023-05-28 Show both sides of PCB
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2023-05-28 Adjust layout
    [door_bell.kicad_pcb]
2023-05-28 Add 3D model for bridge rectifier
    [door_bell.kicad_pcb]
2023-05-29 Start routing power rails
    [door_bell.kicad_pcb]
2023-05-29 Rip-up and retry ...
    [door_bell.kicad_pcb]
2023-05-29 GND plane routing
    [door_bell.kicad_pcb, door_bell.kicad_sch]
2023-05-30 Initial routing of power rails and some signals
    [door_bell.kicad_pcb, door_bell.kicad_sch]
2023-05-30 Fix board outline in QCAD and re-import to KiCad
    [board_outline.dxf]
2023-05-30 Done routing
    [door_bell.kicad_pcb, door_bell.kicad_sch]
2023-05-31 Gerber files sent to JLCPCB
    [door_bell-B_Cu.gbr, door_bell-B_Mask.gbr, door_bell-B_Silkscreen.gbr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]
2023-05-31 Prototype finished, sent to production
    [door_bell.kicad_pcb]
2023-06-01 Add BOM with Mouser part references
    [door_bell.csv, door_bell.xlsx]
2023-06-01 Update BOM, add enclosure and speaker
    [door_bell.xlsx]
2023-06-01 Change to alternative voltage regulator types
    [door_bell.kicad_sch]
2023-06-03 Add 3D model of frontpanel back enclosure
    [frontpanel_enclosure.FCStd, frontpanel_enclosure.step]
2023-06-03 Add STL file
    [door_bell.kicad_pcb, frontpanel_enclosure.stl]
2023-06-03 Increase wall thickness to 2 mm
    [frontpanel_enclosure.FCStd, frontpanel_enclosure.step, frontpanel_enclosure.stl]
2023-06-03 Add ASCII STL to README
2023-06-11 Redraw, v.1.1 - fix errors
    [door_bell.kicad_pcb, door_bell.kicad_sch]
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2023-06-11 Reallocate pads for LEDS and Panel buttons
    [door_bell.kicad_sch]
2023-06-11 GPIO 39/36 is input only, swap with 21/25 from panel button inputs
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2023-06-18 Swap to C++, begin app structuring
    [door_bell.kicad_sch]
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2023-06-21 Update schematics, fix problems
    [door_bell.kicad_sch]
2023-06-21 Replace TVS diodes with larger type (SOD-923 -> SOD-523)
    [door_bell.kicad_sch]
2023-06-22 Rearrange i2s pin order to eliminate wire crossing
    [door_bell.kicad_sch]
2023-06-22 Fix errors in board outline
    [board_outline.dxf]
2023-06-22 Update PCB with amended board outline
    [door_bell.kicad_pcb]
2023-06-23 Add TVS diode and note on panel LED resistors
    [door_bell.kicad_sch]
2023-06-23 Change from IO2 to IO12 for relay
    [door_bell.kicad_sch]
2023-06-24 Fix problem with WDT triggering during playback
    [io.h, sound.cpp]
2023-06-24 Reset PCB and remake component placement
    [door_bell.kicad_pcb, door_bell.kicad_sch]
2023-06-24 Routing GND plane
    [door_bell.kicad_pcb, door_bell.kicad_sch]
2023-06-24 Routing power plane
    [door_bell.kicad_pcb]
2023-06-25 Routing complete
    [door_bell.kicad_pcb]
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2023-06-25 Revision 1.1 plotted and sent to factory
    [door_bell-B_Cu.gbr, door_bell-B_Mask.gbr, door_bell-B_Silkscreen.gbr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]
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2023-06-27 Empty position in UART header to block connector if accidentially reversed
    [door_bell.kicad_pcb, door_bell.kicad_sch]
2023-06-27 Re-route connections to UART pin header
    [door_bell.kicad_pcb]
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2023-06-27 Move traces away from hole
    [door_bell.kicad_pcb]
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2023-06-28 Correct implementation of WAV header
    [sound.cpp]
2023-07-02 Correct text tag for UART
    [door_bell.kicad_sch]
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2023-07-05 Set up proper partition table
    [partitions.csv]
2023-07-05 Workaround for memory leak bug in setenv() for ESP32
2023-07-05 Custom partition table (WROVER has 4MB memory)
    [partitions.csv]
2023-07-06 Fix concurrency issue with playback
    [sound.cpp]
2023-07-07 Change TVS diodes for SD card to unipolar ones
    [door_bell.kicad_sch]
2023-07-07 Update BOM to version 1.1
    [door_bell.xlsx]
2023-07-07 Adjust labels
    [door_bell.kicad_sch]
2023-07-10 Let C9 return to GND, increase i2c pullups R5/R6
    [door_bell.kicad_sch]
2023-07-10 PCB serial no longer corresponds to current schematic
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2023-07-10 Connect DS3231 interrupt line
    [door_bell.kicad_sch]
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2023-07-10 Add decoupling for SD card
    [door_bell.kicad_sch]
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2023-07-15 Add connection diagram to panel terminal block
    [door_bell.kicad_sch]
2023-07-15 Change input voltage specification
    [door_bell.kicad_sch]
2023-07-17 Remove leftover no-connection flag
    [door_bell.kicad_sch]
2023-07-17 Update date
    [door_bell.kicad_sch]
2023-07-17 Free cert buffer before allocating, in case get_cert() is called multiple times
2023-07-17 Update BOM with price per assembly
    [door_bell.xlsx]
2023-07-17 Nudge i2c pullups a bit
    [door_bell.kicad_sch]
2023-07-21 Downscale fuse to 500 mA slow-blow after tests
    [door_bell.kicad_sch]
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2023-07-27 Continuous red button light when in silent mode
2023-07-31 Downscale fuse F1 to 250 mA after testing
    [door_bell.kicad_sch]
2023-08-11 PCB artwork for version 1.2
    Implementing changes for new version. Added two decoupling capacitors to SD card, improved thermal relief for 5V regulator and connected RTC _INT/SQW pin from RTC. Copper pours on outer layers.
    [door_bell.kicad_pcb, door_bell.kicad_sch]
2023-08-11 Improve heat sink on 5V regulator
    [door_bell.kicad_pcb]
2023-08-11 Add thermal vias to 3v3 regulator
    [door_bell.kicad_pcb]
2023-08-12 Plots and drill file for v 1.2
    [door_bell-B_Cu.gbr, door_bell-B_Mask.gbr, door_bell-B_Silkscreen.gbr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]
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2023-08-24 Add heatsink to 5V regulator
    [door_bell.kicad_pcb, door_bell.kicad_sch]
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2023-08-24 Add 'hot surface' symbol to 5V regulator
    [door_bell.kicad_sch]
2023-08-24 Change 5V regulator footprint to dual-heatsink
    [door_bell.kicad_pcb]
2023-08-25 Display values for decoupling capacitors
    [door_bell.kicad_sch]
2023-08-27 Change C10 to non-polarized
    [door_bell.kicad_sch]

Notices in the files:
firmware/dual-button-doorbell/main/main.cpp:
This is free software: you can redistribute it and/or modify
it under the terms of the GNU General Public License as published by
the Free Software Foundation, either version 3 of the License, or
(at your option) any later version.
